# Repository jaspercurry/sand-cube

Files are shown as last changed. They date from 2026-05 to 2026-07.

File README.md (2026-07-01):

# Sand Cube

An AI-assisted, code-CAD speaker enclosure project for an 8 inch FDM-printed,
sand-filled cube using a Dayton Audio Epique E150HE-44 driver and a matching
Epique passive radiator.

This repo is intentionally starting with research and parameters before full
geometry. The goal is to keep every CAD dimension tied to a source, a fit test,
or a measured print.

## Current State

- Research validation notes live in `docs/RESEARCH_VALIDATION.md`.
- CAD import/debugging notes live in `docs/CAD_TROUBLESHOOTING.md`.
- Compact 6 in speaker notes live in `docs/COMPACT_6IN_SPEAKER.md`.
- Shared dimensions live in `params.py`.
- Build123d/Codex working rules live in `AGENTS.md`.
- Current 8.5 in enclosure API lives in `src/final_enclosure.py`.
- Current JMLC horn API lives in `src/final_horn.py`.
- Reusable horn and bracket geometry lives under `src/features/`.
- Archived 203 mm enclosure code lives in `archive/old_enclosure.py`.

## Build Current Enclosure

```bash
uv run python scripts/generate_final_enclosure.py
```

Outputs are written to `build/sand_cube_8_5_black_hole/contoured_inner/`:

- `sand_cube_8_5_black_hole_final_enclosure.step`
- `sand_cube_8_5_black_hole_final_enclosure_with_heat_set_inserts.step`
- `sand_cube_8_5_black_hole_final_enclosure_with_inserts_pr_gx16.step`
- `sand_cube_8_5_black_hole_final_complete_assembly.step`

## Build Full System

```bash
uv run python scripts/generate_final_system_assembly.py
```

Outputs are written to `build/final_system/`:

- `final_jmlc_horn_placed.step`
- `final_horn_bracket_4mm_folded.step`
- `final_binding_post_tpu_grommet.step`
- `final_horn_bracket_de250_stack.step`
- `final_sand_cube_horn_system.step`
- `final_system_notes.json`

## Build Compact 6 In Speaker

```bash
uv run python scripts/generate_compact_6in.py
```

Outputs are written to `build/compact_6in/`:

- `compact_6in_one_piece_enclosure.step`
- `compact_6in_f110m_jmlc_horn.step`
- `compact_6in_f110m_fit_envelope.step`
- `compact_6in_f110m_jmlc_horn_placed.step`
- `compact_6in_horn_f110m_fit_stack.step`
- `compact_6in_system_preview.step`
- `diagnostics.json`

## Build Archived 203 mm Enclosure

```bash
uv run python scripts/generate_archive_old_enclosure.py
```

Outputs are written to `build/archive/old_enclosure/`. This path is for
comparison and reproducibility; new assembly work should use the 8.5 in final
enclosure scripts above.

## View Locally

The repo has two local viewing workflows:

- **OCP CAD Viewer** for live build123d geometry and quick STEP inspection.
- **Open STEP Viewer** or another desktop STEP viewer for exact exported STEP
  review with measurements and section planes before uploading to Onshape.

### OCP CAD Viewer

Install the recommended VS Code extension:

```bash
code --install-extension bernhard-42.ocp-cad-viewer
```

Then start the OCP CAD Viewer from the VS Code/Cursor sidebar. With the viewer
running, show the current final enclosure:

```bash
bash scripts/view_model.sh
```

Useful targets:

```bash
# List available live-geometry and exported-STEP targets
bash scripts/view_model.sh --list

# Show all final enclosure export bodies in one viewer scene
bash scripts/view_model.sh --target final-enclosure-exports

# Show the standalone JMLC horn
bash scripts/view_model.sh --target final-horn

# Import and show the most recently generated STEP under build/
bash scripts/view_model.sh --latest-step --tab clip

# Import a specific STEP file back through OpenCASCADE
bash scripts/view_model.sh build/final_system/final_sand_cube_horn_system.step
```

Inside OCP CAD Viewer, use the **Measure** tools for distances/properties and
the **Clip** tab for section-plane inspection. The script starts in properties
mode by default; pass `--tool distance` to start in distance measurement mode.

### Exported STEP Review

For fast local review of the exact STEP files, install
[Open STEP Viewer](https://openstepviewer.com/) or another desktop STEP viewer
such as FreeCAD/CAD Assistant. The most useful project files to inspect are:

- `build/sand_cube_8_5_black_hole/contoured_inner/`
  `sand_cube_8_5_black_hole_final_complete_assembly.step`
- `build/final_system/final_sand_cube_horn_system.step`
- `build/final_system/final_horn_bracket_de250_stack.step`

Use the desktop viewer for measurements, section planes, and quick import sanity
checks; keep Onshape as the final check for risky horn/adapter topology.

## Render Local PNG Previews

For cleaner renders than the fallback Matplotlib preview, install `f3d` and run:

```bash
bash scripts/render_f3d_previews.sh
```

The PNG files are written to `previews/`.

## Planned Stack

- Python 3.12
- build123d
- bd_warehouse
- OCP CAD Viewer
- Codex as the implementation agent

## First Milestone

Continue consolidating the final geometry out of experiments:

1. Move the 8.5 in enclosure implementation behind smaller feature modules.
2. Keep `experiments/` for visual/profile studies only.
3. Keep current production exports in `scripts/generate_final_*.py`.
4. Add any future hardware placement helpers under `src/`.

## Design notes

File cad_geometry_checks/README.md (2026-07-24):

# CAD geometry checks

`cad_geometry_checks` contains model-independent measurement implementations
that produce immutable results and can feed the existing `cad_verification`
contract. It does not define contracts, policies, evidence packets, model
dimensions, or a second schema.

The package root is native-free. Import `cad_geometry_checks.native` explicitly
inside a `cad_runner` worker to measure Build123d/OCP objects. The native
boundary is duck-typed and delays all kernel ownership to its caller, so
lightweight semantic tests can use fake objects without initializing CAD
libraries.

Every result records:

- the `cad_verification.Unit` for each value;
- named, unit-bearing tolerances;
- an operational diagnostic status;
- a machine-readable failure reason when the result is unusable; and
- a detailed diagnostic suitable for a review packet measurement.

Intersection results additionally preserve the exact Boolean outcome:
bounding-box disjoint, no returned shape, explicit empty shape, zero-volume
contact, positive-volume intersection, or invalid/unexpected topology.
Callers must inspect that outcome before consuming the volume. A missing or
empty member of a multi-solid Boolean fails the whole measurement closed;
partial positive results are never reported as complete.

Collection volume, difference, intersection, and protected-material results use
the geometric material union, so duplicate or overlapping solids are not
double-counted. Topology edge adjacency is occurrence-aware for periodic seams.
Protected-surface comparison samples tessellated topological interiors and trim
boundaries rather than the untrimmed UV rectangle. Edge signatures have
separate millimeter and dimensionless tangent tolerances. Normal change is an
unoriented tangent-plane measurement: opposite normals intentionally compare as
zero degrees.

Frozen normalization results own an immutable tuple, but the native shapes
inside it are borrowed mutable kernel objects. Callers must not mutate those
objects during a measurement.

The coordinated synthetic suite is
`tests/fixtures/cad_geometry_checks_native_fixtures.py`. Its direct entry point
self-routes through `cad_runner` before importing Build123d. It writes only an
ignored diagnostic report under `build/cad-geometry-checks/`.

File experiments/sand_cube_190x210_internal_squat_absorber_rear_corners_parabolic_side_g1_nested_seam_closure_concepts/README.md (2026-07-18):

# Nested-seam closure concepts

This isolated experiment preserves the exact unsplit parabolic enclosure as
the authoritative assembled exterior.  The baffle plug steps inward behind
the original tangent seam, while the bucket retains a continuous outer lip
that conceals the mating taper.  A 0.28 mm hidden fit allowance separates the
socket surfaces, and the existing continuous 5 mm wide, 2 mm thick foam gasket
remains farther inside.

It compares four lower retention concepts while retaining the two hidden top
hooks:

- two concealed 4.8 mm zip-tie loops through sealed dry-side saddles, with the
  tie heads recessed flush into the underside;
- two sacrificial zip latches: each baffle captures an intact tie head, its
  tail runs through a roofed floor tunnel, and a replaceable second ratchet
  head sits in a flush underside clipping pocket;
- two open underside M4 bolt/nut channels, with hardware captured behind
  opposing bucket and baffle collars;
- two reinforced 45 degree dry-side pocket screws with a modeled sealant or
  O-ring annulus at each underside entry.

The loop, bolt, and pocket-screw passages remain ahead of the gasket plane.
The longer sacrificial-latch tail tunnel stays below the gasket loop and has a
modeled 2 mm sealed roof separating it from the enclosure air.  Neither path
crosses the compressed foam seal.

These are mechanism concepts, not final hardware contracts.  Purchased zip
ties, bolts, nuts, inserts, and tool-access dimensions still require fit
coupons before printing a complete enclosure.

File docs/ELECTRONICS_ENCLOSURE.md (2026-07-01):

# Electronics Enclosure

This documents the focused electronics enclosure layout for the hidden
Raspberry Pi 5, DAC HAT, four-channel amp, rear-mounted buck converter, and
rear service connectors.

The active CAD lives in `src/features/electronics.py` as the
`thin_plate_inline_separate_mic` variant. Earlier broad layout studies are
kept in the same file but are archived by `active_layout_variants()`.

## Active Layout

- Overall outside envelope: `166 x 124 x 60 mm`.
- Main box height: `57 mm`; screw-on lid thickness: `3 mm`.
- Orientation convention: the rear service face is `+Y`.
- When facing the rear:
  - Raspberry Pi rear USB/Ethernet ports are on the right.
  - Amplifier and GX outputs are on the left.
  - Buck converter mounts vertically on the outside rear face.
  - Microphone is intentionally external/separate for this iteration.

The active placement is a thin hidden plate intended to fit on a 256 mm square
printer bed while keeping the hardware accessible from the rear face.

## Component Fit

### Amplifier

- Active footprint: `94 x 108 mm`, rotated so the amp heat sink runs
  front-to-back, perpendicular to the rear service face.
- Clearance height: `36 mm`.
- Mounting rectangle:
  - Long axis center-to-center: `101.7 mm`.
  - Narrow axis center-to-center: `88.0 mm`.
  - Hole diameter assumption: `3.0 mm`.
- Printed stand-offs are `3 mm` tall for the current fit pass.

### Raspberry Pi 5 and HAT

- Pi service envelope in this enclosure: `56 x 90 x 42 mm`.
- Pi uses four front-to-back adjustment slots in the floor rather than fixed
  posts. This allows the real board/feet to slide until the USB/Ethernet faces
  land correctly in the rear openings.
- Rear I/O is split into three smaller bays instead of one large bridge:
  - left USB stack
  - middle USB stack
  - Ethernet
- A `10.83 mm` power input hole sits above the Pi rear I/O group, with slight
  vertical relief for FDM ovaling.

The Pi board dimensions and mounting pattern were based on Raspberry Pi 5 and
HAT mechanical drawings. The port windows remain fit-study geometry until the
real Pi/HAT stack and cable overmolds are validated.

### Buck Converter

- Rear-mounted vertical body envelope: `62 x 21 x 58 mm`.
- Rear locating pins:
  - Diameter: `5.8 mm`.
  - Projection depth: `4.0 mm`.
  - Center-to-center spacing: `53.67 mm`.
  - Pin center height: `29.0 mm` above the bottom of the buck body/enclosure.
- Bottom rear wire entry:
  - Width: `17.0 mm`.
  - Height: `3.0 mm`.
  - Through depth: wall thickness plus `5.0 mm`.
  - Internal chamfer: `6 x 6 mm` to reduce wire pinching.

### GX Outputs

- Two GX14-style four-pin output connectors provide four amp channels total.
- Through cutout size: `14.8 x 15.8 mm`.
- Recess size for the measured collar: `19.0 x 19.8 mm`.
- Measured collar OD: `18.06 mm`.
- Recess depth: `1.2 mm`.
- Centers are packed between the rear-mounted buck body and the rear-view left
  inner sidewall to reduce heat-sink interference risk.

## Lid and Printing Details

- Lid is a separate part with four recessed cheese-head screw holes.
- The base has four corner screw receivers:
  - Boss OD: `10.0 mm`.
  - Self-tap pilot diameter: `2.5 mm`.
  - Screw engagement: `2.0 mm`.
  - The receiver uses a short lofted, wall-grown ramp so it does not need full
    height pillars down to the floor.
- Top, side, front, and bottom vents use small print-friendly openings instead
  of long unsupported bridges.
- The fast-fit print variant thins walls/floor/lid to `1.6 mm` and uses a
  faster suggested PLA profile for layout validation.

## Generated Files

Generated CAD and 3MF files are written under `build/electronics_enclosure/`.
`build/` is ignored by git, so regenerate these files after cloning or after
geometry changes.

Main printable 3MF exports:

- `build/electronics_enclosure/thin_plate_inline_separate_mic_base_with_standoffs.3mf`
- `build/electronics_enclosure/thin_plate_inline_separate_mic_screw_on_lid.3mf`
- `build/electronics_enclosure/thin_plate_inline_separate_mic_fast_fit_base.3mf`
- `build/electronics_enclosure/thin_plate_inline_separate_mic_fast_fit_lid.3mf`

STEP exports for inspection:

- `build/electronics_enclosure/thin_plate_inline_separate_mic_printed_enclosure.step`
- `build/electronics_enclosure/thin_plate_inline_separate_mic_electronics_assembly.step`
- `build/electronics_enclosure/thin_plate_inline_separate_mic_base_with_standoffs.step`
- `build/electronics_enclosure/thin_plate_inline_separate_mic_screw_on_lid.step`

## Commands

Generate STEP/layout study files:

```bash
python scripts/generate_electronics_enclosure_layouts.py
```

Generate printable 3MF files:

```bash
python scripts/generate_electronics_3mf.py
```

Open the normal OCP CAD viewer target with the lid separated:

```bash
bash scripts/view_model.sh --target electronics-open-lid --tool distance --tab tree
```

## Open Fit Items

- Validate the Pi rear I/O vertical position with the real removable feet.
- Replace the Pi floor slots with fixed screw holes after the fit position is
  known.
- Re-check GX connector fit after printing because rear-wall circular holes can
  print slightly undersized or oval.
- Validate buck converter noise and wire routing near the amp before treating
  the rear-mounted buck position as final.
- If Bambu Studio reports floating regions, first check the short horizontal
  rear buck pins. They are connected to the rear wall but can look like tiny
  cantilevers to a slicer.

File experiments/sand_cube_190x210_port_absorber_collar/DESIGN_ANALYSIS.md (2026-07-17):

# Project-specific absorber-collar analysis

## Result in one sentence

Use a removable four-sector Helmholtz collar provisionally tuned to 345 Hz at
the lowest accessible part of the straight external tower, begin with all four
chambers identical and damped toward Q=0.75-1, and let the untreated-port
measurement set the final aperture diameters.

The 380 Hz value in the background documents is not used.

## 1. Current port and the unwanted modes

The current round-port experiment gives:

| Quantity | Value |
|---|---:|
| Main bore diameter | 39.2428 mm |
| Main bore area | 1,209.51 mm2 |
| Physical centerline length | 491.369 mm |
| Reported low-frequency effective length | 518.540 mm |
| Net enclosure volume | 4.57012 L |
| Bass-reflex tuning | 39.00 Hz |

The 39 Hz box/port resonance and the unwanted midrange pipe resonances are
different physical modes. The 39 Hz calculation reduces the port air to a
lumped inertance. A longitudinal mode requires distributed acoustic mass and
compliance along the duct.

The simplest open-open estimate is:

```text
f_n = n c / (2 L)
```

With c=343 m/s and the physical centerline, this gives 349.0, 698.0, 1047.1,
and 1396.1 Hz. Reusing the 518.540 mm low-frequency inertance length gives
330.7, 661.5, 992.2, and 1322.9 Hz. The latter is a useful lower bracket, not a
phase-accurate prediction.

The generator also cascades plane-wave transfer matrices for the physical
inlet flare, constant-area path, and outlet flare:

```text
             [ cos(kl)       j Zc sin(kl) ]
T_segment =  [                              ]
             [ j sin(kl)/Zc      cos(kl)   ]

Zc = rho c / S
```

It terminates the mouth with a low-ka unflanged radiation approximation. That
model predicts untreated peaks near 350.5, 700.0, 1048, and 1394 Hz. A variant
including a finite inlet spreading mass predicts about 344, 681, and 1019 Hz.
Both exclude driver electro-mechanics, detailed bend fields, thermoviscous
propagation, and flexible printed walls.

The defensible pre-measurement conclusion is therefore:

- search approximately 315-365 Hz for the first port mode;
- use 345 Hz as the mechanical prototype center;
- expect a second port feature around 0.66-0.70 kHz; and
- do not assume a 0.99-1.05 kHz feature is only the port.

The enclosure's first simple axial estimates are about 933 Hz in depth and
974 Hz in width/height, overlapping the third port band. Printed-wall radiation
can further confuse that region. The circular duct's first transverse cutoff
is around 5.1 kHz, so a 1D longitudinal model is appropriate for the bands of
interest even though the bends still perturb it.

## 2. Absorber equations

Each chamber is represented as a series acoustic RLC branch connected in shunt
to the main duct:

```text
Z_H = R_H + j (omega M_H - 1/(omega C_H))
Y_total = sum(1/Z_H,i)

M_H = rho Leff / A
C_H = V / (rho c^2)
f_H = c/(2 pi) sqrt(A/(V Leff))
```

The shunt transfer matrix is:

```text
      [ 1   0 ]
T_H = [       ]
      [ Y   1 ]
```

For a series resonator:

```text
Q = omega_H M_H / R_H = sqrt(M_H/C_H) / R_H
R_H = sqrt(M_H/C_H) / Q
```

The final relation is important: Q is in the denominator. The thesis prints
one equation with Q inverted, but its later numerical examples use the inverse
relationship above.

Four identical chambers have four admittances in parallel. If their volumes,
areas, and losses are equal, their center frequency remains unchanged while
their total shunt strength increases.

## 3. Neck length and end correction

The physical neck is 8.0 mm long and grows only outward from the unchanged
39.243 mm bore. For a small circular aperture in a locally planar wall, the
first estimate is:

```text
Leff = t + delta_duct + delta_cavity
delta_duct = 0.85 r
delta_cavity = 0.85 r
Leff = t + 0.85 d
```

The actual opening is flush in a curved finite duct and enters a sector-shaped
cavity rather than two infinite half-spaces. No transferable correction for
that exact geometry was found in the thesis. The generator therefore carries:

```text
Leff = t + beta d,  beta = 0.85 nominal, 0.70-1.00 sensitivity range
```

The neck radius is about 10% of the main-port radius, so local planarity is a
reasonable starting assumption, but measurement is still required.

## 4. Provisional dimensions

The generated default is:

| Feature | Nominal value |
|---|---:|
| Collar outside diameter | 100.0 mm |
| Axial length | 30.0 mm |
| Unchanged main bore | 39.2428 mm |
| Existing tower wall | 5.0 mm |
| Local physical neck/liner | 8.0 mm |
| Outer wall | 3.0 mm |
| Integral chamber floor | 3.0 mm |
| Bonded lid | 3.0 mm |
| Radial dividers | 2.4 mm |
| Chamber count | 4 |
| Gross volume per chamber | 26.141 cm3 |
| Damping displacement allowance | 0.250 cm3 |
| Net acoustic volume per chamber | 25.891 cm3 |
| Target per chamber | 345.0 Hz |
| Solved round neck diameter | 3.853 mm |
| Neck area per chamber | 11.659 mm2 |
| Effective neck length | 11.275 mm |
| Total neck area / main port area | 3.86% |

For each chamber at c=343 m/s and rho=1.204 kg/m3:

```text
M_H = 1164.3 Pa s2/m3
C_H = 1.8278e-10 m5/N
R_H(Q=1) = 2.524 MPa s/m3
R_H(Q=0.75) = 3.365 MPa s/m3
```

The numerical values in `diagnostics.json` come from the actual CAD cavity
volumes rather than an ideal annular-volume approximation.

## 5. Why four equal chambers first

| Architecture | Benefit | Drawback | Decision |
|---|---|---|---|
| One shared annular cavity | Maximum volume, few dividers | One leak or print defect compromises everything; no tuning experiments | Rejected for prototype |
| Four identical sectors | Maximum first-mode shunt strength; inspectable and fault-isolated | Requires a bonded divider seal | Selected |
| Four blindly staggered sectors | Broader nominal frequency coverage | Less admittance at the measured peak; may create shoulders | Defer until measurement |
| Two axial collars | Can address even and odd modes at their own antinodes | More volume, joints, flow openings, and mechanical complexity | Only if one location cannot solve measured modes |
| Membrane chambers | Potentially compact | Printed stiffness and boundary conditions make tuning unreliable | Rejected |

The thesis' coupled simulation favored absorber Q around 0.75-1. An isolated
resonator at Q=1 is already broad; the coupled notch width is not simply the
isolated resonator's -3 dB width. Staggering before measuring the untreated
port would trade away useful peak coupling based on an assumed problem.

The four sectors preserve the option to test a 2+2 split near 0.97f1 and
1.03f1. If the second mode remains objectionable, a separate smaller chamber
near f2 is preferable to giving a full 26 cm3 sector an unnecessarily large
opening.

## 6. Placement

The first-mode pressure maximum is near the acoustic midpoint, around 246 mm
from the inlet in the current TMM. That location lies in the curved upper
return with poor radial clearance.

The collar is instead centered 358.26 mm from the inlet, corresponding to
global z=110 mm and a z=95-125 mm span on the straight external tower. The
calculated pressure ratios relative to each mode's own maximum are:

| Mode | Bare modeled peak | Pressure at collar |
|---|---:|---:|
| First | 350.5 Hz | 0.752 (-2.47 dB) |
| Second | 700.0 Hz | 0.991 (-0.08 dB) |
| Third | 1048 Hz | 0.546 (-5.26 dB) |

This is a useful compromise: strong first-mode coupling, almost ideal
second-mode coupling, a straight printable host, access for testing, no
enclosure displacement, and clearance below the DE250 envelope.

## 7. Predicted effect and what not to overclaim

With four ideal Q=1 branches at 345 Hz, the lossless TMM predicts about 32 dB
reduction at its untreated first peak and about 19 dB at its untreated second
peak. It also shifts the residual response maxima because a resonant shunt
splits and reshapes the duct response.

Those are design-model numbers, not promised measurements. The model does not
include real duct loss, neck nonlinearity, mesh repeatability, bend scattering,
driver coupling, wall vibration, or cabinet radiation. Hildebrandt measured
about 19 dB attributable suppression in the cleaner configuration, which is a
better reality check than the ideal 32 dB result.

The same model moves the low-frequency coupled peak from about 39.28 to
39.25 Hz, a -0.03 Hz relative shift. The exact driver/port system still needs
an impedance and nearfield check, and 39 Hz output must be compared as well as
the frequency.

External placement displaces no box air. If this 100x30 mm envelope were put
inside around the existing 49.243 mm tower, its added gross envelope would
remove about 178.5 cm3 from the 4.570 L enclosure. Ignoring side-branch
compliance, that alone would move 39.00 Hz to roughly 39.78 Hz. An internal
version therefore requires complete volume and tuning recalculation.

## 8. Tolerances

For small changes:

```text
df/f ~= dc/c + dd/d - 0.5 dV/V - 0.5 dLeff/Leff
```

Because Leff also contains diameter-dependent end correction, the generator
recalculates rather than using only this differential approximation.

| Change from nominal | Predicted fH |
|---|---:|
| Neck diameter -0.15 mm | 333.46 Hz |
| Neck diameter +0.15 mm | 356.42 Hz |
| Physical neck -0.20 mm | 348.10 Hz |
| Physical neck +0.20 mm | 341.98 Hz |
| Cavity volume -5% | 353.96 Hz |
| Cavity volume +5% | 336.69 Hz |
| Speed of sound 340.3 m/s | 342.28 Hz |
| Speed of sound 349.0 m/s | 351.03 Hz |
| End beta=0.70 | 354.20 Hz |
| End beta=1.00 | 336.48 Hz |

Diameter and end correction dominate. Print the opening slightly undersize and
finish it with a measured drill or reamer. A controlled +/-0.05 mm aperture is
more useful than false precision in the CAD nominal.

## 9. Leakage and damping

Treat a cavity leak resistance as parallel with cavity compliance. Keeping the
compliance error near resonance below roughly 5% requires:

```text
omega R_leak C_H > 20
```

For one generated chamber this gives R_leak greater than about 50.5 MPa s/m3,
or a plugged-neck pressure-decay time:

```text
tau = R_leak C_H > 9.23 ms
```

The practical target is at least 50 ms for margin. Test each chamber before
installing it. A leak with its own inertance can also create an unintended
second resonance, so a visibly closed seam is not enough evidence.

Use a captured woven polyester acoustic mesh or another repeatable resistive
fabric on the cavity side of each neck. Bond its perimeter so no fiber can
reach the main airway. Do not loosely stuff the whole chamber: bulk fill alters
effective volume/compliance as well as resistance. The acoustic resistance
must be inferred from the measured collar Q; cloth type and layer count are
calibration variables.

## 10. Measurement-driven finalization

1. Measure the untreated mouth 5-10 mm away with a low-level 20-2000 Hz sweep.
2. Add a temporary 20 mm outlet extension. A 345 Hz pipe mode should fall by
   approximately 3-4%, while a cabinet or panel mode should not track length.
3. Measure electrical impedance and port nearfield together to confirm 39 Hz.
4. Fit the distributed model to measured f1, f2, and their widths.
5. Test four undamped equal chambers first to establish the real collar center.
6. Correct frequency by measured aperture diameter or cavity-volume plugs.
7. Add captured mesh incrementally and fit R_H/Q from the response and decay.
8. Test 2+2 staggering only if the untreated or residual band is broad.
9. Recheck box tuning, 39 Hz level, resonance decay, and electrical impedance.
10. Increase level in steps to expose neck turbulence, nonlinear resistance,
    distortion, compression, or resonance shift.

## References

- [Malte Hildebrandt, *Dämpfung stehender Wellen in Bassreflexrohren* (2024)](https://reposit.haw-hamburg.de/bitstream/20.500.12738/16061/1/BA_D%C3%A4mpfung_stehender_Wellen.pdf)
- [U. Ingard, *On the Theory and Design of Acoustic Resonators*](https://doi.org/10.1121/1.1907235)
- [H. Levine and J. Schwinger, *On the Radiation of Sound from an Unflanged Circular Pipe*](https://doi.org/10.1103/PhysRev.73.383)
- [M. R. Stinson, *The Propagation of Plane Sound Waves in Narrow and Wide Circular Tubes*](https://doi.org/10.1121/1.400379)

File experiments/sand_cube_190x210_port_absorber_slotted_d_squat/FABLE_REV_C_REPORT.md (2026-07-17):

# Fable independent analysis — Rev. C (preserved source report)

> **Provenance and status:** This report was generated independently with
> Fable and supplied by Jasper Curry. It is preserved substantially verbatim as
> an external analysis. It is an important input to the project, not the
> canonical design authority. Numerical claims become canonical only after they
> are reproduced by the repository models and reconciled with measurement.
>
> The four scripts named near the end of the supplied report were not included
> with the source text. This repository is independently implementing auditable
> versions of those models and will not assume their unpublished results.

# Port-Mode Slit Absorber — Independent Analysis & Design Rules (Rev. C)

Independent third opinion, with my own numerical models (full thermoviscous slit impedance validated against the Poiseuille and 6/5-mass-factor limits, plus a 1D transmission-line model of the actual 513.6 mm port with the branch inserted) and two verification research passes (end-correction literature incl. the open-access Aulitto TU/e thesis and the Hildebrandt PDF read directly; micro-tooling market survey).

---

## 1. The verdict, and the one thing both previous documents missed

**Build it as drawn. But the reason it will work is not the reason either document gave.**

Both Rev. A and Rev. B modeled the slit as a nearly-lossless mass (the "Q = 3.62 boundary-layer trend") and then argued about how precisely you must tune it. When you solve the **full thermoviscous channel impedance** for a 0.40 mm × 5 mm-deep passage at w/δᵥ = 3.35, two things change:

1. **The oscillating air in the channel is ~19% heavier than bulk air** (Re(ρ_eff)/ρ = 1.193 at 335 Hz — a standard result of the parallel-plate Crandall/Maa solution, which neither document applied to the mass term). The as-drawn part therefore tunes near **292–309 Hz**, not 334.7 Hz, before any end-correction argument even starts.
2. **The channel resistance is roughly twice the duct's characteristic impedance** (R_branch ≈ 6.7×10⁵ Pa·s/m³ vs Z₀ = ρc/S_duct = 3.3×10⁵). Intrinsic branch Q ≈ **2.0–2.2**, not 3.6.

That second point flips the whole engineering posture. At R/Z₀ ≈ 2 the absorber is a **heavily damped side-branch damper**, not a sharp notch filter. Its own bandwidth is ~165 Hz. My duct simulation (branch at the antinode, mode at ~331 Hz) shows:

| Branch condition | Worst residual peak vs bare mode |
|---|---|
| Perfectly tuned, as-drawn R | −25.6 dB |
| Detuned **−10%** | −25.8 dB |
| Detuned +10% | −22.3 dB |
| **Built exactly as drawn, zero tuning** (f₀ lands 292–309 Hz vs mode 331) | **−25 to −27 dB** |
| Slit width anywhere 0.35–0.50 mm (V untouched) | −23.4 to −25.9 dB |
| Edges fully rounded vs ideally sharp | −25.8 vs −25.9 dB (no difference) |
| Placed at the tower (x = 400 mm) instead of the antinode | −23.1 dB |

Re-run with 4× wall losses (bare mode Q ≈ 27, more like a real bent port): everything compresses to −14…−17 dB but the *flatness* is identical — as-built no-tuning is still within ~1 dB of perfectly tuned, and width 0.35–0.50 mm still all works. (Absolute dB values are comparative — my 1D model straightens the bends and ignores 3D effects — but the flatness conclusions depend only on R/Z₀ and the branch bandwidth, which are robust.)

**Consequences, stated bluntly:**

- The **irreversible-tuning anxiety is over-engineered**. Rev. B's displacement-plug system, Rev. A's "measure-then-lengthen" ritual, the ±0.03 mm feeler-gauge metrology, the sharp-edge "build requirement" — all of these solve a precision problem this design does not have. Deep channel (t/w = 12.5) + low porosity put you on a **flat plateau** roughly ±12% wide in frequency and ±0.07 mm wide in slit width.
- Rev. B's "print the bucket at 62 cm³ and plug down" points the **wrong direction anyway**: viscous mass loading plus the larger slit end correction mean the as-drawn part lands *low*. If you tune at all, you'll be *removing* volume (raising f₀), so the drawn 53.3 cm³ is already the "oversized" end of the range. My solve for exact tuning to 335 Hz gives V ≈ **40–46 cm³** depending on the end-correction scenario.
- Rev. B's sharp-edge obsession is misplaced *for this geometry*: the resistive end correction (Aulitto fit: 0.425·w ≈ 0.17 mm per side) is ~7% of the 5 mm channel's distributed resistance. Edge condition matters enormously for thin plates (t ≈ w); it is nearly irrelevant at t = 12.5w. Don't butcher the edges, but don't build a religion around them.
- Rev. B's Q-correction ("higher Q = deeper notch, so Q 3.6 is fine") is right about notch depth and wrong about what you should optimize. The correct objective is **worst residual peak**, and it's maximized at R/Z₀ ≈ 1.5–3 (my sweep: −25.6 dB at R/Z₀ = 2–3, degrading to −13.8 dB at R/Z₀ = 0.3 because the mode splits into two lightly-damped shoulders, and to −20 dB at R/Z₀ = 6 because the branch stops accepting flow). **The drawn design happens to sit at the optimum.** That is the single luckiest — or best — feature of this design.

---

## 2. The design rules you asked for

These are the formulas to size any future variant, with validity limits.

**Rule 1 — Resistance target (the master rule).**
Size the slits so that at resonance

> **R_branch / Z₀ ≈ 1.5–3**, where Z₀ = ρc/S_duct (= 3.29×10⁵ Pa·s/m³ for your 40 mm bore)

R_branch = Re[jωρ_eff·t/S_total]·(1 + 2δ_res/t), with the full parallel-plate solution
ρ_eff(ω) = ρ / [1 − tanh(β)/β], β = (w/2)√(jω/ν), ν = μ/ρ ≈ 1.50×10⁻⁵ m²/s.
Validity: slit aspect ≥ ~6:1 (yours is 18:1), kw ≪ 1.
Practical corollary: for a channel ~10 slit-widths deep, R/Z₀ lands in this window when **w/δᵥ ≈ 2.5–4** and total open area is ~0.5–1.5% of the bore. δᵥ = √(2ν/ω) = 0.120 mm at 335 Hz. Your 0.40 mm at w/δᵥ = 3.35 is centered in the window.

**Rule 2 — Tuning.**
f₀ = (c/2π)·√(S_total / (V·L_eff)), with
> **L_eff = t·Re(ρ_eff)/ρ + 2δ_in**

The viscous mass factor Re(ρ_eff)/ρ: 1.20 (w/δᵥ→0), **1.19 at w/δᵥ=3.3**, 1.09 at w/δᵥ=6, →1 for w/δᵥ→∞. Do not omit it — it alone is a −5% frequency shift here.
δ_in per side for an isolated low-porosity slit (Aulitto thesis, TU/e 2023, p.19, low-Sh forms): δ_in/w ≈ (1 − ln 4Φ)/π to −2.17 + 2.18·Φ^−0.13, giving **δ_in ≈ 0.55–0.74 mm per side** at your effective porosity — i.e. total ≈ 1.1–1.5 mm, roughly double the provisional 0.651 mm. (The classical periodic-array log formula explodes at Φ = 0.9% and is inapplicable — the divergence is an artifact of infinite tiling.) Note Aulitto's fits are technically below your shear number, so treat δ_in as a **0.33–0.75 mm/side bracket** to be closed by measurement.
Corollary: as-drawn f₀ ≈ 292–309 Hz. To sit at 335 Hz exactly: **V ≈ 40–46 cm³**. But per Rule 4 you likely won't need to move it.

**Rule 3 — Depth.**
Keep **t/w ≥ 10**. Deep channels put the loss in the distributed viscous term, which (a) achieves Rule 1 without meshes or wool, (b) makes edge radius, taper, and roughness second-order, (c) makes nonlinear detuning small (only the end correction, ~11% of L_eff, is amplitude-sensitive → ~+3% max shift — Rev. B got this right). Your 5.0 mm on 0.4 mm is t/w = 12.5. Good. Don't thin it.

**Rule 4 — Tolerance budget (what actually matters, in order).**
1. **Nothing at first order.** Within w = 0.35–0.50 mm, f₀-error ±12%, V ±20%, placement 0.25L–0.75L, edge condition anything reasonable → all within ~3 dB of optimum. Aim for w = 0.40 ± 0.05 mm and move on.
2. What *can* hurt: w < 0.30 mm across a whole slit (R/Z₀ > 4.5, −20 dB → costs 6 dB) — fused pilots are the main risk, so the post-finishing pass is about **opening fused slots to ≥0.35 mm**, not about hitting 0.400 sharp.
3. **Chamber leaks** — the one un-modeled failure mode with real teeth. A leak is a parallel low-resistance branch that both detunes and shorts the cavity. Gasket integrity beats slit metrology. Leak-test the sealed bucket (block slits with tape, apply gentle pressure, listen/soap-film) before any acoustic test.
4. Temperature: −0.6 Hz/°C, tracks the duct mode. Ignore.

**Rule 5 — Placement.**
Coupling ∝ sin²(πx/L), but with R/Z₀ ≈ 2 the penalty is compressed: tower (0.41 coupling) costs only 2.5 dB in the smooth model, ~4 dB in the lossy model. **Put it wherever it's easiest to build and seal — the tower is fine.** Fighting the 67° bend for the last 2–4 dB is bad ROI on a first article. (Rev. B's two-half-units idea: real but small — skip for v1.)

**Rule 6 — Volume as the trim knob (kept from Rev. B, direction corrected).**
f ∝ 1/√V. Print the bucket at the drawn 53.3 cm³ and design the lid for **adding** displacement plugs (up to ~15 cm³ → +15% f₀). This is the reversible trim if measurement ever shows you need it; expect not to use it.

---

## 3. Nonlinearity — the finding nobody had

Both documents argued about nonlinear behavior *at 335 Hz*. The louder mechanism is **at 39 Hz**: at reflex tuning the port carries large volume velocity, and the pressure standing across the branch at mid-port is ~ωρ·u_port·x. My estimate:

| Port velocity (39 Hz) | Pressure at slits | Slit velocity | Strouhal ωw/u |
|---|---|---|---|
| 5 m/s (loud) | ~380 Pa (143 dB) | 3.2 m/s | 0.031 |
| 10 m/s (very loud) | ~760 Pa (149 dB) | 6.3 m/s | 0.016 |
| 20 m/s (limit) | ~1520 Pa (155 dB) | 12.6 m/s | 0.008 |

St ≪ 1 → the slits are **fully jetting on loud bass**, even though the absorber is far below its resonance. Consequences: the branch flow is <1% of port flow, so the **39.12 Hz alignment is untouched**; the jets dissipate a little energy (harmless); but four 0.4 mm slits pulsing at 3–13 m/s may generate **audible broadband hiss/buzz on bass transients** (Re ≈ 90–350, so likely faint, but unverified). Add to the test plan: loud 35–45 Hz sine, ear/mic at the module. If it hisses, the fix is more slit perimeter at lower velocity (e.g. 6 slits) or slightly wider slits — both stay inside the Rule-1 window.

At 335 Hz the branch self-limits: velocity rises → resistance rises (Aulitto 2022, Eq. 6, ΔR ≈ (4/3π)ρu/C_v², C_v = 0.82) → moves from R/Z₀ = 2 toward 4 → costs ~2 dB. Detuning ~+3% max. Non-issue.

---

## 4. Literature cross-check (what the subagents verified)

- **Hildebrandt thesis read directly** (HAW PDF): 123 cm³ common chamber (p. 29), four 50×0.2 mm slits = 40 mm² (p. 30), simulated 653 Hz / measured 675 Hz (Fig. 3.14, 5.3), target Q = 1, as-built Q = 3.25 (p. 29), ≈19 dB reduction bare / +7 dB with foam (Figs. 5.3–5.4). No wool in the built chambers — geometric resistance only, common cavity. His numbers check out and his w/δᵥ = 2.4, t/w = 10 puts him in the **same damping-dominated regime** — independent confirmation that this class of device delivers ~19 dB in real hardware despite a 3.4% tuning miss. That miss costing him nothing is exactly the flat-plateau behavior my sims predict.
- **Aulitto TU/e thesis (open access)**: end-correction forms quoted in Rule 2; resistive correction δ_res/w = 0.425, porosity-independent, edge-dominated; inertial correction porosity-dependent, log-divergent for isolated slits. Her high-shear-number corrections (Eqs. 2.27–2.29, the regime you're actually in) were not extracted — read pp. 27–29 if you ever need the last few percent; you don't for v1.
- **Ingard 1953** (via Selamet & Radavich): cavity-side correction δ ≈ 0.85(d_c/2)(1 + 1.25 d_c/d_v) — circular geometry, direction only.
- Caveats: Aulitto JASA 2021 itself is paywalled (thesis used instead); Maa 2000 primary not directly read; Ingard & Ising 1967 not retrievable. Nothing critical rests on these.

---

## 5. Manufacturing: the tooling answer

**Do not buy 0.4 mm end mills.** The subagent's market survey: no commercial 0.4 mm carbide end mill has anywhere near 5 mm of flute (typical usable flute at that diameter is 0.5–1.5×D; 5 mm depth is a 12.5:1 ratio that doesn't exist as a catalog item). Cheap "0.4 mm" AliExpress/uxcell PCB bits (~$10/10 pc) are taper-ground isolation-routing tips with <0.5 mm of cut. And without a rigid CNC, drill-press/Dremel runout (0.05–0.15 mm) is 12–40% of the tool diameter — guaranteed breakage. This option is closed; stop considering it.

**What to use instead, ranked:**
1. **Jeweler's/piercing saw, #5 blade — kerf ≈ 0.40 mm** (blade size charts: #0 = 0.28, #5 = 0.40, #9 = 0.55 mm). Saws a straight, sharp-edged 0.4 mm kerf through 5 mm of plastic; reaches through a printed pilot slot; a saw frame + blade assortment is ~$20–40. This is your primary sizing tool and it is almost comically well-matched to the job.
2. **Diamond lapping film (~$15–40 assortment) glued to a 0.30–0.35 mm feeler blade** — final calibration/cleanup after sawing, sneaking up by film-thickness increments.
3. Cutting broaches (0.4→0.7 mm taper, ~$80 set) — touch-up only; the taper widens the entrance if pushed deep. Needle files are too wide (≥0.5 mm) to fit the slot.

**Feeler gauges (yours, incoming):** blades are ~12.7 mm wide vs your 7.2 mm slot — they **cannot pass through**; you'll gauge with a tip corner, which checks entrance width only and will miss an hourglass profile deeper in. Two fixes: grind one 0.40 blade to ~5 mm width as a through-going GO gauge, and keep an unmodified 0.45 as NO-GO at the entrance. Check a cheap set's 0.40 blade against a micrometer first (quality blades hold ±0.01–0.02 mm; unbranded can be several× worse). Given Rule 4, ±0.05 mm acceptance is fine — the gauges are go/no-go references, not the precision bottleneck the previous documents made them.

**Printing:** 0.30 mm pilots below the 0.4 mm line width will partly fuse — expected; they're saw guides, not slots. The curved 4-orientation coupon is still worth one print: what you're learning is *which orientations fuse worst*, not chasing ±0.03 mm. FDM negative features print 0.1–0.3 mm undersize (community consensus; maker projects like `juliendorra/3D-printable-sound-absorbers` default to 0.8 mm perforations precisely because sub-0.5 mm FDM slots are unreliable) — the pilot-then-finish plan is right. A 0.2 mm nozzle (~$21, exists for X2D) would shrink finishing stock but not eliminate finishing; optional.

---

## 6. First-article spec and test plan

**Build (one part, this week):**
- Slits: 4 × nominal 0.40 mm × 7.17 mm × 5.0 mm deep — **as drawn**. Acceptance: every slit passes 0.35 GO through full depth, refuses 0.45 at entrance. Edges: neat, not fetishized.
- Cavity: 53.3 cm³ **as drawn**; lid designed to accept stick-on displacement plugs (provision for ~15 cm³ total).
- Location: **tower** (or as close to the bend as prints cleanly — either is fine per Rule 5).
- Gasket sealed; **leak-test before acoustic test** (tape over slits, pressurize gently, soap film).

**Measure (in order, same mic position, fixed drive):**
1. Bare port (no module): find the real mode — expect ~325–340 Hz. This calibrates everything; it does *not* gate the build.
2. Port + module with slits taped over: isolates the module body's effect on the pipe (geometry control).
3. Port + module active: expect the ~330 Hz peak to drop 10–25 dB depending on the port's real bare Q. Sweep + decay spectrogram.
4. If (and only if) the residual peak sits >5 dB above the plateau my sims predict, check for leaks first, then trim: measured f₀ too low → add plugs (each cm³ ≈ +1%·f₀/2 ≈ +3 Hz); too high (unlikely) → you have 53.3−40 ≈ 13 cm³ of headroom already built in… meaning you'd remove plugs you didn't install — in that corner case, extend one pair of slits with the saw (+length raises f₀, √-slowly, ~+10 Hz per +1 mm across all four).
5. Level series: 80/90/100 dB sweeps (linearity at 335 Hz) + loud 39 Hz sine (listen for slit hiss; verify reflex alignment unchanged via impedance or near-field port output at 20–60 Hz).

**What would change my verdict:** measured bare mode outside 290–380 Hz (re-derive); residual peak stuck >8 dB above prediction after leak-check (then the 3D bend/branch interaction is doing something my 1D model can't see — that's when a second unit at the other sin²-favorable location earns its keep); audible slit noise at bass levels (widen/add slits per §3).

---

## 7. Scorecard vs the two prior documents

| Question | Rev. A | Rev. B | This analysis |
|---|---|---|---|
| As-drawn tuning | 334.7 Hz nominal, worry ±7% | same, tune-by-volume upward | **292–309 Hz** (viscous mass + slit end correction, both omitted before) — and it doesn't matter |
| Intrinsic Q | 3.62 as bound | 3.62 as trend | **≈ 2.0–2.2** from full solution |
| R vs Z₀ | not computed | not computed | **≈ 2× — accidentally optimal** |
| Tuning precision needed | high (irreversible dread) | medium (plug system) | **low: ±10% ≈ 2 dB** |
| Sharp edges | caution | build requirement | **second-order at t/w = 12.5** |
| Placement | antinode critical | antinode vs 2 halves | **tower fine (−2…−4 dB)** |
| Cavity 53 cm³ | "too small" | "matched, keep" | keep; exact-tune value is 40–46 cm³, plateau makes it moot |
| Nonlinearity | √2 walk-off (wrong) | +3% at 335 Hz (right) | +3% at 335 Hz **plus the real one: 39 Hz slit jetting / possible hiss** |
| 0.4 mm end mills | — | — | **don't exist at 5 mm flute; jeweler's saw #5 = 0.40 mm kerf is the tool** |

*Models and scripts: `model.py`, `duct.py`, `verify.py`, `robust.py` (validated against Poiseuille and low-frequency mass limits; duct model is 1D lossy TMM with box compliance and unflanged radiation; absolute dB comparative, sensitivity conclusions robust).*

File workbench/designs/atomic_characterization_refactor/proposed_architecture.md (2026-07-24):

# Implemented module tree and ownership

Status: implementation, final strict acceptance, exact visual evidence and
independent adversarial re-review complete. A separately authorized post-
refactor Variant R correction now owns the accepted no-splice flat bottom;
Variant I still has no geometry.

```text
src/enclosure_family/
├── datums.py                  # family coordinate contract
├── legacy_runtime.py          # serialized, exactly restored legacy binding
├── print_contracts.py         # shared print-contract schema only
├── variant_r/
│   ├── parameters.py          # Variant R dimensions/tolerances
│   ├── print_contracts.py     # bucket and baffle print metadata
│   ├── seam.py                # sculpted L/R/T plus flat-bottom perimeter
│   ├── bottom_ownership.py    # baffle-only planar sole trim; historical helpers inactive
│   ├── foundation.py          # explicit legacy foundation dependency bundle
│   ├── assembly.py            # independent Variant R composition owner
│   ├── inputs.py              # authoritative generated-input contract
│   ├── historical_capture.py  # immutable accepted-base capture recipe
│   ├── provenance.py          # producer/source/tool attestation
│   ├── release_provenance.py  # post-geometry release attestation writer
│   ├── measurements.py        # deterministic native geometry facts
│   ├── equivalence.py         # native-free numerical acceptance predicates
│   ├── export.py              # STEP publication and round-trip adapter
│   ├── artifacts.py           # required output identities
│   ├── verification.py        # evidence dimensions and tolerances
│   └── model.py               # one explicit owner per Variant R boundary
└── variant_i/
    └── interface.py           # independent future-only boundary; no geometry

scripts/
├── generate_variant_r.py      # thin coordinated immutable-base producer
└── run_historical_variant_r_base_capture.py

workbench/designs/atomic_characterization_refactor/
├── attest_variant_r_release.py       # observational release-source probe
├── package_variant_r_review.py       # attested visual assembly adapter
└── project_variant_r_attestations.py # native-free committed audit projection
```

The active geometry leaf is retained as a compatibility adapter while the
accepted construction foundation is reproduced from exact commit `789cf7f`.
It no longer owns parameters, seam policy, lower material composition,
retention alternatives, evidence policy or artifact publication. Its remaining
deep ancestry and visible serialized temporary bindings are contained behind
the explicit immutable foundation producer and `VariantRFoundation`; new owners
import no experiment module. Removing that inherited binding mechanism requires
a separate cascade rewrite and is not represented as complete in this landing.
For the landed compatibility path, one in-process `RLock` surrounds
apply/use/restore, restoration is identity-checked and unit-tested, the release
diagnostics prove two identical build fingerprints with two successful
restorations, and coordinated production is limited to one CAD worker.

## Family and variant boundaries

The family layer owns only the proven 190x210 coordinate semantics and neutral
print-contract schema. It does not merge this design's 2/3/2 wall stack with
the repository's unrelated 203 mm 3/12/3 legacy contract.

Variant R independently owns the accepted removable-baffle composition. The
continuous exact-edge donor owns bucket, gasket and visible baffle apron; only
the baffle sub-sole is trimmed. The exact twelve internal bucket-only
micro-omissions are a fail-closed authorized geometry delta, not equivalence or
tolerance widening. Retention geometry is explicitly absent. No flag-driven
alternate Variant R/I generator remains.

Variant I owns only a future interface contract for a monolithic front,
open-bottom body and future hatch owner. Calling its geometry owner raises
`NotImplementedError`; it imports no Variant R module and cannot route future
geometry through the removable-baffle implementation.

## Verification and publication boundaries

Builders return shapes and deterministic build metadata. Measurement consumes
shapes without publication. Native-free equivalence policy consumes measurement
records. The workbench comparison scripts are evidence adapters only. STEP
publication and reimport live in `variant_r/export.py`; model entrypoints remain
thin and resource-coordinated. `.cad-project/models.toml` remains the sole model
catalog.

The authoritative foundation producer publishes only the base STEP and its
attestation. A clean checkout obtains the exact accepted input by archiving the
immutable geometry commit, applying the committed capture-only overlay at the
accepted build boundary, verifying the complete STEP DATA payload, and
canonicalizing only the accepted `FILE_NAME` timestamp. The real job time stays
in the attestation. Release evidence runs after geometry in a separate
coordinated process so evidence allocation cannot perturb the serialized legacy
build. Separate committed producer and release closure projections record every
loaded dependency, the exact release commit and job JSON, and all nine model
artifact hashes rather than relying on ignored `build/` artifacts. The release
job predates whole-tree-state recording, so the projection truthfully verifies
every dependency byte at the commit without claiming an unrecorded clean tree.

## Post-refactor geometry status

The narrowly scoped flat-bottom correction is complete in
`workbench/designs/variant_r_no_splice_production/`. Historical no-geometry-
change refactor evidence remains intact and is superseded only for the current
Variant R bottom-ownership boundary. Horn, tube, resonator, bracket,
electronics, supports, hatch, hinge and fastener work remain separate.

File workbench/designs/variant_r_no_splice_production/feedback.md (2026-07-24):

# Variant R production no-splice correction feedback

## 2026-07-24 — preflight and accepted specification

- Verified the fresh worktree started clean at
  `5ec998069b790d648a011d04a2dadb6dc1d8b9e3`, exactly matching
  `origin/main`; created branch `codex/variant-r-no-splice`.
- Read the repository CAD skill and all required iteration, visual, toolchain,
  model-catalog and geometry references, plus the applicable repository and
  workbench `AGENTS.md` files.
- Pinned Build123d `0.11.1`, `cadquery-ocp-novtk` `7.9.3.1`, Build123d-MCP
  `0.3.79` and the model catalog pass. Doctor is blocked only by the missing
  ignored Text-to-CAD checkout in this fresh worktree; it will be restored at
  pinned commit `fdbb4b4fb62d95ae298cfe9a46fdc7092bdaf423` before artifact work.
- Read commit `5f5bbf3c2aca0f55f35ae734c8dc0c6004897f75` and every file under its
  `workbench/designs/variant_r_underside_seam_refinement/` tree through Git.
- Accepted construction evidence: use the exact-edge donor already returned by
  the production foundation, leave bucket and gasket untouched, trim only the
  baffle to the parameter-owned `Z=-91.495 mm` sole, and discard the
  approximately `0.355323 mm` sub-sole band. The candidate expectation is 91
  baffle faces, 257 baffle edges, zero old-splice and unrelated lower-apron
  edges, not a topology-identity claim.
- No source or catalog geometry owner has changed yet.

## 2026-07-24 — localized owner implementation and native-free gate

- `assembly.py` now uses the foundation's continuous exact-edge donor directly,
  leaves donor bucket and gasket untouched, and invokes one baffle-only sole
  trim. The active composer no longer calls either historical whole-part splice
  or lower material-transfer helper.
- `bottom_ownership.py` owns one exact half-space intersection with no explicit
  clean/fix, same-domain unification, splitter removal, healing or tolerance
  widening. Its audit records the removed band and those disabled operations.
- `parameters.py` now owns the single production sole datum
  `baffle_planar_sole_z_mm = -91.495`; the former print-bed property is a
  compatibility alias to that datum. The print contract and current model
  boundary use the same source.
- The historical splice/transfer helpers remain available only for old
  workbench provenance; they are not imported or called by the active composer.
- Focused native-free tests passed `39/39`. The authoritative lightweight gate
  passed 213 tests plus 19 subtests, catalog `12/38`, all 94 CAD entrypoints and
  lint in 5.06 seconds. No native CAD library was imported by this gate.

## 2026-07-24 — first coordinated candidate publication diagnosis

- The exact base producer completed as job
  `20260724T155031-variant-r-no-splice-base-ef5d5a00d6` in `90.434 s` at
  `1,287,225,344` bytes peak RSS. It reproduced accepted base SHA-256
  `441cc122c0383da257b16e80c4b424096f33b267cc95cab9d1278fb05a43a784`
  and published producer attestation
  `03776b41eb9cdd890439a52e89c0419ccda1d4190a9a6989e9581f5a3b8344a6`.
- Candidate job
  `20260724T155206-variant-r-no-splice-candidate-c9b3f4d573` reached completed
  geometry but failed its first STEP write after `222.201 s` at
  `1,254,932,480` bytes peak RSS. It published zero outputs; the coordinator
  removed its workspace and reaped all owned processes.
- Root cause is isolated: `variant_r/export.py` called Build123d's direct
  path-based XDE writer, which is already documented as unsafe on this macOS
  path/toolchain and for algebra-tree shapes. The repository-safe `src.cad_io`
  writer rebuilds a shallow object from actual solids and serializes through a
  binary stream. Variant R's export owner now uses that existing pinned wrapper;
  geometry and tolerances are unchanged.

## 2026-07-24 — production candidate topology and visual smoke

- Corrected candidate job
  `20260724T155703-variant-r-no-splice-candidate-safe-export-0dddb0df9c`
  completed in `243.211 s` at `1,263,681,536` bytes peak RSS, atomically
  publishing the production bucket, baffle, gasket, three-solid assembly and
  captured continuous donor parts. Cleanup reaped every owned process.
- The production baffle is exactly `91 faces / 257 edges`, matching the
  validated candidate rather than normalizing a mismatch. The bucket is
  `244 faces / 706 edges`. Both parts have zero old-splice-height edges and zero
  unrelated full-width lower-apron edges.
- Bucket, baffle and gasket are one valid solid each; every individual STEP
  round-trips `1 -> 1`, and the assembly round-trips `3 -> 3`.
- The sole is one planar face at `Z=-91.49500000000002 mm`, width
  `187.0264802158104 mm`, depth `17.556411375566057 mm`, and area
  `2280.0060332270587 mm²`, exceeding both prior minima.
- The refactored foundation donor reports a global minimum
  `Z=-95.00105070833588 mm`, so the current global-min audit reports
  `3.506050708335877 mm` below the sole instead of the earlier workbench
  record's `0.355323 mm`. Because accepted output topology/contact match
  exactly, this is retained as a provenance/metric discrepancy for the fit
  audit rather than hidden or relabeled.
- Doctor passes with the existing pinned read-only Viewer runtime at exact
  commit `fdbb4b4fb62d95ae298cfe9a46fdc7092bdaf423`. The first sandboxed
  Snapshot launch failed only on the documented macOS Chromium Mach-port
  restriction and published nothing.
- Snapshot job
  `20260724T160221-text-to-cad-artifacts-7853c78e3c` completed with local
  renderer permission in `5.175 s` at `2,093,301,760` bytes peak RSS. Direct
  inspection of image SHA-256
  `7d7554c776d2954e0acf46669e16672de7b4379a713997b358cbc69100ca0b38`
  shows an uninterrupted lower-front apron and no old horizontal continuation
  on the right bucket side. Intended driver/recess and sculpted seam edges
  remain visible; no detached body is present.

## 2026-07-24 — fit acceptance and donor-band diagnosis

- Coordinated fit job
  `20260724T160314-variant-r-no-splice-fit-audit-0b3301c33a` completed in
  `484.765 s` at `797,343,744` bytes peak RSS; output SHA-256 is
  `f4e90a9c7f9a004f54ff948a5d623ee68e09225f1bfb02f4ebaa07bc8da19fa2`.
- Imported bucket, baffle and gasket are one valid solid each; the assembly is
  three valid solids. Bucket/baffle, gasket/bucket and gasket/baffle overlap
  are each exactly `0.0 mm³`.
- Both lower mating lands are `438.0 mm²`, each with `1.0` support over `5772`
  samples. The bottom seal has one connected component. Gasket support is
  `1.0 / 1.0`.
- Imported baffle contact is one planar face at `Z=-91.495 mm`, width
  `187.02645777936598 mm` and area `2280.003992178324 mm²`.
- Bidirectional protected baffle/donor comparison sampled 743 exterior points
  and 574 unambiguous interior normals. Maximum deviation is
  `1.484022251031871e-8 mm`; maximum normal change is
  `0.0000012074182697257333°`. Bidirectional bucket deviation is
  `1.4210854715202004e-14 mm` with `0°` normal change.
- Named baffle structure, sand-cap and bucket-shoulder thicknesses remain
  `3.0 mm`.
- Read-only donor diagnostic job
  `20260724T161206-variant-r-donor-subsole-diagnostic-5db64d07e5` completed in
  `13.107 s` at `483,098,624` bytes peak RSS. It proves the earlier
  `3.506051 mm` value came from conservative B-spline face bounding boxes:
  actual donor topology vertices bottom at `Z=-91.85032330335 mm`. The real
  sub-sole band is `0.35532330335 mm`, matching the validated specification.
  Production audit metadata now uses vertex topology for this measurement;
  trim geometry is unchanged.

## 2026-07-24 — strict release failure and preserved validator

- The first coordinated full release job
  `20260724T161354-variant-r-no-splice-production-release-b894fffaa7`
  failed closed after `426.223 s` at `1,067,827,200` bytes peak RSS and
  published no outputs. The unchanged strict seam-material validator found two
  reference-only bucket samples in `top_x_-45`; the first is
  `0.03512473055594756 mm³` at `[-45, -71.75, 86.25]`.
- Focused job
  `20260724T162256-variant-r-continuous-donor-seam-diagnostic-022a92b52f`
  completed in `1159.784 s` at `932,544,512` bytes peak RSS. It found zero
  baffle material mismatches and exactly twelve mirrored, reference-only bucket
  samples across the top and side sections. The candidate adds no material at
  those samples. Diagnostic SHA-256 is
  `7de8614b4861ef2109f00409d4d65ac863a59ec8d5c25322f8dc54c1842c3fc8`.
- The retained L/R/T perimeter curves themselves are unchanged: job
  `20260724T164344-variant-r-perimeter-edge-equivalence-742fbc43b7`
  matched all ten retained edges at each of three offsets with maximum
  bidirectional sampled deviation `1.4254156828833717e-14 mm` and zero length
  difference. That evidence does not authorize normalizing the unrelated
  bucket material loss, so the production validator remains unchanged.

## 2026-07-24 — exact bucket-material restoration feasibility block

- The exact reference-only difference has four natural components. Only two,
  totaling `42.313110088405736 mm³`, lie wholly above the existing bottom
  tangency. Fusing those natural components into the donor produced zero valid
  solids; no cleaning, healing, splitter removal or tolerance widening was
  attempted.
- A second focused experiment used three localized reference ownership regions
  with only already-shared material as overlap bridges. One run restored all
  strict L/R/T material samples, stayed one valid solid, retained zero old
  splice/lower-apron edges, preserved zero overlap, removed no candidate
  material and changed protected surfaces by at most
  `1.4210854715202004e-14 mm`.
- That result was not topology-safe: bucket topology changed from
  `244/706/465` faces/edges/vertices to `257/738/484`. A fresh-process boundary
  localization rebuild then failed to produce one valid solid at all. The
  construction is therefore both boundary-creating and non-reproducible; it is
  not suitable for production ownership.
- Evidence jobs:
  `20260724T165249-variant-r-bucket-material-restoration-feasibilit-043d6d71ec`
  (`244.548 s`, `1,354,760,192` bytes peak),
  `20260724T165914-variant-r-overlap-bridged-bucket-restoration-1fc56104f5`
  (`1250.31 s`, `1,302,429,696` bytes peak), and
  `20260724T172200-variant-r-bucket-restoration-boundary-location-e8249cebf3`
  (`243.959 s`, `1,280,049,152` bytes peak).
- Disposition: stop before another full release or Viewer publication. The
  candidate is not production-accepted, the strict validator is preserved,
  and user authority is required either to alter the material-preservation
  contract or to authorize a broader geometry redesign.

## 2026-07-24 — exact internal bucket delta authorized

- User authority accepts exactly the twelve already measured mirrored,
  reference-only internal bucket micro-omissions as an intentional and
  immaterial consequence of removing the whole-part splice.
- This is a named geometry delta, not tolerance widening or an equivalence
  claim. Candidate-added material, every baffle mismatch, all centre-section
  material mismatches and any additional bucket mismatch remain forbidden.
- The release validator now requires the exact twelve coordinates and measured
  reference-only volumes within a `1e-6 mm³` numerical attestation bound,
  exactly zero candidate-added material, and all ten retained L/R/T perimeter
  edges at three offsets within `1e-9 mm` with zero length difference.
- Production remains the simple deterministic continuous donor plus the
  validated baffle sole trim. Restoration experiments stay workbench-only and
  no restoration or bucket redesign is promoted.
- `origin/main` remains exactly
  `5ec998069b790d648a011d04a2dadb6dc1d8b9e3`; no integration rebase or merge is
  required before the authorized release run.

## 2026-07-24 — accepted production release and publication

- The single authorized full release job
  `20260724T174726-variant-r-no-splice-authorized-production-releas-9f64591b8e`
  passed in one attempt after `1594.716 s` at `1,202,077,696` bytes peak RSS,
  published twelve outputs atomically and completed clean teardown.
- The exact bucket-only signature is `12/12` reference-only records totaling
  `0.3032817572227236 mm³` over their 1 mm sample cubes, with exactly
  `0.0 mm³` candidate-added material. Baffle and centre-section material
  mismatch counts are zero.
- All ten retained L/R/T edges at offsets `0`, `-2.5` and `+2.5 mm` match with
  maximum bidirectional sampled deviation
  `1.4254156828833717e-14 mm` and zero length difference.
- Source and STEP-round-trip topology is bucket `244/706/465` and baffle
  `91/257/169`; both have zero old-splice and unrelated lower-apron edges.
  Every part is one valid solid, the assembly is three valid solids, all
  pairwise overlap is zero, gasket/bottom support is `1.0`, the bottom seal is
  one component, and the sole remains one planar face at `Z=-91.495 mm`.
- Final assembly STEP SHA-256 is
  `0f04b4abf96d67ecd66a196f325c1cd1c6a1e5d2a9114adc73812961ec347185`;
  current sidecar SHA-256 is
  `e28ea39b695652ffe98a29cfb0941e595213e569123500d50595e3bc18974cad`.
- The corrected final Snapshot pair was inspected. Smooth SHA-256 is
  `31ed20b5712358cf1e0c992c26d6cfdffbf9e4f0c30e13e0bd6113c5023819f6`;
  edge-overlay SHA-256 is
  `7d7554c776d2954e0acf46669e16672de7b4379a713997b358cbc69100ca0b38`.
  The former line is absent on the lower baffle and bucket side; intended
  recess and sculpted seam geometry remain.
- The exact final artifact is published through the pinned read-only Viewer;
  the server reports dynamic local root, generation disabled and Viewer
  version `0.3.9`.

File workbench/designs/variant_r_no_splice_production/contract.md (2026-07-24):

# Variant R production no-splice correction contract

Status: implementation and the exact internal bucket delta are authorized;
production release and review evidence remain pending until every gate below
passes.

## Baseline and authority

- Start commit and `origin/main`: merge commit
  `5ec998069b790d648a011d04a2dadb6dc1d8b9e3`.
- Catalog model: `development-190x210-tongue-groove`.
- Production composition owner: `src/enclosure_family/variant_r/assembly.py`.
- Lower ownership/sole owner:
  `src/enclosure_family/variant_r/bottom_ownership.py`.
- Sole parameter owner: `src/enclosure_family/variant_r/parameters.py`.
- Validated design evidence: commit
  `5f5bbf3c2aca0f55f35ae734c8dc0c6004897f75`; its workbench files are evidence,
  not production source.
- Units and axes: millimetres; X left/right, Y front/rear with front at
  negative Y, Z bottom/top.

## Authorized topology-changing construction

Use the continuous exact-edge flat-bottom donor returned by the existing
`VariantRFoundation` path as the active bucket/baffle/gasket joint. Do not call
the whole-part `Z=-80 mm` band splice or lower baffle-to-bucket material
transfer. Intersect only the donor baffle with the half-space at or above the
single parameter-owned planar sole `Z=-91.495 mm`; discard the approximately
`0.355323 mm` underside-only band. Do not heal, unify same-domain faces, remove
splitters, widen tolerances, or modify the legacy cascade.

This deliberately changes B-rep topology. Preservation claims apply to form,
protected surfaces and interfaces, not literal face/edge identity.

The continuous donor also omits exactly twelve mirrored, reference-only
internal bucket material samples recorded by the production validator: two
each in the non-centre top-left, top-right, lower-left-side, upper-left-side,
lower-right-side and upper-right-side sections. This is an explicitly
authorized, immaterial geometry delta required by retiring the whole-part
splice. It is not tolerance widening, equivalence, healing or permission for
any additional material change. Candidate-added material remains forbidden,
all baffle and centre-section material mismatches remain forbidden, and no
restoration Boolean or bucket redesign is authorized.

## Preserved product geometry

- Overall enclosure form, bounds and protected visible surfaces above the sole.
- Driver opening/recess and all unrelated mounting/acoustic geometry.
- Exact sculpted left/right/top seam edge geometry and intended bottom-corner
  transition; the twelve internal bucket-only omissions above are the sole
  material-preservation exception.
- Bucket/baffle/gasket separation, gasket path, support and continuous lower
  seal.
- Fill passages/blisters, sand containment, wall structure and corner closure.
- Bucket and baffle print orientation; baffle remains a full-width planar
  contact with brim assumed.
- Retention remains absent; Variant I, horn, electronics and fasteners remain
  untouched.

## Measurable acceptance

- Bucket, baffle and gasket: one valid solid each; assembly: three valid solids.
- STEP round-trip preserves those solid counts and validity.
- Pairwise unintended overlap is at most `0.001 mm³`.
- Baffle topology matches the validated production expectation of 91 faces and
  257 edges, or any mismatch is rejected and diagnosed.
- Bucket and baffle each have zero B-rep edges at the old splice height and zero
  unrelated full-width lower-apron edges.
- The strict seam grid has exactly the twelve authorized reference-only bucket
  records at their measured coordinates and volumes, with no candidate-added
  material. Baffle records and all centre-section material mismatch counts are
  zero. All ten retained L/R/T perimeter edges at offsets `0`, `-2.5` and
  `+2.5 mm` match the authoritative edge geometry within `1e-9 mm`, with zero
  length difference.
- Sole is planar at exactly `Z=-91.495 mm`, with contact width at least
  `187.020979 mm` and area at least `2277.950023 mm²`; no baffle topology lies
  below it.
- Gasket support ratios are `1.0 / 1.0`; the lower gasket run and bottom seal
  remain one connected component; bottom corner sealing remains complete.
- Protected visible baffle deviation from the continuous donor is at most
  `0.01 mm`; bucket deviation is at most `0.01 mm`; sampled protected normal
  change is reported and any visible new boundary is rejected.
- Existing driver, fill, closure, wall-thickness, seam-section and full-body
  checks remain green.

## Visual and publication question

Matched smooth and edge-overlay lower-front views must show the old line on the
accepted pre-correction artifact and its absence on the exact final production
artifact, including the side continuation. Inspect one exact production
assembly overview or low view only if needed to confirm intended seams and
part separation. Publish the final three-part STEP and its current sidecar
through the read-only Viewer.

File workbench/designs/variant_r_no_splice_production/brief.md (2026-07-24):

Implement and verify the production Variant R no-splice correction, then prepare an exact read-only CAD Viewer artifact for user review. Work autonomously in this fresh worktree and commit the focused result; do not merge or push main.

Start/safety:
- Read all applicable AGENTS.md and use the repository-local `speaker-enclosure-cad` skill throughout.
- Verify the starting ref is current `origin/main`, expected merge commit `5ec9980` containing the reviewed enclosure atomic refactor. Stop and report if it differs materially.
- Reuse `/Users/jaspercurry/Code/CAD - Enclosure/.venv` and pinned project tools. All native CAD, STEP, sidecar, Snapshot and substantial geometry diagnostics must run through `cad_runner`; no upgrades.
- Preserve unrelated work and use a new `codex/` branch in the worktree.

Exact product goal:
- Remove the unwanted full-width horizontal B-rep splice line around Z=-80.1 mm from both the visible Variant R baffle apron and the corresponding enclosure/bucket exterior.
- Preserve overall enclosure form, dimensions, driver opening/recess, sculpted L/R/T seam, gasket path/support, bucket/baffle separation, print orientation/contact, and every unrelated feature. Do not redesign geometry or touch Variant I, horn, electronics, fasteners, retention, or acoustics.
- A topology change is expected and required to remove the real edge; do not claim literal topology identity. Avoid same-domain healing, splitter removal, cosmetic mesh suppression, or tolerance widening.

Validated specification/evidence:
- Read commit `5f5bbf3c2aca0f55f35ae734c8dc0c6004897f75` and the full `workbench/designs/variant_r_underside_seam_refinement/` records via git. It is a validated workbench candidate, not a production implementation; do not simply describe or cherry-pick it as the fix.
- Promote its construction cleanly through the refactored Variant R owners: use the continuous exact-edge flat-bottom donor already exposed by the foundation/composer, bypass the whole-part Z=-80 splice and lower material-transfer operations in the active path, and trim only the baffle’s sub-sole excess to the validated planar sole at Z=-91.495 mm. Discard the ~0.355323 mm underside-only band as specified. Implement one explicit source of truth for this sole plane and honest audit metadata.
- Keep the correction localized to the refactored Variant R assembly/bottom ownership/parameters/print-contract boundary. Do not rewrite the legacy cascade or broaden architecture.

Acceptance:
- Create a concise new iteration brief/contract/feedback record preserving this user direction and clearly separating preserved form from necessary B-rep topology change.
- Run native-free checks first, then the smallest proportional CAD build/fit/topology comparison, then release/round-trip and visual evidence.
- Require zero old-splice-height edges and zero unrelated full-width lower-apron edges on both baffle and bucket. Compare against the validated candidate expectations (candidate baffle 91 faces/257 edges) and diagnose any mismatch rather than normalizing it.
- Prove one valid solid per part, assembly three solids, zero unintended overlap, continuous bottom seal, full gasket support, planar baffle sole/contact at Z=-91.495 mm meeting the prior width/area minima, protected visible-surface continuity/deviation, unchanged intended seams/features, and STEP round-trip.
- Generate the smallest matched edge-overlay/smooth visual evidence, inspect it, and publish the exact final review STEP plus current sidecar with a read-only Viewer link. The former line must be visibly absent from the baffle and side.
- Update current model/atomic ownership/known-boundary records only where authoritative facts change; preserve the prior refactor history rather than rewriting it. Catalog ownership should remain unchanged unless genuinely required. Run catalog/entrypoint/lint/fast checks.
- Commit the complete focused correction with a clean worktree. Final response must report branch and commit, changed ownership path, exact geometry checks, timings/peak memory, artifact/sidecar/Snapshot hashes, and the exact Viewer URL/path. Do not merge or push.

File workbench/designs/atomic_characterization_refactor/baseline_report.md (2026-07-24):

<!-- Generated by render_phase_a_reports.py from atomic_manifest.json. Do not edit by hand. -->

# Reproducible baseline report

Current checkpoint status: **FINAL FORCED RELEASE EQUIVALENT; VISUAL EVIDENCE INSPECTED; INDEPENDENT REVIEW PENDING**.

## Current combined-base reproduction

- Exact base: `c25cddb3eeafe6f6dff3b551be4ceb53d5aee9ce`
- Current source: `experiments/sand_cube_190x210_internal_squat_absorber_rear_corners_parabolic_side_g1_simple_tongue_groove_baffle/generate_sand_cube_190x210_internal_squat_absorber_rear_corners_parabolic_side_g1_simple_tongue_groove_baffle.py`
- Source SHA-256: `d67d011f3a1be1bf563786befb1af09fe74e4438e061abf670f0f3aef7cc0e62`
- Generation job: `20260724T102722-atomic-refactor-landing-restored-release-52bd80460c`; 1493.266 s; 1403142144 bytes peak RSS
- Equivalence job: `20260724T105504-atomic-refactor-landing-strict-a9945e2f37`; 2113.045 s; 2430173184 bytes peak RSS
- Full parts/protected sections: 8; all equivalent: yes
- Maximum removed/added material: 0.0 / 0.0 mm³
- Bucket/baffle overlap: 0.0 mm³
- STEP round-trip: pass

The accepted current flat-bottom missing-material relationship is baseline behavior. Do not repair or reconcile it in this refactor.

## Historical Phase A / early Phase B baseline record

Historical checkpoint status: **HISTORICAL BLOCKED: owning Python source did not reproduce an accepted baseline at that checkpoint**.

## Native source reproduction

- Owning source: `experiments/sand_cube_190x210_internal_squat_absorber_rear_corners_parabolic_side_g1_lightweight_coherent_closure/generate_sand_cube_190x210_internal_squat_absorber_rear_corners_parabolic_side_g1_lightweight_coherent_closure.py`
- Source SHA-256: `0f318a52cf4148d2f2367a18176867acfad76e5a6827d77ca42e5395ce43ba2a`
- CAD job: `20260723T040911-generate-sand-cube-190x210-internal-squat-absorb-603368ef69`
- Outcome: failed once in current source; no geometry retry
- Exact failure: `ValueError: rear-ramped longitudinal top rail did not produce one valid solid: 2`
- Elapsed / peak RSS: 83.797 s / 1290780672 bytes
- Published outputs: —
- Validator: not run; authoritative lightweight base STEP was not published

This is a source-boundary failure. The immutable STEP references remain evidence; none is promoted to Python authority.

## Immutable reference measurements

| Input ID | Solids | Valid | Volume (mm³) | Bounds size X×Y×Z (mm) | Center of mass X,Y,Z (mm) | Faces / edges / vertices | Interpretation |
|---|---:|---|---:|---|---|---|---|
| R.clean_bucket | 1 | yes | 1091181.8588 | 190.0021<br>202.0<br>190.0021 | -15.8058<br>37.8545<br>-8.2366 | 257 / 739 / 486 | clean sculpted-seam evidence; wrong bottom ownership |
| R.bottom_ownership_assembly | 2 | yes | 1344573.3691 | 190.0021<br>210.0<br>190.0021 | -14.9492<br>14.4607<br>-5.6635 | 453 / 1306 / 858 | bucket 1111212.8535 mm3 plus baffle 233360.5156 mm3; bottom-ownership evidence only |
| R.flat_bottom_baffle | 1 | yes | 231910.4722 | 190.0021<br>19.1833<br>190.0021 | -6.6705<br>-85.6869<br>1.135 | 94 / 265 / 173 | flat full-width edge contribution; exact stable bed footprint remains unproved |
| I.full_perimeter_bucket | 1 | yes | 1099176.7709 | 190.0021<br>202.0<br>190.0021 | -15.7811<br>37.1339<br>-7.8188 | 376 / 1085 / 713 | historic full-perimeter removable bucket, not Variant I geometry |
| I.full_perimeter_baffle | 1 | yes | 232624.6919 | 190.0021<br>19.1833<br>190.0021 | -5.6655<br>-85.6977<br>0.577 | 166 / 484 / 319 | historic removable baffle, not an integral front |
| I.full_perimeter_assembly | 9 | yes | 1336604.2793 | 190.0021<br>210.0<br>196.3537 | -14.1317<br>14.9331<br>-5.2553 | 600 / 1701 / 1120 | historic removable assembly with gasket/hardware; no open bottom or hatch |
| tube.reference | 6 | yes | 195017.5093 | 173.7374<br>136.25<br>174.6 | 10.3527<br>66.4509<br>-11.3566 | 274 / 742 / 488 | historic continuous-bore/serviceable routing reference |
| resonator.rev_c_placement | 4 | yes | 64314.7917 | 76.6537<br>74.9672<br>76.6469 | 31.3131<br>73.826<br>35.0679 | 242 / 681 / 454 | Rev C mechanical-placement reference |
| resonator.rev_d_assembly | 2 | yes | 47217.1819 | 74.9672<br>76.9344<br>30.0 | 7.7286<br>0.0<br>14.9473 | 226 / 657 / 438 | Rev D acoustic/calibration study |
| resonator.rev_d_print_layout | 5 | yes | 84471.2588 | 312.5<br>133.0<br>32.0 | 25.2466<br>0.0004<br>9.454 | 224 / 546 / 364 | Rev D print-layout study |

## Evidence binding

- Review copy STEP: `build/workbench/atomic_characterization_refactor/near_perfect_bucket/near_perfect_bucket.step`
- STEP SHA-256: `eaeed68103e3110ca3e888ece90002a7f2f98a8b174fab5906e7fb0bd9350b97`
- Sidecar SHA-256: `609bb53774ab6301a4ad724aeb62d0a0ed7b3600c93528d9502d73d8e5dc5d4b`
- Snapshot job specification: `workbench/designs/atomic_characterization_refactor/snapshot-job.json`
- Snapshot outputs: path: build/workbench/atomic_characterization_refactor/near_perfect_bucket/snapshot-isometric_20260723T042632Z.png<br>sha256: 314fcc48133ab2db2eb16a3a62d1a3570433e938f7cefc31f757d4082ab8e139<br>path: build/workbench/atomic_characterization_refactor/near_perfect_bucket/snapshot-center-section_20260723T042632Z.png<br>sha256: 5fed09fe71a51b34eb4776b87a86819736c70a57791d2f4703d6ba47bc232eb1
- Viewer record: `build/workbench/atomic_characterization_refactor/near_perfect_bucket/viewer-record.json`

A matching bounding box is not treated as equivalence. The sentence above is the preserved historical record; the current combined-base overlay at the top supplies the accepted semantic and STEP round-trip proof.

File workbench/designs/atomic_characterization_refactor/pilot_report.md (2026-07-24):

<!-- Generated by render_phase_a_reports.py from atomic_manifest.json. Do not edit by hand. -->

# Phase B first-atom checkpoint

Status: **complete**

Atom: `family.coordinate_contract`

## Source change and module boundary

- Exact owner: `src/enclosure_family/datums.py`
- Boundary: native-CAD-free immutable metadata only: units, 190x210x190 envelope, axis polarity, center datum, and derived named planes
- Added CoordinateContract and ENCLOSURE_190X210_COORDINATES.
- Made the single-oval Design consume width, depth, height, and center_y from that owner.
- Replaced duplicated +10 mm Y-center expressions in existing 190x210 family consumers with Design.center_y.
- Added AST/native-free regression tests and included them in the lightweight lint plan.
- Did not change a Boolean, STEP, model identity, catalog entry, wall stack, seam, brace, fill path, assembly transform, or print contract.

## Exact preserved contract

- Units: `mm`
- Envelope: `[190.0, 210.0, 190.0]` mm
- Center: `[0.0, 10.0, 0.0]` mm
- Named planes: `{'left_x': -95.0, 'right_x': 95.0, 'front_y': -95.0, 'rear_y': 115.0, 'bottom_z': -95.0, 'top_z': 95.0}`
- Axis directions: `{'left': [-1, 0, 0], 'right': [1, 0, 0], 'front': [0, -1, 0], 'rear': [0, 1, 0], 'bottom': [0, 0, -1], 'top': [0, 0, 1]}`
- Tolerance: `0.0` mm

## Native-free evidence

- Fast contract: `valid`; 8 selected requirements; 0.079 s; 30720000 bytes peak RSS.
- Lightweight suite: `pass`; 86 tests and 19 subtests; 5.086 s; 59359232 bytes peak RSS.

## Native boundary comparison

| State | Job | Elapsed (s) | Peak RSS (bytes) | Outputs | Result |
|---|---|---:|---:|---:|---|
| Before | `20260723T040911-generate-sand-cube-190x210-internal-squat-absorb-603368ef69` | 83.797 | 1290780672 | 0 | `ValueError: rear-ramped longitudinal top rail did not produce one valid solid: 2` |
| After | `20260723T100534-generate-sand-cube-190x210-internal-squat-absorb-c4d37f5ec2` | 95.849 | 1288798208 | 0 | `ValueError: rear-ramped longitudinal top rail did not produce one valid solid: 2` |

The metadata extraction introduced no earlier native failure and reached the exact frozen one-solid rail invariant. This is boundary-equivalence evidence, not geometry equivalence; no new STEP exists.

## Artifact and visual comparison

- Before STEP SHA-256: `eaeed68103e3110ca3e888ece90002a7f2f98a8b174fab5906e7fb0bd9350b97`
- After STEP SHA-256: `None`
- After-artifact boundary: The known owning-source rail failure still prevents export.
- Before visual: User accepted the hash-bound near_perfect_bucket STEP in the read-only Viewer; Snapshot hashes remain recorded under baseline.review_evidence.
- After visual: No visual delta was generated because this atom is metadata-only and the owning geometry baseline still fails before STEP export.
- Claim boundary: The frozen reference is continuity evidence only. No old/new visual or geometric equivalence is claimed.

## Architectural lessons

- A pure datum owner can be extracted and tested without loading the CAD kernel.
- The +10 mm Y center was a hidden family parameter, not a harmless placement literal.
- Source-chain boundary comparison is useful for metadata atoms but cannot substitute for geometry equivalence.
- The next geometry atom remains gated by repair of the deterministic top-rail failure.

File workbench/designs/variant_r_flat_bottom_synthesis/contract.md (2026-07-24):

# Variant R flat-bottom synthesis contract

Status: complete — Stage 1 geometry and release evidence validated

## Authorization and boundary

The verbatim user instruction is preserved in `brief.md`. It follows the
explicit request for authorization to enter later Variant R geometry-synthesis
scope and reconcile the sculpted seam with the flat-bottom references.

This iteration may:

- repair the pre-existing rear-ramp rail placement blocker as a separately
  measured prerequisite;
- preserve the accepted sculpted left, right, and top seating seam;
- replace only the lower center perimeter detour with the accepted flat,
  full-width baffle printing edge and complementary bucket ownership;
- restore a continuous, supported lower gasket run and sealed bottom-corner
  transitions; and
- produce a reproducible parameterized bucket/baffle pair with current
  programmatic and visual evidence.

This iteration may not add the deferred hinge, lower fasteners, integral-front
variant, bottom hatch, horn, tube, resonator, bracket, electronics, or final
support-aware bracing. `BUILD_TOP_HINGE` and `BUILD_BOTTOM_SCREWS` remain
disabled.

## Catalog baseline

- Model: `development-190x210-tongue-groove`
- Lifecycle: `development`
- Owner and entrypoint:
  `experiments/sand_cube_190x210_internal_squat_absorber_rear_corners_parabolic_side_g1_simple_tongue_groove_baffle/generate_sand_cube_190x210_internal_squat_absorber_rear_corners_parabolic_side_g1_simple_tongue_groove_baffle.py`
- Validator:
  `experiments/sand_cube_190x210_internal_squat_absorber_rear_corners_parabolic_side_g1_simple_tongue_groove_baffle/validate_simple_tongue_groove_baffle.py`
- Output:
  `build/sand_cube_190x210_internal_squat_absorber_rear_corners_parabolic_side_g1_simple_tongue_groove_baffle`
- Units: millimeters
- Family envelope: 190 mm X, 210 mm Y, 190 mm Z, centered at Y = +10 mm

## Hash-bound reference contributions

- Clean sculpted bucket:
  `workbench/designs/canonical_working_set/enclosures/removable_front_baffle/links/near_perfect_bucket.step`
  (`eaeed68103e3110ca3e888ece90002a7f2f98a8b174fab5906e7fb0bd9350b97`)
- Bottom-ownership assembly:
  `workbench/designs/canonical_working_set/enclosures/removable_front_baffle/links/bottom_ownership_assembly.step`
  (`90558975e0e8fb735534b53a73eb7970d3bdddd6aeda34fb821380915877bab0`)
- Flat-edge baffle:
  `workbench/designs/canonical_working_set/enclosures/removable_front_baffle/links/flat_bottom_baffle.step`
  (`23c4d67927bbec6702c300c9912a7542383de093940378184b3d932fee3971c2`)

The STEP files are evidence only. Parameterized Python remains authoritative.

## Required invariants

1. Bucket and baffle are each one valid solid before export and after STEP
   round-trip.
2. Left/right/top bucket and baffle seam material matches the authoritative
   sculpted joint at every protected 0.5 mm sample. A point-classifier
   disagreement exactly on a reconstructed boundary is acceptable only when a
   1 mm local cube has at most `0.001 mm³` symmetric material difference.
3. The known top-seam mismatch cube near
   `[-45.0, -71.75, 86.25]` contains no unexplained reference-only or
   candidate-only material above `0.01 mm³`.
4. The only perimeter-wire policy change is the bottom-center detour. Exact
   authoritative edge geometry is reused for the protected perimeter.
5. The lower gasket run has one connected component.
6. Bucket and baffle lower lands are supported at or above the existing
   minimum gasket-support ratio.
7. The baffle has a genuinely planar full-width lower bed-contact edge and a
   reported seating span and planar area. The accepted reference was found to
   contain two trimmed-topology transition nubs extending `0.350323 mm` below
   its nominal `Z = -91.5 mm` plane; the synthesized baffle must contain no
   topology below that plane. The final contact must be one planar face at
   `Z = -91.5 mm`, at least `187.0 mm` wide and `2200 mm²` in area.
8. The lower bucket and baffle ownership is complementary: overlap remains at
   or below the existing tolerance, while sealing and corner closures remain
   present.
9. Exterior bounds and the protected visible skin remain unchanged outside
   the explicitly permitted lower band.
10. Fill paths and sand-cap closure checks remain green.
11. All monkeypatched ancestor state is restored after generation.

## Print contracts

- Bucket: rear face on the bed; design-coordinate build direction `-Y`.
- Baffle: narrow lower edge on the bed; design-coordinate build direction
  `+Z`; brim assumed.

The acceptance evidence must report bed-contact span/area and must not infer
support-free printability from appearance alone.

## Verification

- `fast`: native-free contract validity, catalog, entrypoint safety, tests,
  and lint.
- `fit`: rail topology, authoritative/candidate seam occupancy, local mismatch
  volume, bottom support/continuity, corner closure, overlap, fill clearance,
  and print-contact measurements.
- `release`: successful coordinated generation, STEP round-trip, current
  diagnostics and topology sidecars, exact Viewer link, one inspected
  isometric overview, and at most one focused seam/bottom render.

## Visual questions

1. Does the assembled pair retain the accepted sculpted left/right/top seam
   without the unwanted corner hunks?
2. Does a focused bottom-corner/edge view show a continuous transition into a
   genuinely flat baffle printing edge?

## Promotion check

The production entrypoint output must reproduce the accepted candidate's
semantic measurements within the tolerances above. Scratch or failed-job
artifacts cannot be described as complete.

## Validated result

- Coordinated full-fit job:
  `20260723T151259-validate-simple-tongue-groove-baffle-74db9f9037`;
  `1543.325 s`, `1,380,220,928` bytes peak RSS, successful cleanup, and no
  owned orphan process.
- Bucket STEP:
  `836c2132b09eb950d46f52c26396bc499c71109dcc25a46b4ade77cc7522cd6b`.
- Baffle STEP:
  `4036538dfccd55541ada5b92be1cee68498127093f55aa6d0f03af263dda6006`.
- Both parts are one valid solid before export and after STEP round-trip, with
  zero positive-volume overlap.
- Protected left/right/top material mismatches are zero; the known top
  comparison cube is also exact.
- Bucket and baffle gasket support ratios are both `1.0`. The lower land
  support ratios are both `1.0` across `5772` samples, and the lower seal is
  one connected component.
- The final baffle terminates at `Z = -91.5 mm` on one planar
  `187.020979 × 17.552651 mm` face of `2277.950023 mm²`. No trimmed topology
  extends below that face.
- Fill blockage and unclosed non-fill sand-cap volume are zero, and all
  bottom-corner closure checks pass.
- `BUILD_TOP_HINGE` and `BUILD_BOTTOM_SCREWS` remain intentionally disabled.
  Their geometry and assembly path are deferred to later stages.
- A brim remains assumed. CAD establishes the contact geometry but does not
  validate first-layer adhesion, print stability, or the completed physical
  assembly.

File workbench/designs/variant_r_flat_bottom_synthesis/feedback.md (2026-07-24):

# Variant R flat-bottom synthesis feedback

## 2026-07-23 — authorization and preflight

- The user explicitly authorized entry into the later Variant R synthesis
  scope after the atomic refactor stopped at the material seam discrepancy.
- The complete original atomic-characterization brief was re-read. Its
  SHA-256 remained
  `7cb5fad7514df1670ba9fd017cce0d44369564018515e3b4ec5be2c55d4bb96e`;
  it was not modified.
- Work continued only in the clean dedicated worktree on
  `codex/atomic-characterization-refactor` at
  `3ff46c29138e8b4cbdcfe542b1dc075591701eb8`.
- Local `main` remained
  `ea5539f3372e1bad5ad05eba85f4bd9a53e8c868`, satisfying the saved brief's
  required ancestry check.
- The repository-local `speaker-enclosure-cad` skill and all five applicable
  references were re-read and applied.
- Pinned versions passed `cad_review.py doctor`: build123d 0.11.1, OCP
  7.9.3.1, Build123d-MCP 0.3.79, Text-to-CAD 0.3.9.
- Catalog validation passed: 10 primary models and 38 experiment families.
- The complete native-free suite passed 86 tests and 19 subtests, 76 CAD
  entrypoint checks, catalog consistency, and lint.
- The canonical checksum verification found one stale source checksum: the
  bass-reflex route source had consumed the already-approved coordinate datum
  in commit `fe33191`. The source change was exactly the geometry-preserving
  substitutions `10.0` to `d.center_y` and `base.D.center_y`; the checksum map
  was refreshed from
  `1b2fcd344726f192b37e9081b6e41588b797a1a35e3301600ba2dbe77455307d`
  to
  `8464d717b16157d3aadc7881c537c687484c08ece51aed093ccc2da52f60f872`.
- The three removable-front reference hashes still matched their canonical
  records.

## 2026-07-23 — synthesis hypothesis

- The existing hybrid perimeter reconstructs the complete wire even though
  only the bottom-center path is intended to change.
- Prior protected-section evidence found reference-only material near the top
  seam and no hybrid-only material, so reconstructing protected edges is not a
  safe implementation of the “bottom only” policy.
- The first candidate will reuse exact edge geometry from the authoritative
  perimeter for the left, right, and top, remove only the four bottom-center
  detour edges, and insert one flat lower edge between the unchanged bottom
  corner tangency points.

## 2026-07-23 — rear-ramp rail prerequisite

- A Build123d Workbench scratch reproduction confirmed that `Plane.YZ`
  preserved the ramp polygon's global Y/Z coordinates. The unplaced ramp
  occupied X `[-5, 5]`, Y `[98, 108]`, Z `[78, 89]` mm and intersected the
  main rail over the intended 1 mm Y overlap.
- Applying the source's second placement moved that same ramp to Y
  `[201, 211]`, Z `[161.5, 172.5]` mm and produced a two-solid compound.
- Removing only the redundant placement produced one valid rail solid at
  `18,459.833333 mm³`, with bounds X `[-5, 5]`, Y
  `[-64.3166667, 108]`, Z `[78, 89]` mm.
- Focused coordinated job
  `20260723T125800-validate-rail-50fbe655ec` completed in 27.341 seconds at
  552,828,928 bytes peak RSS. It validated all three rotated rails as valid
  equal-volume solids and retained three valid solids after STEP round-trip.
- The runner published the rail STEP with SHA-256
  `c0fb5fff731a3ee0603dd85309f7283964f3a1e51fd58a5522ac1d72beeda1f5`
  and diagnostics with SHA-256
  `19e56b5260941821ccab66a0013d13761ab5a8981bcd12311b3d7880dfdb4dc6`.
  The job workspace was removed and no owned process remained.
- After the change, the native-free suite again passed 86 tests and 19
  subtests, 77 CAD entrypoint checks, catalog consistency, and lint.

## 2026-07-23 — exact perimeter and lower-band synthesis

- Focused job
  `20260723T130214-validate-perimeter-c591164fdd` completed in `24.848 s`
  at `532,414,464` bytes peak RSS. It proved that each hybrid perimeter
  retains the ten exact authoritative left/right/top and corner edges,
  removes only the four lower-center detour edges, inserts one flat lower
  edge at the unchanged corner tangencies, and closes as one wire.
- Its diagnostics SHA-256 is
  `8e44f62cb1a87afe91bee13ab4a116cc51cad5df13f4802b84c1c26618e9837a`.
- Rebuilding an entire seam from sampled points was rejected because it had
  already produced protected top material drift despite similar dimensions.
  The accepted implementation instead uses the authoritative B-rep edges
  themselves.
- Focused job `20260723T131729-validate-splice-8db0a3f7de` completed in
  `29.276 s` at `565,575,680` bytes peak RSS. It proved the baffle land,
  gasket, and bucket land each form one valid solid while retaining the
  authoritative material above `Z = -80 mm` and the flat donor below it,
  joined across a `0.20 mm` overlap.
- Its diagnostics SHA-256 is
  `090844cbb11d192f30849f5ea89041c2a4e9fb5e707f062519e4b7bf13de5a08`.

## 2026-07-23 — first full fit pass and visual review

- Coordinated full job
  `20260723T133625-validate-simple-tongue-groove-baffle-7dcf39478d`
  completed successfully in `1880.163 s` at `1,348,157,440` bytes peak RSS.
  It established the exact protected seam, complementary lower ownership,
  gasket support, closure, fill, state-restoration, repeatability, and STEP
  round-trip checks.
- The first review assembly and sidecar were produced by
  `20260723T144335-package-review-5d3941813a` and
  `20260723T144429-text-to-cad-artifacts-c415ac9e32`; their assembly and
  sidecar hashes were respectively
  `f0c0c4bb5c4b25927a3f37040f11199668e3449e6358793787ad2021cbdd7b3c`
  and
  `498b178ba438578400ba4a0de3786575761b239ab5acd352eedd96dd5092e2bd`.
- Snapshot inspection exposed a remaining print-contract problem that the
  first validator did not encode: apparent straightness did not prove that
  the baffle's lowest trimmed topology lay on a planar bed face. Those
  artifacts are superseded and are not final evidence.

## 2026-07-23 — print-contact diagnosis and failed correction attempts

- Jobs `20260723T140849-validate-print-contact-042818854f`,
  `20260723T141011-validate-print-contact-11c9b4acb2`,
  `20260723T144802-validate-print-contact-90288bf53b`, and
  `20260723T144914-validate-print-contact-7397ac73d4` failed while the audit
  used conservative B-spline surface bounding boxes and minimum-bound edge
  selection. Both the candidate and reference were incorrectly reported as
  lacking contact.
- Trimmed B-rep topology then established the real condition. The accepted
  reference had a broad planar face at `Z = -91.5 mm`, `145.0 mm` wide and
  approximately `400.673 mm²`, but two transition nubs reached
  `0.350323 mm` below it. It was almost flat rather than genuinely bed-flat.
- Direct lower-material reassignment in
  `20260723T145324-validate-print-transfer-41e63a4016` left the bucket as two
  solids. The first two root formulations in
  `20260723T145446-validate-print-transfer-9f54cc9e89` and
  `20260723T145555-validate-print-transfer-5410ec3d11` failed to form one
  valid receiving bucket.
- Jobs `20260723T145709-validate-print-transfer-0cf663c4f9` and
  `20260723T145857-validate-print-transfer-ebec32f0b8` reached a valid helper
  result, but the diagnostic treated a `None` zero-overlap result as a shape
  and failed. The diagnostic was corrected without changing the geometry.
- Jobs `20260723T150106-validate-print-transfer-420d6e026d` and
  `20260723T150334-validate-print-transfer-3791f8a2a9` then reached the
  intended transfer, but still selected the loose surface-box minimum rather
  than the trimmed topology. Follow-up audits
  `20260723T150730-validate-print-contact-223ae10295` and
  `20260723T150811-validate-print-contact-17ed80f8b6` narrowed the remaining
  issue to that measurement policy.
- All failed jobs cleaned their own workspaces and left no owned orphan
  process. They are diagnostic history, not acceptance evidence.

## 2026-07-23 — final print-plane transfer

- The final source trims the baffle at the nominal `Z = -91.5 mm` print
  plane, transfers the removed lower material to the bucket, and roots it
  across the `1.0 mm` gasket gap with `0.20 mm` intentional overlap.
- Focused job
  `20260723T150947-validate-print-transfer-17f22c836f` completed in
  `103.528 s` at `943,128,576` bytes peak RSS with clean teardown and no
  owned orphan process.
- It produced one valid bucket and one valid baffle with zero overlap. The
  baffle lost `3622.016297 mm³`, the bucket gained `3827.154114 mm³`, and
  the deliberate lower root added `205.137817 mm³`.
- Its baffle contact is one planar face at `Z = -91.5 mm`, spanning
  `187.020979 × 17.552651 mm` and `2277.950023 mm²`.
- Focused candidate hashes are:
  bucket
  `ae845758e23878b781b8c71037dec802f5be3761e33829b8c6430bfd776845f2`,
  baffle
  `217fe8df7717c8e8f6576b20dbcecf9f8ca14b6058bd5b865d6c07771664be3c`,
  and diagnostics
  `31da9344a96967a87165a4938e32682dab07228c39144c13fce89e2148a3d65d`.

## 2026-07-23 — final coordinated validation

- Final full-fit job
  `20260723T151259-validate-simple-tongue-groove-baffle-74db9f9037`
  completed in `1543.325 s` at `1,380,220,928` bytes peak RSS. It exited
  successfully, removed its workspace, and left no owned orphan process.
- Final output hashes:
  - bucket STEP:
    `836c2132b09eb950d46f52c26396bc499c71109dcc25a46b4ade77cc7522cd6b`;
  - baffle STEP:
    `4036538dfccd55541ada5b92be1cee68498127093f55aa6d0f03af263dda6006`;
  - diagnostics:
    `c827b673c83dc925e1a24fe72ad71205e49f7608acb56873de59814273030196`.
- Bucket and baffle are each one valid solid before export and after STEP
  round-trip, with `0.0 mm³` overlap. All protected left/right/top material
  mismatch counts are zero, including the previously known top cube.
- Gasket support ratios are `1.0` on both parts. Each lower land supports all
  `5772` samples, the lower seal is one connected component, fill blockage is
  `0.0 mm³`, unclosed non-fill sand cap is `0.0 mm³`, and the corner closure
  audits pass.
- The print-contact check measures one `2277.950023 mm²` planar face at
  `Z = -91.5 mm`, `187.020979 mm` wide and `17.552651 mm` deep. A brim is
  assumed; physical first-layer adhesion is not validated.
- `BUILD_TOP_HINGE=False` and `BUILD_BOTTOM_SCREWS=False`. The final Stage 1
  pair intentionally contains no retention hardware.

## 2026-07-23 — exported-artifact audit and visual evidence

- Independent exported-STEP audit
  `20260723T153848-validate-print-contact-e0d9ded786` completed in
  `17.144 s` at `545,046,528` bytes peak RSS. Its diagnostics SHA-256 is
  `831a8d59c1224810539bdd4017c862c68a89c93e0a72cf3c963831f36f2830ea`.
  It measured the reference's `0.350323 mm` below-plane transition and the
  final candidate's `0.0 mm`.
- Final review package job
  `20260723T153916-package-review-8a719db8af` completed in `76.822 s` at
  `1,067,237,376` bytes peak RSS. The two-solid, zero-overlap assembly STEP
  SHA-256 is
  `ffcd16f32f113f992666eadadb3c29a82fc4b0b339e38affc2fc49495aaa31c8`;
  its diagnostics SHA-256 is
  `caeca3626142101a0946e1f307b3ecbb034832fbb642e7d5e6981addfef755f8`.
- Assembly sidecar job
  `20260723T154042-text-to-cad-artifacts-72d19abd68` completed in `6.057 s`
  at `484,720,640` bytes peak RSS. The current sidecar SHA-256 is
  `316766b458c6ccfe46db22ad69b1382ab08f053ddac328b1667dc3ed3dfe7b66`.
- Baffle sidecar job
  `20260723T154208-text-to-cad-artifacts-2baa807349` completed in `4.552 s`
  at `425,508,864` bytes peak RSS. Its SHA-256 is
  `ce23059d97ac3d5a9fc56bfbffa6a7c03d3bd22ab5a843d7ccf2f431d016c0d4`.
- Snapshot job
  `20260723T154224-text-to-cad-artifacts-bcee70e3a7` completed in `4.648 s`
  at `1,524,334,592` bytes peak RSS. The inspected isometric overview SHA is
  `9150298aca8a3ed8752708f338d65d2e4271ef67ddde1e2a26177ea3ef33620d`;
  the inspected isolated baffle-front SHA is
  `23f0d231d12607f0f189a3e0fd78479f0d1f8c6eaab6261c697dadb7cd7d8944`.
- The overview shows a continuous sculpted left/right/top seat, no unwanted
  corner hunks, and no new exterior discontinuity. The isolated baffle view
  shows a straight lower boundary with no transition nubs.
- The read-only Viewer loaded the exact final review assembly and current
  sidecar as two named components: `Variant R bucket` and
  `Variant R removable baffle`. The hash-bound URL and session record are in
  `viewer-record.json`.
- All final native jobs cleaned their workspaces and left no owned orphan
  process.

## 2026-07-23 — release verification packet

- The standard contract validated for the composed `fast`, `fit`, and
  `release` profiles.
- The release review packet validated with status `pass` and no issues. Its
  contract fingerprint is
  `11b0b386b1ed207b18ebb501ec293106923a3ab83f8a14f39844ff06b1af33cb`;
  source fingerprint is
  `cbb0a31f2da36fd65c557a6d6256a71f90f04680c019293cc55eb07d5c005c5c`;
  and final input fingerprint is
  `ec3048be60f487964be7d559304652d547bc68d43dd073cab28682e3a2194d38`.
- The final generated contract JSON SHA-256 is
  `6c4a7c59823edca82a454e07ffe481de88fe17b35feeb95c09b39fd6465d624e`;
  the release packet SHA-256 is
  `73876c49d0055d204c6d841061e348282a4d10c67678c9431031f2978592d7a2`.
- `evidence_manifest.json` records the exact authoritative source, jobs,
  measurements, artifact hashes, Viewer record, inspected Snapshots, release
  verification, and deferred uncertainties for the accepted Stage 1 result.

## 2026-07-23 — final repository checks

- All 30 entries in the canonical working-set checksum map passed after
  deliberately refreshing only the active generator, validator, and
  superseded handoff hashes. The three immutable removable-front reference
  artifacts retained their original hashes.
- `cad_review.py doctor` passed the pinned build123d `0.11.1`,
  cadquery-ocp-novtk `7.9.3.1`, Build123d-MCP `0.3.79`, read-only Viewer
  overlay, and model-catalog checks.
- `cad_review.py check-catalog` passed with 10 primary models and 38
  experiment families.
- The complete native-free suite passed 86 tests and 19 subtests, all 82 CAD
  entrypoint-safety checks, catalog consistency, and its maintained lint
  baseline.
- The changed Python files compiled successfully; the iteration scripts had
  no Ruff findings outside the repository's intentional coordinated-entrypoint
  import pattern and legacy unused imports; JSON records parsed; and
  `git diff --check` passed.

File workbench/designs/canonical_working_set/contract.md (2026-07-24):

# Canonical working-set organization contract

The original map-creation contract below is historical. Its prohibition on
artifact promotion applied to the initial navigation-only change. The
2026-07-22 input landing later promoted the exact selected evidence bytes into
immutable `reference_evidence/` owners without changing geometry.

## Requested result

Provide one trustworthy, easy-to-navigate directory for the fundamental
enclosure, acoustic, and horn lineages. Preserve current work and make older
variants easy to ignore without destroying their provenance.

## In scope

- A parent overview for the complete working set.
- Separate component folders with local READMEs and exact source manifests.
- Stable, human-readable links to authoritative source directories and
  hash-bound reference artifacts.
- A clear archive/status index for older experiments and rejected candidates.
- Explicit blockers and next steps for a future refactoring agent.

## Out of scope

- Geometry edits, CAD rebuilds, STEP normalization, or artifact promotion.
- Moving, copying, flattening, or renaming existing source dependency chains.
- Declaring any unpromoted STEP-derived candidate to be production source.
- Tube/resonator packaging, monolithic-front construction, hatch cutting, or
  horn resizing.

## Invariants

- Every source link resolves to the existing owner in the current working
  tree.
- Every artifact link resolves to the exact file named in its manifest.
- Recorded SHA-256 values match current contents at this checkpoint.
- Active, supporting, study, historical, released, and archived states remain
  distinguishable.
- Existing uncommitted changes remain untouched.
- `.cad-project/models.toml` remains the lifecycle catalog; this directory is
  a curated working view, not a competing geometry registry.

## Acceptance check

A new agent can enter this directory, identify the correct variant, locate its
owner and evidence, understand what each reference contributes, see what is
blocked, and avoid the known cross-variant substitutions without searching the
entire repository first.
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

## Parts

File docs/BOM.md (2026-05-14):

# Bill of Materials Draft

Date: 2026-05-14

Prices move, so treat this as a working BOM, not a purchase order.

| Item | Qty | Source / SKU | Current Note |
| --- | ---: | --- | --- |
| Dayton Audio Epique E150HE-44 driver | 1 | Parts Express 295-102 | Parts Express page shows $119.98 and in stock. |
| Dayton Audio Epique E180HE-PR passive radiator | 1 | Parts Express 295-114 | Parts Express page shows $49.95 and in stock. |
| PETG filament | 2-3 kg | Polymaker PETG or Bambu PETG-HF | Re-check product line before ordering; legacy PolyLite PETG appears to be changing. |
| M4 heat-set inserts | 1 pack | Ruthex/CNC Kitchen/McMaster | Use only after boss coupon test. |
| M4 socket-cap screws | 1 pack | McMaster or equivalent | Length depends on flange thickness and insert depth. |
| GX16-4 panel connector | 1+ | Amazon/Olimex/equivalent | Validate real panel cutout from purchased part. |
| Heyco SR-6P-4 strain relief | 1+ | Heyco 1210 | Validate cable OD before committing top-face cutout. |
| Fill port O-rings | 5 | 22 mm x 2 mm Viton/EPDM | Only after M20x2 coupon succeeds. |
| Body filler and primer | 1 set | Bondo/Evercoat + filler primer | Adhesion coupon on PETG is recommended. |
| Play sand | ~5 kg | Hardware store | Dry thoroughly before fill. |

## CAD-Critical Purchased Parts

Buy or at least download official drawings for these before cutting geometry:

- E150HE-44 driver.
- E180HE-PR passive radiator.
- GX16-4 connector.
- Heyco SR-6P-4 strain relief.
- Heat-set inserts.

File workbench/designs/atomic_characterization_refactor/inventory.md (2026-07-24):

<!-- Generated by render_phase_a_reports.py from atomic_manifest.json. Do not edit by hand. -->

# Authoritative input inventory

Authority: `atomic_manifest.json`. Paths are repository-relative.

Historical selected-input rows are preserved in the manifest. Current combined-base source/validator identities below apply the explicit `current_refactor_execution.inventory_overrides` overlay.

## Selected inputs

| ID | Catalog/lifecycle | Role | Exact path | SHA-256 | Freshness | Demonstrated contribution | Unresolved |
|---|---|---|---|---|---|---|---|
| R.clean_bucket | none; derived evidence | STEP-derived candidate contribution | workbench/designs/canonical_working_set/enclosures/removable_front_baffle/links/near_perfect_bucket.step | eaeed68103e3110ca3e888ece90002a7f2f98a8b174fab5906e7fb0bd9350b97 | hash-bound, accepted only as recovery evidence | wanted sculpted left/right/top seating seam; four unwanted corner/fill-port hunks removed | wrong bottom material ownership; no authoritative parameterized source |
| R.bottom_ownership_assembly | none; derived evidence from active closure lineage | archived hybrid assembly contribution | workbench/designs/canonical_working_set/enclosures/removable_front_baffle/links/bottom_ownership_assembly.step | 90558975e0e8fb735534b53a73eb7970d3bdddd6aeda34fb821380915877bab0 | hash-bound historic artifact | intended complementary bottom material ownership; larger first rigid solid is the relevant bucket | predates clean-corner result; not an accepted whole design |
| R.flat_bottom_baffle | none; derived evidence from active closure lineage | approved flat-print-edge contribution only | workbench/designs/canonical_working_set/enclosures/removable_front_baffle/links/flat_bottom_baffle.step | 23c4d67927bbec6702c300c9912a7542383de093940378184b3d932fee3971c2 | hash-bound historic artifact | documented flat full-width lower edge for vertical baffle printing | does not approve its complete tongue/groove, gasket, hinge, fastener or seam geometry; exact bed-contact area is not programmatically established |
| R.active_source | development-190x210-tongue-groove: development; exp-190x210-simple-tongue-groove: active | current leaf source owner | experiments/sand_cube_190x210_internal_squat_absorber_rear_corners_parabolic_side_g1_simple_tongue_groove_baffle/generate_sand_cube_190x210_internal_squat_absorber_rear_corners_parabolic_side_g1_simple_tongue_groove_baffle.py | d67d011f3a1be1bf563786befb1af09fe74e4438e061abf670f0f3aef7cc0e62 | current geometry leaf on the combined refactor base | delegates explicit Variant R seam/bottom composition with serialized legacy containment; retention alternatives are absent | historical deep ancestry remains only behind the immutable foundation producer; the accepted flat-bottom missing-material relationship is intentionally unchanged |
| R.validator | validator of development-190x210-tongue-groove | programmatic fit/section validator | experiments/sand_cube_190x210_internal_squat_absorber_rear_corners_parabolic_side_g1_simple_tongue_groove_baffle/validate_simple_tongue_groove_baffle.py | 947c02b451f1a36ed05622c7b79a8751ea48311887bf6f555420b3363e1ceb74 | current and runnable after the cataloged authoritative base producer | checks complete part retention, protected seam occupancy, flat-bottom behavior, print contract, input attestation, validity, mating contact and STEP round trips | physical print behavior remains unverified; geometry correction is deferred |
| R.handoff | none | chronological source-boundary record | workbench/designs/canonical_working_set/enclosures/removable_front_baffle/links/active_source/HANDOFF.md | 6732d270cda9ed509808fffad13e1038b509fe64b3182ed599995f1fd5f4184c | supersedes stale green claims in leaf README | states the current physical mismatch and protected seam requirements | describes later bottom transfer and fastener work, not an accepted source baseline |
| I.full_perimeter_bucket | none; derived evidence | historic full-perimeter removable bucket reference | workbench/designs/canonical_working_set/enclosures/integral_front_bottom_hatch/links/full_perimeter_bucket.step | 39e6b2d95317d2348afd992ceda2e98d16a383820a3846737e21228ef1c41486 | hash-bound; source/artifact identity not current | documents the full-perimeter centered-captive-nut enclosure state | is still a removable-front bucket, not an integral-front/open-bottom enclosure |
| I.full_perimeter_baffle | none; derived evidence | historic removable baffle reference | workbench/designs/canonical_working_set/enclosures/integral_front_bottom_hatch/links/full_perimeter_baffle.step | 1dd518458c8fed6792c4acd91f0717b353288c18e49c5b1c6ba31f2c9cc6af03 | hash-bound; source/artifact identity not current | preserves a full-perimeter front composition reference | must not be mistaken for a permanent integral front |
| I.full_perimeter_assembly | none; derived evidence | historic assembly reference | workbench/designs/canonical_working_set/enclosures/integral_front_bottom_hatch/links/full_perimeter_assembled.step | 4595684887c4fb239dd8fefaeb7307a797c3673281df19f3d709b659b3440bf2 | hash-bound; source/artifact identity not current | records full-perimeter external composition and hardware/gasket placement | contains removable-joint semantics and multiple solids; no bottom hatch |
| I.full_perimeter_diagnostics | none; derived diagnostics | historic semantic measurements | workbench/designs/canonical_working_set/enclosures/integral_front_bottom_hatch/links/full_perimeter_diagnostics.json | 7194ac15b3c78e272ae60d9b1115be6129f0fdfbfd7cbfdcef32593cddbff04d | internally stale identity | records 190x210x190, 2/3/2 walls, 40 mm bore, 4.406 L net volume and 39.174 Hz historic estimates | file name/status/path identities span lightweight and front-fill monkeypatch stages; not proof of current source reproduction |
| I.pre_split_source | exp-190x210-lightweight-coherent-closure: supporting | semantic pre-split branch location and current closure source | workbench/designs/canonical_working_set/enclosures/integral_front_bottom_hatch/links/pre_split_source/generate_sand_cube_190x210_internal_squat_absorber_rear_corners_parabolic_side_g1_lightweight_coherent_closure.py | 0f318a52cf4148d2f2367a18176867acfad76e5a6827d77ca42e5395ce43ba2a | historical source at immutable commit 789cf7f; reproducible only as the accepted Variant R foundation through the capture recipe | identifies the accepted pre-split foundation boundary used by the current portable Variant R producer | not an independent Variant I owner; no integral-front/open-bottom/hatch geometry exists |
| I.nested_source | exp-190x210-nested-seam-concepts: historical | historical split-envelope ancestor | workbench/designs/canonical_working_set/enclosures/integral_front_bottom_hatch/links/nested_seam_ancestor/generate_sand_cube_190x210_internal_squat_absorber_rear_corners_parabolic_side_g1_nested_seam_closure_concepts.py | 02e415cd5a83d61fe9c01d54153c21d8e41a293eb17e45aa6a4bc53986d97f42 | current historical source | makes the nominal/clearance split concept identifiable | not an integral-front owner and remains embedded in a mutation chain |
| tube.reference | none; derived evidence | historic rear-corner tube reference | workbench/designs/canonical_working_set/acoustics/bass_reflex_tube/links/tube_reference.step | 5667fa455b81f8fc0f9a4645677a359f7b9072f0750eaff4f39a2099255fa19c | hash-bound historic artifact | continuous nominal 40 mm bore routing and six-solid serviceable assembly reference | not integrated; historic route/tuning/package only |
| tube.diagnostics | none; derived diagnostics | historic route measurements | workbench/designs/canonical_working_set/acoustics/bass_reflex_tube/links/route_diagnostics.json | dce0dcd3452ee8a98cea69073a52b3c3a299e42ec1a0e5bd716197cbf27af913 | older than current base-source parameter state | records historic route, bore, length, volume and packaging semantics | current single-oval source computes about 39.24 mm equivalent bore, so artifact/source freshness is not established |
| tube.route_source | exp-190x210-rear-corners: supporting | route source owner | workbench/designs/canonical_working_set/acoustics/bass_reflex_tube/links/route_source/generate_sand_cube_190x210_internal_squat_absorber_rear_corners.py | 1b2fcd344726f192b37e9081b6e41588b797a1a35e3301600ba2dbe77455307d | current source; selected artifact not reproduced in Phase A | owns rear-corner routing composition | depends on mutable earlier tube stages and future enclosure keepouts/access |
| resonator.rev_c_placement | none; derived evidence | Rev C mechanical-placement reference | workbench/designs/canonical_working_set/acoustics/d_squat_resonator/links/integrated_rev_c_placement.step | a16aeb1b440ef94a3cb208e4388eeac9c2acec238791fde4c33ebf0a3a4788ce | hash-bound historic artifact | mechanical placement and four-solid interface reference | not acoustic proof and not automatically superseded by Rev D |
| resonator.rev_d_assembly | none; derived evidence | Rev D acoustic/calibration assembly | workbench/designs/canonical_working_set/acoustics/d_squat_resonator/links/rev_d_assembly.step | 3ed5020cf53511f676ec3ed9a709d44a81e112f5b91fb1757dfbf09f4fcb33da | hash-bound study artifact | latest two-solid Rev D geometry and wider nominal slot study | not production validated; not an accepted mechanical replacement |
| resonator.rev_d_print_layout | none; derived evidence | Rev D print-layout study | workbench/designs/canonical_working_set/acoustics/d_squat_resonator/links/rev_d_print_layout.step | 5936001348ce7d146519a8836507d6800b703cce71f0a3d808f2df20f818d76e | hash-bound study artifact | five-solid print layout reference | does not validate enclosure access or physical acoustics |
| resonator.rev_d_diagnostics | none; derived diagnostics | Rev D acoustic/calibration record | workbench/designs/canonical_working_set/acoustics/d_squat_resonator/links/rev_d_diagnostics.json | b2486dd92bda832be28b2d1e0b54666c06e0641924a2231283b8c37717a28c01 | hash-bound study diagnostics | records 338.25 Hz target, 337.18 Hz prediction, wider 0.4 mm nominal slot, 40 mm continuous bore and zero modeled intrusion | physical bare-port measurements are still required |
| resonator.rev_c_generator | exp-190x210-port-absorber-d-squat: study | Rev C generator | workbench/designs/canonical_working_set/acoustics/d_squat_resonator/links/rev_c_source/generate_port_absorber_slotted_d_squat.py | 9bcb1a728add4fa1b306158da1e782cf9c8441275fcf7ccc90c092a6259fbf97 | current selected source; not executed in Phase A | owns the Rev C study entrypoint | deferred component |
| resonator.rev_c_model | supporting source of exp-190x210-port-absorber-d-squat | Rev C geometry model | workbench/designs/canonical_working_set/acoustics/d_squat_resonator/links/rev_c_source/model.py | 38204b0194edb46bb650cfe5c6f32450e55646c941bd397493e73a68f75f049b | current selected source | separates Rev C model construction | deferred component |
| resonator.rev_c_duct | supporting source of exp-190x210-port-absorber-d-squat | Rev C duct policy | workbench/designs/canonical_working_set/acoustics/d_squat_resonator/links/rev_c_source/duct.py | bf78e1a790b236646c4c96af1c6e63d2d8a8ec271316a8368c8271bec0723f03 | current selected source | owns duct calculations | deferred component |
| resonator.rev_c_robust | supporting source of exp-190x210-port-absorber-d-squat | Rev C robustness calculations | workbench/designs/canonical_working_set/acoustics/d_squat_resonator/links/rev_c_source/robust.py | 9bda9c976dac9a7030ad29c9cec2b4399c99aee74a782f11caa44229318ed9b7 | current selected source | owns uncertainty/robustness helpers | deferred component |
| resonator.rev_c_verify | supporting source of exp-190x210-port-absorber-d-squat | Rev C validator | workbench/designs/canonical_working_set/acoustics/d_squat_resonator/links/rev_c_source/verify.py | 028a728c113d1315a517510adc0e911c8c86ca118b2d989d12d6c4faaa949092 | current selected source | owns study verification | not physical validation |
| resonator.rev_d_generator | exp-190x210-port-absorber-d-squat-rev-d: study | Rev D study generator layered on Rev C modules | workbench/designs/canonical_working_set/acoustics/d_squat_resonator/links/rev_d_source/generate_port_absorber_slotted_d_squat_rev_d.py | e7c320c4e1514f9459e82b94e6bba4a58877ff2591b3ed7d1e4c6fc5f18ba9f1 | current selected source; not executed in Phase A | owns Rev D parameter/calibration differences | deferred and not production validated |
| horn.current_api | final-jmlc-horn: stable | stable horn API | workbench/designs/canonical_working_set/horn/links/current_api.py | 215f549cdaeed933abb0ac1b1f86def0839952b3b5dcb552ded620064c69f99a | current source | provides the current B&C DE250 JMLC horn construction entrypoint | default uses legacy recurrence and current horn may exceed future enclosure package |
| horn.profile_geometry | supporting source of final-jmlc-horn | formula and exact revolved/thickened/NURBS geometry | workbench/designs/canonical_working_set/horn/links/profile_geometry.py | 0078a6c58f4cce4310b7d7f4e1c46043b67fb837ee0ef57874513af6789c94d8 | current source | contains Le Cleac'h/JMLC profile and the Onshape-safe wall construction | no smaller horn parameter owner exists |
| horn.shared_parameters | shared parameters | legacy global parameter owner | workbench/designs/canonical_working_set/horn/links/shared_parameters.py | 47bfaa90eaa62652c944e2d910e3b93dd3d3a1b6b2ec8590668a8c5274c1715c | current source | owns throat 25.4 mm, wall 3.2 mm and current horn calculation inputs | also owns unrelated 203 mm enclosure values and must not silently own a future smaller horn |
| horn.work_summary | none | construction/provenance record | workbench/designs/canonical_working_set/horn/links/horn_work_summary.md | bb8c9ad982ce7fd70fb6b1d9cf9fbace82539edb24ee012cb4c4dcccbf4edc46 | current selected documentation | documents the validated exact-surface, thickened, NURBS STEP path | not enclosure-integration evidence |
| horn.rolled_study | supporting JMLC study | historical rolled-cube study | workbench/designs/canonical_working_set/horn/links/jmlc_studies/generate_rolled_cube.py | 4ce10a2ae93041609353824ab8e173040055fcfd4a94264fca12e09a73b630be | current selected historical source | preserves a formula/construction study | not an accepted enclosure horn |

Every selected input has `sidecar_sha256: null` and `image_hashes: []` unless explicitly listed in the manifest. The input landing selected no sidecars or images.

## Group-resolved inventory fields

Each selected ID inherits the row matching its prefix. This is the manifest's machine-readable resolution rule, not a second authority.

| Prefix | Parameter ownership | Units/datums/transforms | Construction and hidden ancestry | Outputs and validators | Consumers | Confidence / uncertainty |
|---|---|---|---|---|---|---|
| R. | src/enclosure_family/variant_r/parameters.py owns current Variant R dimensions and tolerances; src/enclosure_family/datums.py owns the proven family coordinate frame | mm; design coordinates X left/right, Y front/rear with front=-Y, Z bottom/top; all accepted artifacts are in assembly coordinates with no additional transform | src/enclosure_family/variant_r/assembly.py owns Variant R seam/lower-material composition over an explicit VariantRFoundation; seam.py and bottom_ownership.py own the extracted geometry; the active leaf is a compatibility adapter for the serialized legacy foundation<br>the 33-stage historical ancestry is used only by the immutable accepted-base producer at commit 789cf7f; the active composer receives explicit foundation dependencies and legacy bindings are restored and serialized | cataloged producer scripts/generate_variant_r.py publishes the authoritative base plus complete attestation; the current validator publishes bucket, baffle, six protected sections and diagnostics; final immutable identities are committed in final-acceptance-evidence.json<br>the current validator and independent comparison adapter pass full-part validity/topology/bounds/mass, six protected sections, bidirectional material difference, interface/print diagnostics and STEP round trips | current Variant R only; driver/horn, fill, brace and later geometry correction remain separately scoped; Variant I imports no Variant R owner | high for exact current source/input/job/artifact identities and deterministic equivalence; physical print, gasket, leak and acoustic behavior remain unverified |
| I. | historic references inherit the same distributed removable-closure sources; future integral parameters have no owner | mm; historic artifacts use the same enclosure assembly coordinates; future open-bottom print transform is intent only | historic artifacts are bucket/baffle partition plus gasket/hardware; semantic future branch point is full_base before the nominal/clearance split; integral front/open bottom/hatch booleans do not exist<br>pre-split lightweight source still depends on the complete mutation chain; selected diagnostics mix lightweight/front-fill stage identity | only hash-bound historic full-perimeter bucket, baffle, assembly and diagnostics; no Variant I output root<br>historic diagnostics only; no independent Variant I validator | future Variant I independent owner<br>future open-bottom/hatch synthesis | high that selected artifacts are removable-front geometry; high that future I geometry is absent; low source/artifact freshness |
| tube. | single-oval-port owns current bore/base values; header/serviceable/absorber/rear-corner stages own route composition | mm; selected tube is positioned in enclosure design coordinates and contains six rigid solids | base bore/duct, header, serviceable tower, internal absorber and rear-corner routing through nested source mutation<br>route source delegates through single-oval/header/serviceable/absorber ancestry; current source values differ from historic diagnostics | hash-bound tube_reference.step and route_diagnostics.json; no Phase A regeneration<br>historic route diagnostics and geometric continuity assertions; no current enclosure-fit validation | future enclosure keepouts<br>net-volume accounting<br>service path<br>resonator interface | high artifact geometry metrics; medium historic 40 mm route semantics; low current source/artifact equivalence |
| resonator. | Rev C model/duct/robust modules own mechanical study; Rev D generator owns its wider-slot/calibration differences | mm; Rev C placement is in enclosure coordinates; Rev D assembly is in local coordinates; Rev D print layout includes explicit separated part transforms | D-squat body/duct/cavity/slot construction, assembly composition and separate print-layout placement<br>Rev D imports Rev C generator/model/duct rather than replacing them; the two revisions intentionally remain distinct | hash-bound Rev C placement STEP, Rev D assembly/layout STEP and Rev D diagnostics<br>Rev C verify.py and Rev D diagnostics; neither replaces physical acoustic measurement | future tube mechanical interface<br>future physical calibration task | high artifact metrics and revision distinction; medium CAD acoustic prediction; physical target validation explicitly unknown |
| horn. | params.py owns current legacy DE250/JMLC inputs; final_horn.py exposes API; features/horn.py owns recurrence/profile and exact revolved/thickened/NURBS construction | mm and degrees; local horn construction revolves an XZ profile about Axis.Z with nonnegative radius; no selected STEP or enclosure transform | JMLC meridian calculation, exact acoustic surface revolution, wall thickening and NURBS conversion; no enclosure integration<br>stable API calls feature builder; current default selects legacy recurrence while 2007 formula also exists | formula/source references only in selected input set; no selected current STEP, sidecar or image<br>Onshape-safe health signs documented: one solid, no boundary/non-manifold edges, no interference and no OFFSET_SURFACE entities | future horn parameter owner<br>driver mount<br>bracket clamp stack<br>enclosure package | high formula/source provenance; low fit to 190 mm enclosure because current mouth is 222.463 mm |

## Historical Phase A source ancestry snapshot

These 19 rows preserve the initial characterization snapshot. The current exact producer and release dependency sets, including every loaded path/revision/hash, are `variant-r-producer-source-closure.json` and `variant-r-release-source-closure.json`; compact final release identity is in `final-acceptance-evidence.json`.

| Order | Path | SHA-256 | Responsibility / mutation |
|---:|---|---|---|
| 1 | experiments/sand_cube_190x210_single_oval_port/generate_sand_cube_190x210_single_oval_port.py | 0ebe233087fb8724e89254385e5f00e8f3a197fbb3bb9e202e97874c73c3e3a8 | monolithic 190x210 base, outer/inner stack, port origin and base exports |
| 2 | experiments/sand_cube_190x210_header_port/generate_sand_cube_190x210_header_port.py | c20df6ac1eb83616babdb844eb8f1f336725eed714101bebe58d7f0d98d2b5ab | header-port mutation stage |
| 3 | experiments/sand_cube_190x210_serviceable_tower/generate_sand_cube_190x210_serviceable_tower.py | 3ef3e25ba9d1811ca32bcab4d9457beaff3a38052375619f88edb1d1e3d43a7b | serviceable tower and access mutation stage |
| 4 | experiments/sand_cube_190x210_internal_squat_absorber/generate_sand_cube_190x210_internal_squat_absorber.py | b3a8fdb7276c6dcca4a6c777083cdda1c27e4e673e540c884712ff5650d888c1 | internal absorber stage |
| 5 | experiments/sand_cube_190x210_internal_squat_absorber_rear_corners/generate_sand_cube_190x210_internal_squat_absorber_rear_corners.py | 1b2fcd344726f192b37e9081b6e41588b797a1a35e3301600ba2dbe77455307d | rear-corner tube routing and supporting enclosure base |
| 6 | experiments/sand_cube_190x210_internal_squat_absorber_rear_corners_parabolic_side_g1_conformal_inner_wall/generate_sand_cube_190x210_internal_squat_absorber_rear_corners_parabolic_side_g1_conformal_inner_wall.py | 6d8f7acf40493122541a89bf7e0e81cc4c094c0c3846d11c48cf8ff61ff9fbb7 | conformal inner-wall contribution |
| 7 | experiments/sand_cube_190x210_internal_squat_absorber_rear_corners_parabolic_side_g1_conformal_full_system/generate_sand_cube_190x210_internal_squat_absorber_rear_corners_parabolic_side_g1_conformal_full_system.py | a0e4547175f895c0b62add705139690cbd0bf613f330575945df20c783eea0e7 | _full_detail_base combines rear-corner base, conformal wall and braces |
| 8 | experiments/sand_cube_190x210_internal_squat_absorber_rear_corners_parabolic_side_g1_printable_bucket/generate_sand_cube_190x210_internal_squat_absorber_rear_corners_parabolic_side_g1_printable_bucket.py | 3af310dd86097db27b19a7ee621350ada1cc215fbfb97497dba8490a2007077f | printable bucket split/orientation helpers and rear-detail wrapper |
| 9 | experiments/sand_cube_190x210_internal_squat_absorber_rear_corners_parabolic_side_g1_hooked_gasketed_baffle/generate_sand_cube_190x210_internal_squat_absorber_rear_corners_parabolic_side_g1_hooked_gasketed_baffle.py | eee63214daa54477e616defcd9c818ad572816a7e98c6ce6a788539ede9a79e4 | baffle bed plane, gasket source, shoulder and rounded-rectangle helpers |
| 10 | experiments/sand_cube_190x210_internal_squat_absorber_rear_corners_parabolic_side_g1_nested_seam_closure_concepts/generate_sand_cube_190x210_internal_squat_absorber_rear_corners_parabolic_side_g1_nested_seam_closure_concepts.py | 02e415cd5a83d61fe9c01d54153c21d8e41a293eb17e45aa6a4bc53986d97f42 | nominal/clearance nested split envelope |
| 11 | experiments/sand_cube_190x210_internal_squat_absorber_rear_corners_parabolic_side_g1_centered_captive_nut/generate_sand_cube_190x210_internal_squat_absorber_rear_corners_parabolic_side_g1_centered_captive_nut.py | 24a0809b328be514a4f2cb5fafa3d893da1b0e39a3b7025498f5a556a5acda63 | full-perimeter centered-captive-nut closure stage |
| 12 | experiments/sand_cube_190x210_internal_squat_absorber_rear_corners_parabolic_side_g1_forward_captive_square_nut/generate_sand_cube_190x210_internal_squat_absorber_rear_corners_parabolic_side_g1_forward_captive_square_nut.py | faef5c95213dd331aaefd784ee6e19514ba2594ded216aa3ecd0b17e8a751388 | forward captive-square-nut mutation stage |
| 13 | experiments/sand_cube_190x210_internal_squat_absorber_rear_corners_parabolic_side_g1_dual_captive_square_nut_printable/generate_sand_cube_190x210_internal_squat_absorber_rear_corners_parabolic_side_g1_dual_captive_square_nut_printable.py | 65ade227ab410e60ed394006543ebbddbfc14f0b314eaa38431357e0269c3844 | dual-nut and printable closure mutation stage |
| 14 | experiments/sand_cube_190x210_internal_squat_absorber_rear_corners_parabolic_side_g1_front_fill_perimeter_seal/generate_sand_cube_190x210_internal_squat_absorber_rear_corners_parabolic_side_g1_front_fill_perimeter_seal.py | 8df747bdc01c16cd157cf28f03cdd549ab9ccfa99530b37ed6515e33098cd936 | front fill passages, sealing sectors and rear-without-fill wrapper |
| 15 | experiments/sand_cube_190x210_internal_squat_absorber_rear_corners_parabolic_side_g1_simplified_printable_closure/generate_sand_cube_190x210_internal_squat_absorber_rear_corners_parabolic_side_g1_simplified_printable_closure.py | 2ed7cddafdd4dd13817d124468a5dba5aede13a77553ed9ccc37b8a524928d84 | current sculpted path parameters, 184.3 mm/r7 broad reset, fill positions, support thresholds and printable longitudinal rails |
| 16 | experiments/sand_cube_190x210_internal_squat_absorber_rear_corners_parabolic_side_g1_single_land_corner_fasteners/generate_sand_cube_190x210_internal_squat_absorber_rear_corners_parabolic_side_g1_single_land_corner_fasteners.py | 029ff70e4f47ade1d10b7c3e50775a90a67ece0581c0dab9ef9610a84824c6bb | single-land corner-fastener closure stage |
| 17 | experiments/sand_cube_190x210_internal_squat_absorber_rear_corners_parabolic_side_g1_systemic_joint_recessed_fasteners/generate_sand_cube_190x210_internal_squat_absorber_rear_corners_parabolic_side_g1_systemic_joint_recessed_fasteners.py | efa5381674d56d2d4e727ffbfe3c63424c16d087661b2ad3f4d7dd297cc75c8a | systemic joint and recessed-fastener mutation stage |
| 18 | experiments/sand_cube_190x210_internal_squat_absorber_rear_corners_parabolic_side_g1_lightweight_coherent_closure/generate_sand_cube_190x210_internal_squat_absorber_rear_corners_parabolic_side_g1_lightweight_coherent_closure.py | 0f318a52cf4148d2f2367a18176867acfad76e5a6827d77ca42e5395ce43ba2a | current pre-split full_base, common joint, 3 mm bulkhead plate, support wedge, fill passages and coherent braces; temporarily patches many ancestors |
| 19 | experiments/sand_cube_190x210_internal_squat_absorber_rear_corners_parabolic_side_g1_simple_tongue_groove_baffle/generate_sand_cube_190x210_internal_squat_absorber_rear_corners_parabolic_side_g1_simple_tongue_groove_baffle.py | 496a9d9797e0b27d14b8762a2a7bc5efac8c7c747e13308265c5ca65fa3f6f7c | active leaf replaces perimeter wire and closure constants, then delegates the entire build |

## Coordinate and construction contract

- units: mm<br>design_axes: X: left/right; selected enclosure exterior spans approximately -95 to +95<br>Y: front/rear; front exterior is near -95 and rear exterior near +115<br>Z: bottom/top; selected enclosure exterior spans approximately -95 to +95<br>selected_family_envelope_mm: 190.0<br>210.0<br>190.0<br>selected_family_wall_stack_mm: outer_skin: 2.0<br>sand_void: 3.0<br>inner_skin: 2.0<br>conflict: Repository-level legacy contract and params.py describe a 203 mm, 3/12/3 enclosure. Those values are not silently shared with this 190x210 family.

- Construction stages: the immutable producer reconstructs the accepted base at exact geometry commit 789cf7f and attests every loaded dependency<br>the current active compatibility adapter imports that attested base and supplies the explicit VariantRFoundation boundary<br>src/enclosure_family/variant_r/assembly.py composes the extracted seam and lower-material owners without Variant I flags<br>measurement, equivalence, STEP publication, provenance and evidence adapters consume geometry without owning it<br>the current release publishes complete parts, six protected sections, diagnostics and exact source/job/artifact identity

- Output/validation boundary: catalog_model: development-190x210-tongue-groove<br>output_root: build/sand_cube_190x210_internal_squat_absorber_rear_corners_parabolic_side_g1_simple_tongue_groove_baffle<br>producer: scripts/generate_variant_r.py<br>validator: experiments/sand_cube_190x210_internal_squat_absorber_rear_corners_parabolic_side_g1_simple_tongue_groove_baffle/validate_simple_tongue_groove_baffle.py<br>authoritative_input_sha256: 441cc122c0383da257b16e80c4b424096f33b267cc95cab9d1278fb05a43a784<br>producer_job_id: 20260724T083757-atomic-refactor-final2-producer-5f287edf8b<br>release_job_id: 20260724T102722-atomic-refactor-landing-restored-release-52bd80460c<br>strict_job_id: 20260724T105504-atomic-refactor-landing-strict-a9945e2f37<br>current_state: pass; ignored build artifacts are derived and their immutable hashes, jobs, producer/source identities, measurements and attestations are committed in the source-closure and final-acceptance records

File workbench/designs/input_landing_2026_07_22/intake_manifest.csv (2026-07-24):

decision | source_checkout | source_path | file_type | sha256 | size_bytes | source_state | intended_owner | reason | catalog_identity | dependency_relationship | classification | canonical_checksum
reviewed-subset | primary-dirty@ea5539f3372e1bad5ad05eba85f4bd9a53e8c868 | .cad-project/models.toml | toml | 26d1ebd0e818829731dde58f6b7b536d90dbbb1c39b654576441ad417fb76ab7 | 21666 | modified | .cad-project/models.toml | dirty catalog investigated; only selected model/experiment records will be reconstructed | supporting active-enclosure lineage | catalog identity and lifecycle map | documentation | no
selected-promote | primary-dirty@ea5539f3372e1bad5ad05eba85f4bd9a53e8c868 | build/sand_cube_190x210_internal_squat_absorber_rear_corners/diagnostics.json | JSON | dce0dcd3452ee8a98cea69073a52b3c3a299e42ec1a0e5bd716197cbf27af913 | 51330 | ignored-derived | workbench/designs/canonical_working_set/acoustics/bass_reflex_tube/reference_evidence/diagnostics.json | portable immutable evidence selected by canonical working set | exp-190x210-rear-corners | hash-bound evidence for acoustics/bass_reflex_tube | derived evidence | yes:acoustics/bass_reflex_tube/links/route_diagnostics.json:dce0dcd3452ee8a98cea69073a52b3c3a299e42ec1a0e5bd716197cbf27af913
selected-promote | primary-dirty@ea5539f3372e1bad5ad05eba85f4bd9a53e8c868 | build/sand_cube_190x210_internal_squat_absorber_rear_corners_parabolic_side_g1_lightweight_coherent_closure/centered_captive_nut_assembled.step | STEP | 4595684887c4fb239dd8fefaeb7307a797c3673281df19f3d709b659b3440bf2 | 13810764 | ignored-derived | workbench/designs/canonical_working_set/enclosures/integral_front_bottom_hatch/reference_evidence/centered_captive_nut_assembled.step | portable immutable evidence selected by canonical working set | exp-190x210-lightweight-coherent-closure | hash-bound evidence for enclosures/integral_front_bottom_hatch | derived evidence | yes:enclosures/integral_front_bottom_hatch/links/full_perimeter_assembled.step:4595684887c4fb239dd8fefaeb7307a797c3673281df19f3d709b659b3440bf2
selected-promote | primary-dirty@ea5539f3372e1bad5ad05eba85f4bd9a53e8c868 | build/sand_cube_190x210_internal_squat_absorber_rear_corners_parabolic_side_g1_lightweight_coherent_closure/centered_captive_nut_baffle.step | STEP | 1dd518458c8fed6792c4acd91f0717b353288c18e49c5b1c6ba31f2c9cc6af03 | 8687475 | ignored-derived | workbench/designs/canonical_working_set/enclosures/integral_front_bottom_hatch/reference_evidence/centered_captive_nut_baffle.step | portable immutable evidence selected by canonical working set | exp-190x210-lightweight-coherent-closure | hash-bound evidence for enclosures/integral_front_bottom_hatch | derived evidence | yes:enclosures/integral_front_bottom_hatch/links/full_perimeter_baffle.step:1dd518458c8fed6792c4acd91f0717b353288c18e49c5b1c6ba31f2c9cc6af03
selected-promote | primary-dirty@ea5539f3372e1bad5ad05eba85f4bd9a53e8c868 | build/sand_cube_190x210_internal_squat_absorber_rear_corners_parabolic_side_g1_lightweight_coherent_closure/centered_captive_nut_bucket.step | STEP | 39e6b2d95317d2348afd992ceda2e98d16a383820a3846737e21228ef1c41486 | 4583193 | ignored-derived | workbench/designs/canonical_working_set/enclosures/integral_front_bottom_hatch/reference_evidence/centered_captive_nut_bucket.step | portable immutable evidence selected by canonical working set | exp-190x210-lightweight-coherent-closure | hash-bound evidence for enclosures/integral_front_bottom_hatch | derived evidence | yes:enclosures/integral_front_bottom_hatch/links/full_perimeter_bucket.step:39e6b2d95317d2348afd992ceda2e98d16a383820a3846737e21228ef1c41486
selected-promote | primary-dirty@ea5539f3372e1bad5ad05eba85f4bd9a53e8c868 | build/sand_cube_190x210_internal_squat_absorber_rear_corners_parabolic_side_g1_lightweight_coherent_closure/diagnostics.json | JSON | 7194ac15b3c78e272ae60d9b1115be6129f0fdfbfd7cbfdcef32593cddbff04d | 70504 | ignored-derived | workbench/designs/canonical_working_set/enclosures/integral_front_bottom_hatch/reference_evidence/diagnostics.json | portable immutable evidence selected by canonical working set | exp-190x210-lightweight-coherent-closure | hash-bound evidence for enclosures/integral_front_bottom_hatch | derived evidence | yes:enclosures/integral_front_bottom_hatch/links/full_perimeter_diagnostics.json:7194ac15b3c78e272ae60d9b1115be6129f0fdfbfd7cbfdcef32593cddbff04d
selected-promote | primary-dirty@ea5539f3372e1bad5ad05eba85f4bd9a53e8c868 | build/sand_cube_190x210_internal_squat_absorber_rear_corners_parabolic_side_g1_lightweight_coherent_closure/internal_d_squat_absorber_installed.step | STEP | a16aeb1b440ef94a3cb208e4388eeac9c2acec238791fde4c33ebf0a3a4788ce | 975988 | ignored-derived | workbench/designs/canonical_working_set/acoustics/d_squat_resonator/reference_evidence/internal_d_squat_absorber_installed.step | portable immutable evidence selected by canonical working set | exp-190x210-lightweight-coherent-closure | hash-bound evidence for acoustics/d_squat_resonator | derived evidence | yes:acoustics/d_squat_resonator/links/integrated_rev_c_placement.step:a16aeb1b440ef94a3cb208e4388eeac9c2acec238791fde4c33ebf0a3a4788ce
selected-promote | primary-dirty@ea5539f3372e1bad5ad05eba85f4bd9a53e8c868 | build/sand_cube_190x210_internal_squat_absorber_rear_corners_parabolic_side_g1_lightweight_coherent_closure/sand_cube_190x210_single_oval_port_internal_tube.step | STEP | 5667fa455b81f8fc0f9a4645677a359f7b9072f0750eaff4f39a2099255fa19c | 1094673 | ignored-derived | workbench/designs/canonical_working_set/acoustics/bass_reflex_tube/reference_evidence/sand_cube_190x210_single_oval_port_internal_tube.step | portable immutable evidence selected by canonical working set | exp-190x210-lightweight-coherent-closure | hash-bound evidence for acoustics/bass_reflex_tube | derived evidence | yes:acoustics/bass_reflex_tube/links/tube_reference.step:5667fa455b81f8fc0f9a4645677a359f7b9072f0750eaff4f39a2099255fa19c
selected-promote | primary-dirty@ea5539f3372e1bad5ad05eba85f4bd9a53e8c868 | build/sand_cube_190x210_internal_squat_absorber_rear_corners_parabolic_side_g1_simple_tongue_groove_baffle/hybrid_seam_assembled.step | STEP | 90558975e0e8fb735534b53a73eb7970d3bdddd6aeda34fb821380915877bab0 | 11094222 | ignored-derived | workbench/designs/canonical_working_set/enclosures/removable_front_baffle/reference_evidence/hybrid_seam_assembled.step | portable immutable evidence selected by canonical working set | development-190x210-tongue-groove; exp-190x210-simple-tongue-groove | hash-bound evidence for enclosures/removable_front_baffle | derived evidence | yes:enclosures/removable_front_baffle/links/bottom_ownership_assembly.step:90558975e0e8fb735534b53a73eb7970d3bdddd6aeda34fb821380915877bab0
selected-promote | primary-dirty@ea5539f3372e1bad5ad05eba85f4bd9a53e8c868 | build/sand_cube_190x210_internal_squat_absorber_rear_corners_parabolic_side_g1_simple_tongue_groove_baffle/simple_tongue_groove_baffle.step | STEP | 23c4d67927bbec6702c300c9912a7542383de093940378184b3d932fee3971c2 | 7245209 | ignored-derived | workbench/designs/canonical_working_set/enclosures/removable_front_baffle/reference_evidence/simple_tongue_groove_baffle.step | portable immutable evidence selected by canonical working set | development-190x210-tongue-groove; exp-190x210-simple-tongue-groove | hash-bound evidence for enclosures/removable_front_baffle | derived evidence | yes:enclosures/removable_front_baffle/links/flat_bottom_baffle.step:23c4d67927bbec6702c300c9912a7542383de093940378184b3d932fee3971c2
selected-promote | primary-dirty@ea5539f3372e1bad5ad05eba85f4bd9a53e8c868 | build/sand_cube_190x210_port_absorber_slotted_d_squat_rev_d/diagnostics.json | JSON | b2486dd92bda832be28b2d1e0b54666c06e0641924a2231283b8c37717a28c01 | 18725 | ignored-derived | workbench/designs/canonical_working_set/acoustics/d_squat_resonator/reference_evidence/diagnostics.json | portable immutable evidence selected by canonical working set | exp-190x210-port-absorber-d-squat-rev-d | hash-bound evidence for acoustics/d_squat_resonator | derived evidence | yes:acoustics/d_squat_resonator/links/rev_d_diagnostics.json:b2486dd92bda832be28b2d1e0b54666c06e0641924a2231283b8c37717a28c01
selected-promote | primary-dirty@ea5539f3372e1bad5ad05eba85f4bd9a53e8c868 | build/sand_cube_190x210_port_absorber_slotted_d_squat_rev_d/port_absorber_d_squat_rev_d_assembly_finished_reference.step | STEP | 3ed5020cf53511f676ec3ed9a709d44a81e112f5b91fb1757dfbf09f4fcb33da | 953398 | ignored-derived | workbench/designs/canonical_working_set/acoustics/d_squat_resonator/reference_evidence/port_absorber_d_squat_rev_d_assembly_finished_reference.step | portable immutable evidence selected by canonical working set | exp-190x210-port-absorber-d-squat-rev-d | hash-bound evidence for acoustics/d_squat_resonator | derived evidence | yes:acoustics/d_squat_resonator/links/rev_d_assembly.step:3ed5020cf53511f676ec3ed9a709d44a81e112f5b91fb1757dfbf09f4fcb33da
selected-promote | primary-dirty@ea5539f3372e1bad5ad05eba85f4bd9a53e8c868 | build/sand_cube_190x210_port_absorber_slotted_d_squat_rev_d/port_absorber_d_squat_rev_d_print_layout.step | STEP | 5936001348ce7d146519a8836507d6800b703cce71f0a3d808f2df20f818d76e | 811849 | ignored-derived | workbench/designs/canonical_working_set/acoustics/d_squat_resonator/reference_evidence/port_absorber_d_squat_rev_d_print_layout.step | portable immutable evidence selected by canonical working set | exp-190x210-port-absorber-d-squat-rev-d | hash-bound evidence for acoustics/d_squat_resonator | derived evidence | yes:acoustics/d_squat_resonator/links/rev_d_print_layout.step:5936001348ce7d146519a8836507d6800b703cce71f0a3d808f2df20f818d76e
selected-promote | primary-dirty@ea5539f3372e1bad5ad05eba85f4bd9a53e8c868 | build/workbench/enclosure_baffle_recovery/clean_corner_hunks_candidate_viewer/clean_corner_hunks_bucket.step | STEP | eaeed68103e3110ca3e888ece90002a7f2f98a8b174fab5906e7fb0bd9350b97 | 4310535 | ignored-derived | workbench/designs/canonical_working_set/enclosures/removable_front_baffle/reference_evidence/clean_corner_hunks_bucket.step | portable immutable evidence selected by canonical working set | supporting active-enclosure lineage | hash-bound evidence for enclosures/removable_front_baffle | derived evidence | yes:enclosures/removable_front_baffle/links/near_perfect_bucket.step:eaeed68103e3110ca3e888ece90002a7f2f98a8b174fab5906e7fb0bd9350b97
selected-base | origin/main@73b29e51434e4a139efcb09574f8dc1c94bd485f | cad_runner/entrypoint.py | Python | 3a711676bb3f52a051ee6eef4bd02535d7ac8c4444b6686ad3394e89516a36be | 2266 | tracked | cad_runner/entrypoint.py | pre-existing dependency required to import selected active lineage | supporting active-enclosure lineage | transitive active enclosure import closure | authoritative Python | no
selected-base | origin/main@73b29e51434e4a139efcb09574f8dc1c94bd485f | cad_runner/outputs.py | Python | 12ae84bc5fa82970db0209c22589009b1af4fd5bbf415e5387c0a00a2843095e | 1257 | tracked | cad_runner/outputs.py | pre-existing dependency required to import selected active lineage | supporting active-enclosure lineage | transitive active enclosure import closure | authoritative Python | no
selected-copy | primary-dirty@ea5539f3372e1bad5ad05eba85f4bd9a53e8c868 | docs/horn-print-and-viewer-work-summary.md | Markdown | bb8c9ad982ce7fd70fb6b1d9cf9fbace82539edb24ee012cb4c4dcccbf4edc46 | 3036 | modified | docs/horn-print-and-viewer-work-summary.md | source target named by canonical working set | supporting active-enclosure lineage | canonical navigation/source dependency | documentation | yes:horn/links/horn_work_summary.md:bb8c9ad982ce7fd70fb6b1d9cf9fbace82539edb24ee012cb4c4dcccbf4edc46
selected-base | origin/main@73b29e51434e4a139efcb09574f8dc1c94bd485f | experiments/jmlc_square_baffle/generate_rolled_cube.py | Python | 4ce10a2ae93041609353824ab8e173040055fcfd4a94264fca12e09a73b630be | 8433 | tracked | experiments/jmlc_square_baffle/generate_rolled_cube.py | source target named by canonical working set | exp-jmlc-square-baffle | canonical navigation/source dependency | authoritative Python | yes:horn/links/jmlc_studies/generate_rolled_cube.py:4ce10a2ae93041609353824ab8e173040055fcfd4a94264fca12e09a73b630be
selected-base | origin/main@73b29e51434e4a139efcb09574f8dc1c94bd485f | experiments/jmlc_square_baffle/explore_variants.py | Python | 63652bbb0a5d4ced123fff86746e97cb38f10c5303f06245ef1124372f6135a2 | 13907 | tracked | experiments/jmlc_square_baffle/explore_variants.py | pre-existing sibling dependency required to import the canonical JMLC study target | exp-jmlc-square-baffle | transitive import closure for canonical horn study | authoritative Python | no
selected-base | origin/main@73b29e51434e4a139efcb09574f8dc1c94bd485f | experiments/sand_cube_190x210_header_port/generate_sand_cube_190x210_header_port.py | Python | c20df6ac1eb83616babdb844eb8f1f336725eed714101bebe58d7f0d98d2b5ab | 21957 | tracked | experiments/sand_cube_190x210_header_port/generate_sand_cube_190x210_header_port.py | pre-existing dependency required to import selected active lineage | supporting active-enclosure lineage | transitive active enclosure import closure | authoritative Python | no
selected-base | origin/main@73b29e51434e4a139efcb09574f8dc1c94bd485f | experiments/sand_cube_190x210_internal_squat_absorber/generate_sand_cube_190x210_internal_squat_absorber.py | Python | b3a8fdb7276c6dcca4a6c777083cdda1c27e4e673e540c884712ff5650d888c1 | 20634 | tracked | experiments/sand_cube_190x210_internal_squat_absorber/generate_sand_cube_190x210_internal_squat_absorber.py | pre-existing dependency required to import selected active lineage | supporting active-enclosure lineage | transitive active enclosure import closure | authoritative Python | no
selected-base | origin/main@73b29e51434e4a139efcb09574f8dc1c94bd485f | experiments/sand_cube_190x210_internal_squat_absorber_flush/generate_sand_cube_190x210_internal_squat_absorber_flush.py | Python | 888fe48ad804c6ac49f5805d237dd7974b686cac1bc09eeec5e8ef6d049bb474 | 18468 | tracked | experiments/sand_cube_190x210_internal_squat_absorber_flush/generate_sand_cube_190x210_internal_squat_absorber_flush.py | pre-existing dependency required to import selected active lineage | supporting active-enclosure lineage | transitive active enclosure import closure | authoritative Python | no
selected-base | origin/main@73b29e51434e4a139efcb09574f8dc1c94bd485f | experiments/sand_cube_190x210_internal_squat_absorber_rear_corners/generate_sand_cube_190x210_internal_squat_absorber_rear_corners.py | Python | 1b2fcd344726f192b37e9081b6e41588b797a1a35e3301600ba2dbe77455307d | 18728 | tracked | experiments/sand_cube_190x210_internal_squat_absorber_rear_corners/generate_sand_cube_190x210_internal_squat_absorber_rear_corners.py | pre-existing dependency required to import selected active lineage | exp-190x210-rear-corners | transitive active enclosure import closure | authoritative Python | yes:acoustics/bass_reflex_tube/links/route_source/generate_sand_cube_190x210_internal_squat_absorber_rear_corners.py:1b2fcd344726f192b37e9081b6e41588b797a1a35e3301600ba2dbe77455307d
selected-base | origin/main@73b29e51434e4a139efcb09574f8dc1c94bd485f | experiments/sand_cube_190x210_internal_squat_absorber_rear_corners_inverse_le_cleach_front/solve_inverse_le_cleach_front.py | Python | cad887516e05aaeec02344ceb468f3613a3b55f9a3e5f14d86110418281f2ef0 | 20857 | tracked | experiments/sand_cube_190x210_internal_squat_absorber_rear_corners_inverse_le_cleach_front/solve_inverse_le_cleach_front.py | pre-existing dependency required to import selected active lineage | exp-190x210-rear-corners | transitive active enclosure import closure | authoritative Python | no
selected-base | origin/main@73b29e51434e4a139efcb09574f8dc1c94bd485f | experiments/sand_cube_190x210_internal_squat_absorber_rear_corners_le_cleach_front_15mm_g2_fairing/generate_sand_cube_190x210_internal_squat_absorber_rear_corners_le_cleach_front_15mm_g2_fairing.py | Python | 5d7f80726b325fdacfe455174d6d57ad4677d2ef6f848e37e1054ab46b3517a7 | 23432 | tracked | experiments/sand_cube_190x210_internal_squat_absorber_rear_corners_le_cleach_front_15mm_g2_fairing/generate_sand_cube_190x210_internal_squat_absorber_rear_corners_le_cleach_front_15mm_g2_fairing.py | pre-existing dependency required to import selected active lineage | exp-190x210-rear-corners | transitive active enclosure import closure | authoritative Python | no
selected-base | origin/main@73b29e51434e4a139efcb09574f8dc1c94bd485f | experiments/sand_cube_190x210_internal_squat_absorber_rear_corners_le_cleach_front_15mm_square_crop_r8/generate_sand_cube_190x210_internal_squat_absorber_rear_corners_le_cleach_front_15mm_square_crop_r8.py | Python | be7acc1b77bffee5b0b2ff92bcc283f70a670c1a488ff5dc706bbc0640b578ff | 23495 | tracked | experiments/sand_cube_190x210_internal_squat_absorber_rear_corners_le_cleach_front_15mm_square_crop_r8/generate_sand_cube_190x210_internal_squat_absorber_rear_corners_le_cleach_front_15mm_square_crop_r8.py | pre-existing dependency required to import selected active lineage | exp-190x210-rear-corners | transitive active enclosure import closure | authoritative Python | no
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

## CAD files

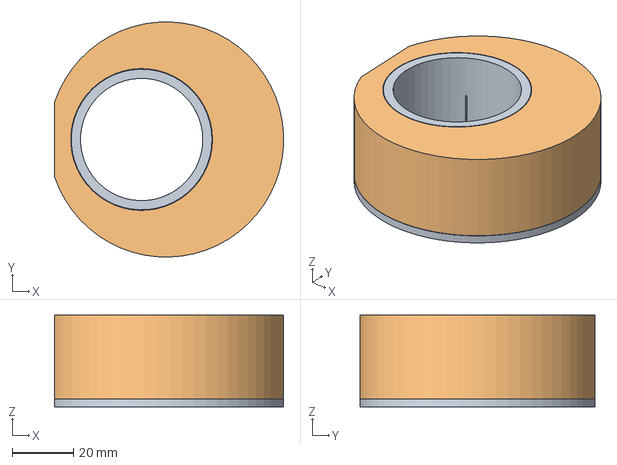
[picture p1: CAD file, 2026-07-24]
workbench/designs/canonical_working_set/acoustics/d_squat_resonator/reference_evidence/port_absorber_d_squat_rev_d_assembly_finished_reference.step
74.9 x 76.9 x 30.0 mm

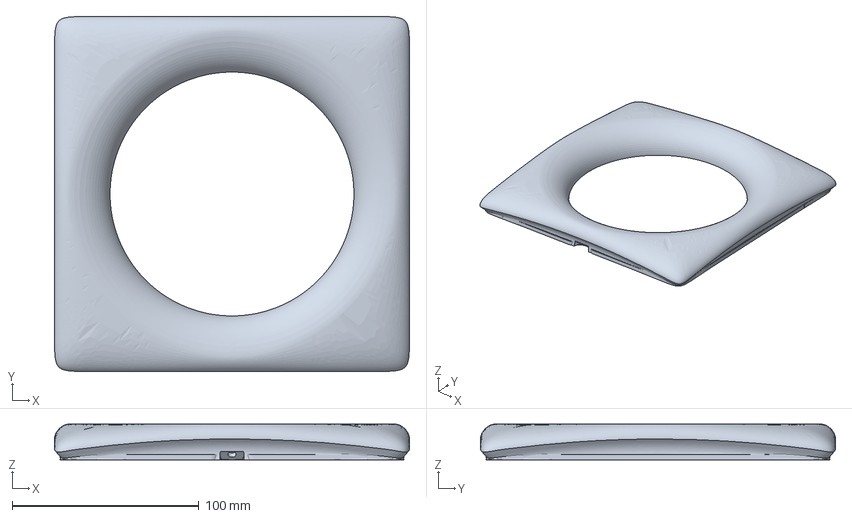
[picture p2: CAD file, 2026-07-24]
releases/enclosure_v1/front_baffle/artifacts/front_baffle_v1_x2d_pla_matte.3mf
190.0 x 190.0 x 19.2 mm

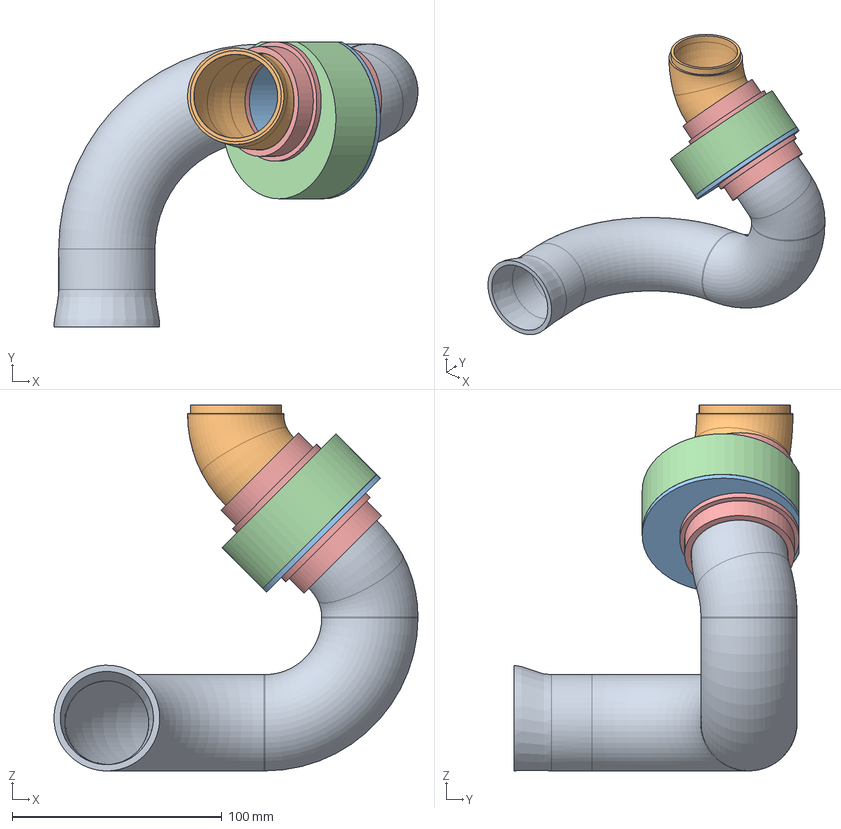
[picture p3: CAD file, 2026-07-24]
workbench/designs/canonical_working_set/acoustics/bass_reflex_tube/reference_evidence/sand_cube_190x210_single_oval_port_internal_tube.step
173.7 x 136.3 x 174.6 mm

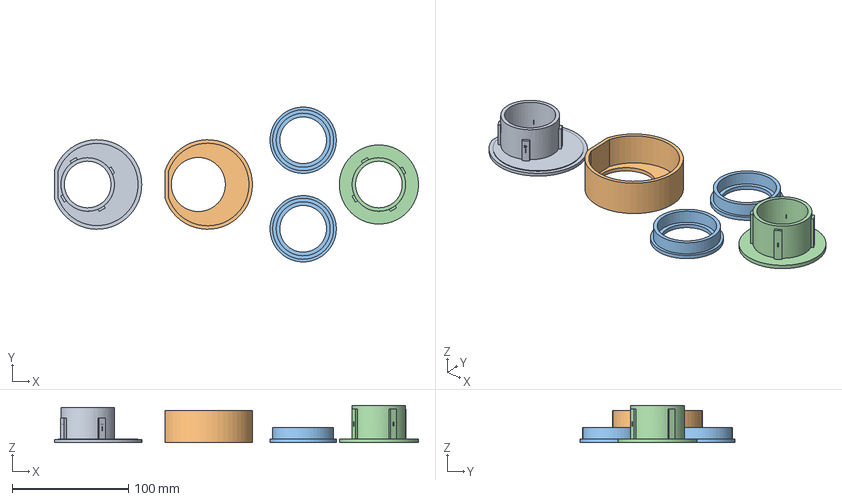
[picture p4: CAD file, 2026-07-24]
workbench/designs/canonical_working_set/acoustics/d_squat_resonator/reference_evidence/port_absorber_d_squat_rev_d_print_layout.step
312.5 x 133.0 x 32.0 mm

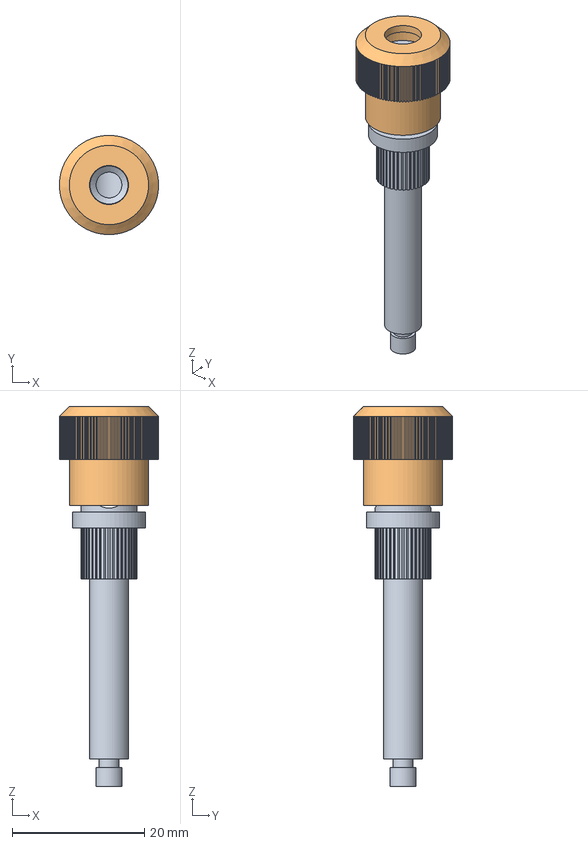
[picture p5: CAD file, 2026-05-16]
objects/Dayton Audio Binding Posts.stp
15.0 x 15.0 x 57.5 mm
Dayton Audio Binding Posts_1
Dayton Audio Binding Posts Cap

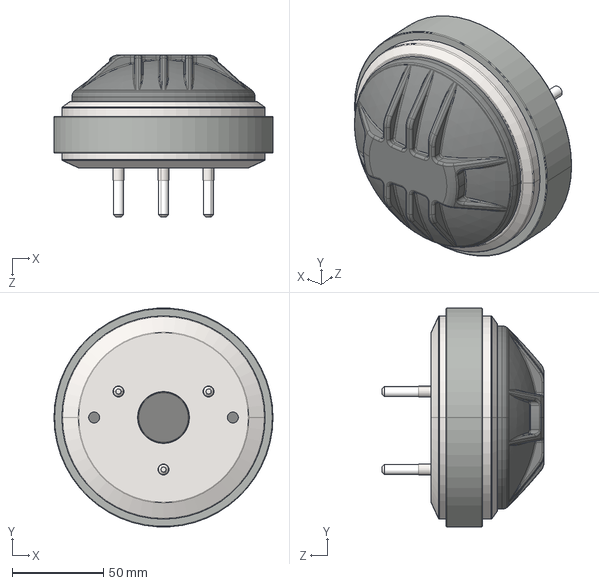
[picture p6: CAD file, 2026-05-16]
objects/Compression DriverDE250.step
120.0 x 119.8 x 89.0 mm

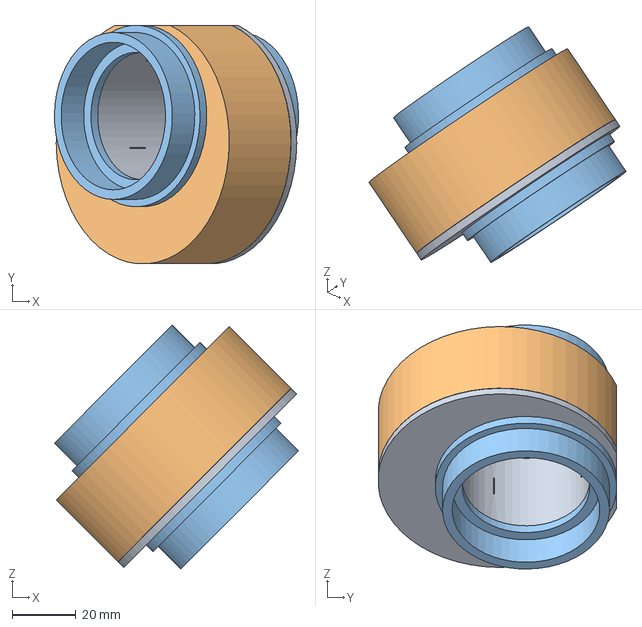
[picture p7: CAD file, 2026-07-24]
workbench/designs/canonical_working_set/acoustics/d_squat_resonator/reference_evidence/internal_d_squat_absorber_installed.step
76.6 x 74.9 x 76.6 mm

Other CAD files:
workbench/designs/canonical_working_set/enclosures/integral_front_bottom_hatch/links/full_perimeter_bucket.step
workbench/designs/canonical_working_set/enclosures/integral_front_bottom_hatch/links/full_perimeter_baffle.step
workbench/designs/canonical_working_set/enclosures/removable_front_baffle/links/bottom_ownership_assembly.step
workbench/designs/canonical_working_set/acoustics/d_squat_resonator/links/rev_d_assembly.step
workbench/designs/canonical_working_set/enclosures/integral_front_bottom_hatch/links/full_perimeter_assembled.step
releases/enclosure_v1/front_baffle/source/inputs/front_baffle_v1_bed_oriented_mesh.3mf
workbench/designs/canonical_working_set/acoustics/bass_reflex_tube/links/tube_reference.step
workbench/designs/canonical_working_set/acoustics/d_squat_resonator/links/rev_d_print_layout.step
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

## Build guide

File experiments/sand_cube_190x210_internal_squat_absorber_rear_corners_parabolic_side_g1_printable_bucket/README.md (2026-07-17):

# Parabolic G1 printable bucket and separate baffle

This isolated experimental sibling keeps the complete committed parabolic G1
conformal full system, but changes the enclosure manufacturing split:

- the rear 2-3-2 sand gap is filled to make a solid 7 mm rear wall;
- the side and roof sand cavities remain 2-3-2;
- the main enclosure becomes a rear-bed printable bucket;
- the exact parabolic fairing, black-hole recess, driver collar, and front
  brace roots become a separate front baffle;
- the visible seam follows the exact G1 fairing-to-flat-wall tangent boundary;
- a hidden tapered interface runs from that boundary to a 3.5 mm inset
  perimeter on the driver-collar rear plane;
- 0.30 mm hidden fit clearance fades to zero at the visible seam.

The baffle's driver collar and inset perimeter are coplanar for printing.  The
worst corner of the tapered interface is 40 degrees from the print axis, so it
does not require a horizontal support ceiling.

Generated CAD is isolated under:

`build/sand_cube_190x210_internal_squat_absorber_rear_corners_parabolic_side_g1_printable_bucket/`

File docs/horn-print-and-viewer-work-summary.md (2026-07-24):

# Horn Print and Viewer Work Summary

This documents the CAD and print-prep work captured in the current Codex
worktree before merging it back to `main`.

## Scope

The work focused on making the JMLC horn, its support strategy, and the horn
mount easier to print and inspect locally.

Major additions:

- Custom FDM support learnings in `docs/custom-fdm-support-learnings.md`.
- Horn support experiment geometry in `src/features/horn_support_experiment.py`.
- Mouth-down horn and cradle generation in
  `scripts/generate_horn_mouth_down_experiment.py`.
- Upright horn support and accordion/corrugated support generation in
  `scripts/generate_horn_support_experiment.py`.
- Bambu project generators for horn support, mouth-down horn, and OSS horn
  mount workflows.
- OSS horn mount thinning utility in `scripts/thin_oss_horn_mount.py`.
- Additional OCP viewer targets in `src/show_model.py` for horn support and
  mouth-down experiments.
- Static OCP viewer generator in `scripts/generate_static_ocp_viewer.py`.

## Static OCP Viewer

The live OCP viewer sometimes loaded the bundled blue `OCP` logo and missed the
model payload because the browser websocket registration completed after the
Python sender had already pushed the CAD data.

To avoid that timing issue, `scripts/generate_static_ocp_viewer.py` imports a
STEP file, tessellates it with the same OCP/three-cad-viewer stack, and writes a
static viewer page with the model payload baked in.

Default command:

```bash
MPLCONFIGDIR=.cache/matplotlib \
.venv/bin/python scripts/generate_static_ocp_viewer.py
```

Default input:

```text
build/final_system/final_sand_cube_horn_system.step
```

Default output:

```text
build/static_ocp_viewer/viewer/index.html
build/static_ocp_viewer/model-data.js
```

Serve the generated viewer locally:

```bash
cd build/static_ocp_viewer
python3 -m http.server 3939 --bind 127.0.0.1
```

Then open:

```text
http://127.0.0.1:3939/viewer/
```

## Print Strategy Notes

The print work moved through several support strategies:

- PETG and later Bambu Support for PLA as release-interface material.
- A custom corrugated/accordion support ring for the upright horn.
- Wider support contact under the horn underside where the outer horn portion
  grows before meeting the throat-side horn geometry.
- Mouth-down horn printing with a sacrificial cradle and support interface to
  reduce visible top-surface stepping on the horn mouth.
- Rear mount geometry changes toward a smoother hourglass profile and
  serviceable nut access.

The practical lesson was that support geometry must be printable first, not just
mechanically plausible. Thin isolated support paths and wet support filament can
fail before the horn even starts. Larger continuous contact patches, simpler
paths, and controlled support-interface material are more important than
minimizing every gram.

## Merge Notes

The work was developed in a detached Codex worktree on top of:

```text
8fa04b5 Add local CAD viewing workflow
```

The intended merge target is local `main`.

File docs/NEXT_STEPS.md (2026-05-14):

# Next Steps

## Phase 0: Repo and Tooling

1. Create the GitHub repository and push `main`.
2. Install `uv`. Done locally via Homebrew.
3. Sync Python dependencies. Done locally with Python 3.12.
4. Verify local imports for `build123d`, `bd_warehouse`, and `ocp_vscode`. Done
   through the first enclosure build.
5. Decide whether build123d-mcp is part of the first working loop or a later
   enhancement.

## Phase 1: Dimension Lock

1. Download and archive the E150HE-44 and E180HE-PR datasheets.
2. Update `params.py` with verified driver and passive radiator dimensions.
3. Add a short BOM document with current live prices and links.

## Phase 2: CAD Skeleton

1. Implement a buildable dual-skin cube. Done.
2. Add diagnostics for bounding box, volume, mass estimate, validity, and solid
   count. Done.
3. Export STEP first, then verify 3MF export in the local build123d version.
   Done with build123d `Mesher`.

## Phase 3: Risky Features First

1. Recessed baffle revolve.
2. Driver and PR cutouts.
3. Reinforcement rings and bonded insert collars.
4. Bracing posts and corner gussets.
5. Connector, strain relief, and fill port.

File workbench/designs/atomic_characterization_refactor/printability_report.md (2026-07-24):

<!-- Generated by render_phase_a_reports.py from atomic_manifest.json. Do not edit by hand. -->

# Printability characterization

Authority: `print_contracts` in `atomic_manifest.json`. These are characterization records, not geometry changes.

| Part/variant | Intended bed contact | Build direction in design coordinates | Seating/adhesion evidence | Current risks | Later work |
|---|---|---|---|---|---|
| Variant R bucket | rear exterior face near Y=+115 after reorientation | -Y | reference contains a broad rear face; exact flatness, footprint and brim clearance are not frozen | front collar and seam are late-build geometry<br>bulkhead wedges and longitudinal rails may create unsupported ledges<br>support removal through front must remain possible<br>sand/fill passages must not trap material | measure bed face and flatness<br>quantify overhangs/bridges<br>slicer trial<br>protect rear datum |
| Variant R baffle | narrow full-width lower edge near Z minimum | +Z | brim assumed; selected STEP documents a flat full-width contribution but a stable continuous bed-contact face/area was not independently proven | tall slender part<br>driver/fairing overhangs<br>small seating footprint<br>visible-layer and strength direction sensitivity | define minimum seating width<br>measure face/edge flatness<br>brim keepout<br>slicer and physical adhesion test |
| Variant I enclosure | future perimeter around open bottom near Z=-95 | +Z | no current geometry; historic integral references are closed-bottom removable assemblies | front fairing and braces may become unsupported<br>support removal must remain accessible through bottom<br>hatch boundary could weaken bed footprint<br>sand/air traps | design and measure open-bottom perimeter<br>reserve hatch datum<br>grow braces gradually<br>prove support-removal path |
| Variant I hatch | not designed | not assigned | none | seal and flatness<br>separate-part warping<br>service access | future product-design task only |

Physical-print behavior remains uncertain until slicer and printed-part evidence exist. No support, brace, seam, or hatch geometry was corrected.

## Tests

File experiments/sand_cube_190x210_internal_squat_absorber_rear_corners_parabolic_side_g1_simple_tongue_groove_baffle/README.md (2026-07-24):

# Variant R — sculpted removable front with flat-bottom baffle

This leaf experiment is the accepted parameterized Variant R compatibility
adapter for the bucket and removable front baffle. The production owner under
`src/enclosure_family/variant_r/` uses the continuous exact-edge donor directly
and changes only the baffle sub-sole needed for a planar printing base.

The owning generator monkeypatches inherited joint hooks only while building
and restores every changed hook and parameter in `finally` blocks. Generated
CAD remains under
`build/sand_cube_190x210_internal_squat_absorber_rear_corners_parabolic_side_g1_simple_tongue_groove_baffle/`.

## Stage 1 geometry

- The exact authoritative left, right, top, and corner perimeter B-rep edges
  are reused. Ten protected edges are retained, the four lower-center detour
  edges are removed, and one straight lower edge joins the unchanged bottom
  corner tangencies.
- The continuous flat-bottom donor owns the complete bucket, gasket and visible
  baffle apron. There is no active whole-part horizontal splice and no lower
  baffle-to-bucket material transfer.
- Only baffle material below the single parameter-owned sole at
  `Z = -91.495 mm` is discarded. The exact donor topology has a maximum
  sub-sole band thickness of `0.35532330335 mm`.
- The donor has exactly twelve mirrored, reference-only internal bucket sample
  omissions totaling `0.3032817572227236 mm³` over their 1 mm audit cubes.
  This is the sole authorized material-preservation delta; candidate-added
  material and every baffle/centre-section mismatch remain forbidden.
- The 5 mm × 2 mm weatherstrip contract remains driven by
  `GASKET_CLOSED_GAP_MM = 1.0`.
- Fill passages and their hollow blister supports, sand containment, the
  driver interface, sculpted corner closure, and protected exterior geometry
  remain present.

## Deferred retention

`BUILD_TOP_HINGE = False` and `BUILD_BOTTOM_SCREWS = False`.

The earlier tongue-and-groove hinge and lower-fastener geometry is not part of
the accepted Stage 1 result. Future stages must design and validate retention
against this accepted seam and print-edge baseline, including insertion,
gasket clearance, exterior breakthrough, and assembly-path checks.

## Final validation

Coordinated job
`20260724T174726-variant-r-no-splice-authorized-production-releas-9f64591b8e`
completed successfully in `1594.716 s` at `1,202,077,696` bytes peak RSS,
with clean teardown and twelve atomic outputs.

- bucket STEP SHA-256:
  `7ac00586df7d67a19c5ebaf82c2bccf4069141ea024a7fedc2e85bf6350db5ee`;
- baffle STEP SHA-256:
  `d8da00edcb94654d33b81076d27759bd2fa1049b75493154e26411d5fba30535`;
- review assembly STEP SHA-256:
  `0f04b4abf96d67ecd66a196f325c1cd1c6a1e5d2a9114adc73812961ec347185`;
- validation diagnostics SHA-256:
  `35d2e65b48caa5b5afa71d790011e0eee8ec637d554c901191ac55289c0d099f`.

Every part is one valid solid before and after STEP round-trip; the assembly is
three valid solids and pairwise overlap is zero. Bucket and baffle have zero
old-splice and unrelated full-width lower-apron edges. The exact twelve-point
bucket-only signature passes with no candidate-added material, while all thirty
retained L/R/T edge comparisons remain within `1.4254156828833717e-14 mm`.
Bucket and baffle gasket and lower-land support ratios are `1.0`; the lower
seal is one connected component; fill blockage and unclosed non-fill sand-cap
volume are zero.

The baffle terminates at `Z = -91.495 mm` on one planar
`187.026480 × 17.556411 mm` face of `2280.006033 mm²`, with no trimmed
topology below it. A brim is assumed. CAD does not validate first-layer
adhesion, print stability, material behavior, or the final physical assembly.

The complete evidence record is in
`workbench/designs/variant_r_no_splice_production/`.

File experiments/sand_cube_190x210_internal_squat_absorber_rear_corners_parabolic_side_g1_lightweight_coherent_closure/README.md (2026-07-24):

# Lightweight coherent closure

This isolated sibling preserves the complete exterior, nested seam, driver
collar, recessed top/bottom screws, port, absorber, tower, horn, GX16, and
mounting system from the systemic-joint baseline.

It replaces the internal closure and brace implementation with four coherent
systems:

- a continuous 6.75 mm baffle gasket ring, the preserved driver collar, and
  four broad tapered bed-contact bridges instead of a full 3 mm diaphragm;
- one bucket wall-stack cap, gasket land, and rear-grown ramp sharing the same
  exact perimeter, with only the two intentional sand-fill passages;
- two simple bed-grown M4 nut blocks, each with the shortest straight loading
  slot from the printer-bed gasket/collar face in the screw bore's center plane
  and a coaxial terminal GB6170 hex seat; and
- directly constructed transverse, longitudinal, front-root, rear-cradle, and
  tower-cradle braces cut only by named hardware and airway envelopes.

The installed bucket and baffle are included in the authoritative cabinet
volume. Generated files are written only to the matching directory under
`build/`.

Primary printable STEP files:

- `centered_captive_nut_bucket.step` — bucket, printed rear face down;
- `centered_captive_nut_baffle.step` — removable front baffle; and
- `centered_captive_nut_baffle_finned_variant.step` — optional four-diagonal-
  fin printability variant of the unchanged approved baffle; and
- `centered_captive_nut_baffle_finned_variant_bambu_pla.3mf` — high-resolution,
  gasket-face-down printable mesh with generic 0.4 mm-nozzle PLA guidance; and
- `centered_captive_nut_baffle_finned_variant_x2d_pla_matte_project.3mf` —
  native Bambu Studio X2D 0.4 mm / PLA Matte project with the high-quality
  zero-infill process embedded; and
- `centered_captive_nut_assembled.step` — installed-fit reference.

Use `diagnostics.json` for the authoritative installed volume and tuning. The
standard viewers plus the fill, gasket, screw-tunnel, and nut-slot close-section
viewers are generated beside those STEP files.

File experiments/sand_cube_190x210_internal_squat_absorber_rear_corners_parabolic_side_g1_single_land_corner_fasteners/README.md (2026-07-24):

# Single-land corner-fastener closure

This isolated experiment inherits the complete simplified printable closure and
changes only the removable-front joint:

- one gasket land and one matching bed-grown bucket ramp generated from the
  same perimeter;
- exact circular upper-corner arcs around the hidden sand-fill mouths;
- top and bottom M4 axes moved to the outer land/socket corner;
- compact bucket supports rooted into both the land underside and vertical
  socket wall;
- open baffle reliefs for straight drop-on assembly; and
- deeper, side-loaded square-nut cassettes with a five-millimetre nominal
  load-bearing shoulder.

Generated STEP files, diagnostics, and static viewers are written to the
matching directory under `build/`.

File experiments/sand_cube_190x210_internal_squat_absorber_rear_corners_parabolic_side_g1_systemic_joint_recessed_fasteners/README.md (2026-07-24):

# Systemic joint with recessed fasteners

This isolated sibling keeps the complete parabolic-side G1 enclosure and
replaces the experimental front closure with one coordinated joint on each
printed half:

- one bucket-side system derived from the live 2-3-2 wall stack, with one
  curved gasket land and one continuous printable ramp; and
- one baffle diaphragm from the nested perimeter to the preserved driver
  collar.

There are no independent corner caps, secondary gasket rings, or isolated
baffle webs.

The two M4 fasteners cross the dry outer corner of the joint at 48 degrees
from the top/bottom face normal. Their
head pockets are recessed inside the unchanged top and bottom exterior, and
their compact sleeves are clipped to the authoritative enclosure envelope.
The 9.8 mm pockets allow up to a 9 mm conventional M4 head with assembly
clearance. Each side-loaded square nut sits 6.59 mm behind the baffle bed and
loads against a separate 5 mm structural backstop.

Generated files are written only to the matching directory under `build/`.

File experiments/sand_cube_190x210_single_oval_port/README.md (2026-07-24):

# 190 x 190 x 210 mm all-circular 39 Hz port study

This is an isolated fourth Sand Cube bass-alignment experiment. It leaves the
straight, single-U, and twin-inlet variants unchanged.

The enclosure is 190 mm wide, 210 mm deep, and 190 mm high. The side, roof,
and rear panels use a concentric rounded 2-3-2 mm skin / sand / skin stack.
The bottom is an untouched solid 7 mm plate and the contoured front keeps the
solid construction needed by the black-hole recess. The rounded wall layers
follow R8 / R6 / R3 / R1 surfaces from the exterior through to the acoustic
face, so the sand gap does not break through the exterior edge radii.

The acoustic airway is circular everywhere. Its constant-area bore is
39.243 mm in diameter (1,209.5 mm2), preserving the area of the earlier
44 x 35 mm oval while reducing wetted perimeter and eliminating section roll.
The low circular inlet is centered at (-61, -27, -62.763) mm and faces the
front of the acoustic cavity. It has 48.817 mm of axial breathing room to the
driver-seat plane, or 1.244 equivalent diameters, plus 1.463 mm lateral print
clearance to the left acoustic wall. A 15 mm circular flare feeds the constant
bore.

The route uses three controlled pieces: a 100.826 mm circular-plan sweep with
a 77.871 mm centerline radius and 74.186-degree turn, one rotated 70 mm-radius
quarter bend, and a 106.474 mm degree-eight upper drift. The first two curves
meet at an exact common tangent; the drift stays in one vertical plane, rises
monotonically, and never crosses or reverses relative to the centerline. The
round lower tube has a 3 mm wall and sits tangent on top of the inner floor at
z=-88 mm. No port-shaped channel or relief is cut into the floor.

The visible riser is the same circular acoustic profile from the roof to the
outlet. Only the printed wall changes: it thickens from 3 to 5 mm between
z=84 and 87.5 mm, entirely below the inner roof, then remains a constant
49.243 mm outer diameter above the enclosure. The riser centerline is at
y=82.5 mm. Its structural wall stays 0.879 mm ahead of the rear acoustic face
(0.579 mm including installation clearance), so it does not enter the rear
2-3-2 wall. The 58.583 mm circular outlet flare is also concentric with this
straight column.

The lower duct is a separate printable part with four integral mounting ears.
Two fasten downward into 4.8 x 5.0 mm blind insert pockets in the solid floor,
leaving a full 2 mm exterior layer. The rear-right return occupies the material
where a nominal right-side fastener would land, so the other two ears form one
broad left-side wing and fasten rearward into two separated pockets in the
cross-brace. All holes and tabs are relieved by the actual airway solid before
fusion, so no fastener intrudes into the acoustic passage. The nominal 0.30 mm
assembly clearance is clipped above the floor tangent; it never becomes a
floor channel.

The rising tower is installed from inside and is the sole visible
cabinet-to-horn support. There is no exterior mounting flange or secondary
horn stay. A 4 mm plate molded into the tower bears against the underside of
the roof, and a second 4 mm plate bears against the inner rear wall. The plates
form one rigid hidden L saddle. Two upward and two rearward screws pass through
the saddle into four 14 mm solid platforms bridging the 2-3-2 wall stack. The
platforms contain 4.8 x 6.5 mm blind pockets for heat-set inserts or
thread-forming plastic screws.

The rear retains the GX16 connector island, captive-nut pocket, and the pair of
sand-fill entries with their supported curved internal blisters. The redundant
floor bracing is removed: there is no bottom longitudinal rail, and the former
transverse window frame is now a top-and-side U frame. The top and both side
longitudinal rails still project exactly 10 mm into the cavity and meet the U
frame flush. Four identical constant-height front buttresses follow the exact
black-hole surface and fuse directly into its collar. The recess is completed
before those roots are added, so no later subtraction reopens a gap at any of
the four structural joints. A rear horizontal cross-brace remains as the
second cradle for the long internal duct.

The front restores the larger 200 mm design's black-hole driver recess. Its
16.93 mm visible depth is unchanged, while its outer diameter is reduced from
183 to 174 mm around the centered woofer. The contour reaches the tangent line
where the 8 mm cabinet edge radius begins.

The horn is regenerated from Jean-Michel Le Cleac'h's exact 2007 spreadsheet
recurrence rather than uniformly scaled. Holding the 25.4 mm throat,
8-degree throat half-angle, 140-degree terminal rollback, and mouth fixed while
solving for a 10.000 mm shorter acoustic axis gives T=0.49437398987356584,
a 1002.006 Hz profile cutoff, and an 82.382 mm acoustic axial length. The
finished rolled envelope is 190.000 mm and the acoustic mouth is 186.130 mm.
B&C specifies the DE250-8 exit as 25.0 mm, so the horn's 25.4 mm throat is not
an acoustic constriction.

The prior front-flush horn constraint is intentionally released for this
structural pass. The provisional horn envelope projects 4.0 mm ahead of the
cabinet front, its lowest edge remains 5.0 mm above the roof, and the measured
DE250-to-riser clearance is 1.357 mm. Final horn placement can be adjusted in a
later pass without changing the circular port architecture. The mount retains
only the horizontal 2 x M6 on 76 mm BCD pattern and uses three 10 mm round
spokes that wrap around the DE250 with the specified 2 mm nominal envelope gap.

The exact modeled net air volume is 4.570 L after the supplied woofer,
bracing, blisters, GX16 allowance, and complete 0.561 L in-box port envelope
are included. The final centerline is about 491.37 mm and its effective
acoustic length is about 518.54 mm. The outlet height is set for a 39.00 Hz
natural alignment. The modeled response still needs about 5.75 dB of DSP at
39 Hz for the flat moderate-volume goal, so a dynamic limiter and 28-30 Hz
fourth-order high-pass remain part of the design. Final EQ and any small port
trim must come from impedance and near-field measurements of a printed unit.

Run:

```sh
.venv/bin/python experiments/sand_cube_190x210_single_oval_port/generate_sand_cube_190x210_single_oval_port.py
```

Generated STEP files and round-trip diagnostics are written under
`build/sand_cube_190x210_single_oval_port/`. Production does not generate
Viewer or preview artifacts. The cutaway export is retained as downstream
lineage input and includes the enclosure, both tube pieces, woofer, GX16
connector, horn, and DE250. A standalone exact horn STEP is exported as
`sand_cube_190x210_single_oval_port_horn.step`.

After production succeeds, generate the verified sidecar and static review as
separate coordinated jobs:

```sh
.venv/bin/python scripts/cad_review.py sidecar \
  build/sand_cube_190x210_single_oval_port/sand_cube_190x210_single_oval_port_hardware_check.step \
  --kind assembly
.venv/bin/python \
  experiments/sand_cube_190x210_single_oval_port/review_sand_cube_190x210_single_oval_port.py \
  --step build/sand_cube_190x210_single_oval_port/sand_cube_190x210_single_oval_port_hardware_check.step \
  --kind assembly
```

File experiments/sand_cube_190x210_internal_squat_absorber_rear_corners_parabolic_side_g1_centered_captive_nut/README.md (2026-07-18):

# Centered captive-nut closure experiment

This isolated child of the committed nested-seam closure concepts keeps the
authoritative unsplit parabolic exterior, continuous 5 x 2 mm gasket, hidden
upper hooks, full internal assembly, and validated port system.

The lower closure is one centered M4 screw rising rearward at 10 degrees from
the bottom normal.  Its 8.5 mm head is fully recessed by 0.25 mm in a true
9.2 mm angled flat-bottom counterbore, rather than a vertical pocket with an
incorrect bearing surface.

A hidden 13.0 mm bucket tongue locally doglegs the split so the screw head
bears entirely on the bucket.  A standard M4 hex nut drops edge-on through a
hidden top slot, rotates into its anti-rotation baffle seat, and bears entirely
on a 12.0 mm baffle-owned load pad.  Tightening therefore draws two different
printed parts together.  Both audited bearing ratios are 100 percent; the
minimum bucket head wall is 1.747 mm and the baffle pad is 1.5 mm thick.

The screw passage and nut trap remain outside the gasket loop with 2.25 mm
minimum dry-side clearance, so the underside opening is not an acoustic leak
path.  The bucket tongue reassigns existing shell material and adds no
exterior blister.  The baffle load pad adds only 14.882 mm3, is hidden on the
dry side, and is rooted into 130.908 mm3 of existing baffle material.

The generated output includes assembled, exploded, true cutaway, local joint
section, bucket-only, and baffle-only viewers plus STEP round-trip diagnostics.

Run with:

```sh
UV_CACHE_DIR=/private/tmp/cad-uv-cache uv run python \
  experiments/sand_cube_190x210_internal_squat_absorber_rear_corners_parabolic_side_g1_centered_captive_nut/generate_sand_cube_190x210_internal_squat_absorber_rear_corners_parabolic_side_g1_centered_captive_nut.py
```

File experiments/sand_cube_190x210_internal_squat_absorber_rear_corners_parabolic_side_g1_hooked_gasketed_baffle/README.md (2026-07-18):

# Hooked, gasketed parabolic G1 front baffle

This isolated experiment inherits the complete solid-rear printable-bucket
system and replaces only its experimental bucket/baffle joint.  The committed
printable-bucket parent and every earlier enclosure remain unchanged.

The closure uses:

- the exact existing parabolic G1 exterior and black-hole/driver collar;
- the printable-bucket parent's exact tangent seam, with fit clearance hidden
  behind the exterior edge;
- a 0.8 mm rounded bucket opening backed by a broad internal shoulder;
- a continuous rounded-square land for 5 mm wide, 2 mm thick foam tape;
- a 1.15 mm modeled closed gasket gap (42.5% nominal compression);
- two discrete, support-free upper hooks recessed below the closed exterior;
- swept receiver pockets in the baffle for a 15 degree closing motion, with
  the complete swept volume kept below a protected top-skin band;
- two angled M4 screws entering from the underside;
- full flush-clipped baffle insert bosses located inside the gasket loop,
  giving each angled insert pocket a continuous reinforced entry wall while
  retaining the same underside access and flat print plane;
- short M5-class heat-set sleeve pockets in the bucket as hollow screw guides;
- M4 heat-set insert pockets in the baffle;
- a locally tapered transverse U-frame that grows from the rear-bed print
  direction at support-free angles, while the already-supported longitudinal
  rails retain their full rectangular section.

The insert pocket dimensions are a prototype contract, not a claim that every
commercial heat-set insert shares the same outside diameter.  Print a fit
coupon and update the explicit constants in the generator for the purchased
hardware before printing the enclosure.

The compressed gasket is fully behind the exact exterior seam.  It does not
create an exposed axial band between the baffle and enclosure.

The bucket still prints with its solid rear face on the bed.  The baffle still
prints with the driver collar and gasket land on the bed.  The gasket shoulder
and hook toe are both below 45 degrees from their print axes, and the two small
angled fastener bores should be fit-coupon tested and may be finish-drilled.

Generated CAD is isolated under:

`build/sand_cube_190x210_internal_squat_absorber_rear_corners_parabolic_side_g1_hooked_gasketed_baffle/`

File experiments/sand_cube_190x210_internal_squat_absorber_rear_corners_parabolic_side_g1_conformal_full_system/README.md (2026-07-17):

# Parabolic G1 conformal full system

This isolated sibling combines the committed parabolic/conformal bare shell
with the complete validated rear-corner enclosure assembly.

The front exterior, black-hole recess, driver collar, and conformal inner wall
come from:

`sand_cube_190x210_internal_squat_absorber_rear_corners_parabolic_side_g1_conformal_inner_wall`

All other enclosure and system features continue to come from the authoritative
rear-corner baseline, including the internal brace network, GX16 interface,
sand-fill blisters and bores, roof/tower interface, removable port, rear-flush
squat absorber, serviceable exterior tower and flare, horn, DE250 envelope, and
their existing clearance checks.

The four front brace roots are adapted only at the new conformal interface:
each retains the original 10 mm rail section and 1 mm R79 collar-land embed,
but begins at the conformal wall's rear transition plane so no brace material
splits or prints through the exterior fairing.

The cutaway is a true X <= 0 geometric half-shell combined with the complete
internal tube, absorber, tower, driver, GX16, horn, and DE250 reference set.

Generated files are isolated under:

`build/sand_cube_190x210_internal_squat_absorber_rear_corners_parabolic_side_g1_conformal_full_system/`

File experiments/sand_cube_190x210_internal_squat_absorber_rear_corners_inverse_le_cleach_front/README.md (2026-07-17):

# Inverse Le Cléac'h front-profile solver

This isolated study solves a virtual parent horn for the authoritative
rear-corner enclosure without generating CAD geometry.

The calculation calls the repository's direct transcription of Jean-Michel
Le Cléac'h's 2007 `pavillon_JMLC.xls` recurrence (workbook cells B24:H4028).
It does not use the faster exploratory JMLC approximation.

The default solve fixes the virtual parent throat to the authoritative
variant's existing 130.5 mm woofer opening and a 60 degree throat half-angle.
For each requested corner
pullback it solves cutoff frequency and the spreadsheet `T` parameter so that:

- the unique 90 degree/frontmost crest is at the existing 87 mm black-hole
  radius; and
- the actual R8 cabinet diagonal corner is pulled back by the requested amount.

Run from the repository root:

```bash
.venv/bin/python experiments/sand_cube_190x210_internal_squat_absorber_rear_corners_inverse_le_cleach_front/solve_inverse_le_cleach_front.py
```

Use `--corner-pullbacks` to explore other values. Results and profile plots are
written to the matching isolated directory under `build/`.

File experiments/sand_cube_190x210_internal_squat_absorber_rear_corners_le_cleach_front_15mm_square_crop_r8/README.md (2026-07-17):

# Square-Cropped Le Cleac'h Front with Post-Trim R8 Blend

This isolated enclosure-only study fixes the exposed legacy-fillet crescent in
the first 15 mm Le Cleac'h preview by reversing the construction order:

1. Generate the exact Le Cleac'h 2007 surface beyond the raw 190 x 190 mm
   square.
2. Cut that surface into a sharp square cabinet.
3. Apply the cabinet edge blend to the new three-dimensional perimeter.

The nominal R8 blend is evaluated at 7.999 mm because an exact 8.000 mm
rolling-ball fillet is mathematically tangent to the unchanged 87 mm
black-hole crest and degenerates in OpenCascade. The 0.001 mm relief is below
manufacturing resolution while keeping the operation robust.

The virtual horn is inverse-compensated so the *finished*, post-fillet physical
corner is 15 mm behind the black-hole crest. Functional assemblies are omitted
for this aesthetic preview, and the authoritative rear-corner experiment is
unchanged.

Run:

```sh
../../.venv/bin/python generate_sand_cube_190x210_internal_squat_absorber_rear_corners_le_cleach_front_15mm_square_crop_r8.py
```

Outputs are written to the matching directory under `build/`.

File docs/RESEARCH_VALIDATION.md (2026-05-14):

# Research Validation

Date: 2026-05-14

This file validates the supplied playbook before the CAD work starts. The
short version: the overall design direction is strong, but several dimensions,
tool assumptions, and BOM costs need correction before committing geometry.

## High-Confidence Keepers

- Use code-CAD with build123d and keep parameters in source control.
- Build the baffle recess as a revolved profile rather than chasing fragile
  post-boolean edge fillets.
- Use a point-like bracing strategy in the sand void: posts, collars, corner
  gussets, and local reinforcement rings.
- Prefer a permissive MIT license for a forkable maker repo.
- Validate passive radiator dimensions before CAD. This is not optional.

## Corrections Before CAD

- The Dayton Epique E180HE-PR is the right family match, but the official
  mechanical drawing is more useful than the abbreviated spec sheet for CAD.
  Use `pr_cutout_dia = 151.5`, `pr_overall_dia = 181.5`,
  `pr_recess_depth = 6.0`, `pr_bolt_circle_r = 84.75`, `pr_screw_count = 6`,
  and `pr_depth = 54.0` unless a newer official drawing says otherwise.
- Current Parts Express public pricing for the E180HE-PR appears much lower
  than the report's roughly $100 estimate, so the BOM should be recalculated.
- The E180HE-PR's published Vd is 258.59 cm3. Dayton's own product page says
  passive radiator displacement should generally be at least 2x the active
  driver Vd. The E150HE-44 spec sheet lists Vd as 139.7 cm3, so one E180HE-PR
  is close but slightly under that 2x rule. This is acceptable for a prototype
  with DSP limits, but it is a real output-risk note.
- The build123d 3MF export API needs a hands-on check. Current documentation
  says 3MF and STL mesh export are handled by `Mesher().write(...)`, while the
  report uses `export_3mf(...)`. Do not bake `export_3mf` into scripts until it
  imports in the local environment.
- `uv` is not installed on this Mac yet. The repo can still be scaffolded, but
  setup should include installing `uv` before dependency sync.
- The Claude-specific files in the report should be translated to Codex-era
  project guidance. This repo uses `AGENTS.md` as the starting point.
- The Polymaker material recommendation needs a current purchase check.
  Polymaker's current public pages show PETG product-line changes, so the
  practical recommendation may become Polymaker PETG or Bambu PETG-HF rather
  than legacy PolyLite PETG.

## Open Questions

- Confirm Dayton E150HE-44 physical depth against the mechanical drawing and
  actual mounting direction before implementing the front/rear internal
  clearance. The sourced product page and spec sheet agree on 122 mm cutout,
  152 mm OD, and 140 mm bolt circle; depth still deserves a physical sanity
  check because the driver and PR nearly consume the 167 mm internal span.
- Check acoustic volume before freezing the 203 mm cube. The nominal inner
  cavity is roughly 4.66 L before driver, PR, bracing, and rings. Dayton's
  product page lists a 0.15 ft3 sealed recommendation for the E150HE-44, about
  4.25 L, so the design is in the neighborhood but not spacious.
- Verify rear assembly clearance with physical parts. The E150HE-44 is
  rear-mounted and must pass through the rear PR opening before the PR is
  installed. The current CAD uses a 156 mm rear service aperture under the
  externally mounted PR flange because the sourced 151.5 mm PR cutout is too
  tight for a 152 mm driver OD once tolerances are included.
- Confirm whether build123d-mcp is installable and currently maintained enough
  to trust for this project. It should be treated as optional until installed.
- Decide whether the first CAD milestone exports STEP only, or also attempts
  3MF immediately after local API verification.
- Test one printed M14 x 2.0 thread coupon before committing to a printed fill
  plug for the full enclosure.
- GX16-4 panel connectors use a nominal 16 mm mounting hole. The current CAD
  uses a shallow outside flange recess, leaves a 3 mm rear panel land, then
  opens a short captive hex pocket inside the rear cap so the nut can be held
  from the PR/service opening without cutting the hex through the exterior.
- Use coarse printed fill-port threads. The current CAD uses M14 x 2.0 because
  it is large enough for PETG/FDM printed threads while staying proportionate
  to the 12 mm sand void.

## Source Links

- Dayton Audio Epique E180HE-PR product page:
  https://www.parts-express.com/Epique-E180HE-PR-7-carbon-fiber-Cone-Passive-Radiator-295-114
- Dayton Audio Epique E180HE-PR spec sheet:
  https://www.daytonaudio.com/images/resources/295-114--epique-e180he-pr-spec-sheet.pdf
- Dayton Audio Epique E150HE-44 product/spec source:
  https://www.parts-express.com/Dayton-Audio-Epique-E150HE-44-5-1-2-DVC-MMAG-Subwoofer-295-102
- build123d import/export documentation:
  https://build123d.readthedocs.io/en/stable/import_export.html
- build123d operations documentation:
  https://build123d.readthedocs.io/en/stable/operations.html
- Bambu Lab PETG HF filament guide:
  https://us.store.bambulab.com/products/petg-hf
- Polymaker PolyLite PETG product page:
  https://polymaker.com/product/polylite-petg/

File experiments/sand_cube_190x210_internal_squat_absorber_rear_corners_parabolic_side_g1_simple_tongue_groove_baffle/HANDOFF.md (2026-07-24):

# Two-Variant Enclosure Closure — Handoff & Course Correction

> **2026-07-24 supersession note:** The Variant R seam and print-edge course
> correction described below is now resolved in production source. The exact
> sculpted left/right/top edge geometry is retained, the continuous flat-bottom
> donor is used without a whole-part splice or lower material transfer, and
> only the baffle sub-sole is discarded at `Z=-91.495 mm`. The exact twelve
> internal bucket-only micro-omissions are the authorized no-splice delta.
> Top-hinge and lower-fastener work remains deferred, so the retention sections
> below are historical context and future-design input rather than claims about
> the current accepted geometry. See
> `workbench/designs/variant_r_no_splice_production/` and this experiment's
> `README.md` for the current measured status.

Status: **Variant A geometry builds green but is physically wrong and must be re-done with the corrected architecture below.** Read this whole file before touching code. A ready-to-paste brief for a fresh agent is in `NEXT_AGENT_PROMPT.md` (same dir).

---

## 1. The vision — two variants, identical visible exterior, different serviceable face

Both variants keep the **same sweeping exterior**: parabolic-side G1 front fairing (edge-midpoint pullback 8.0 mm / corner pullback 15.0 mm), superellipse sides, 4 mm rear roll, `edge_fillet_r = 8.0`; body ~190(w) × 210(d) × 190(h) mm.

- **Variant A — "front baffle hatch":** the front baffle is a **removable** part; you service the driver/interior by taking the baffle off. Baffle prints **vertically** (flat bottom base + brim). Retention = a continuous **top tongue-and-groove hinge** (pivot the baffle in) + **2 bottom captive-nut screws**. *(This is what was attempted — see §3-4.)*
- **Variant B — "bottom hatch / port":** the front baffle is **integral** with the enclosure (monolithic front); you service via a removable **bottom hatch** (radiused sheet + inner lip + ~8 screws into captive nuts). Prints **bottom-down**. **NOT started.** It has two hard gating problems flagged earlier: (a) the flat ~176 mm interior ceiling can't bridge bottom-down without heavy internal support; (b) the folded port/PR lower duct sits on and bolts to the solid −88 floor, so opening the bottom is a base-level re-anchoring job, not a leaf edit.

---

## 2. THE MISUNDERSTANDING THAT SANK VARIANT A (read first)

The user said **"keep the seam between the baffle and the enclosure the same."** That means the **sculpted nested seam geometry** — the elegant interface + corner sealing the user hand-designed — on **left / right / top**. It does **NOT** mean only the visible outer skin.

What went wrong: chasing "radical simplification," Variant A **deleted the nested seam + the corner-closure panels + the outside-gasket closure + the 45° transition** and replaced them with a plain lip. Enormous effort then went into *proving the outer skin was byte-identical* — i.e. **guarding the wrong invariant** while destroying the interface the user actually cared about. The corner sealing went with it.

### Corrected architecture — a HYBRID SEAM
- **Left / right / top:** restore the **original sculpted seam** exactly (this also restores corner sealing).
- **Bottom only:** the **new flat seam** (needed so the baffle prints upright). The bottom exterior may change **only below the bottom corner**, where it isn't really visible — the user has approved that.

### Corrected APPROACH
Flip from **"delete everything and rebuild minimal"** to **"inherit the original design and surgically change ONLY the bottom (+ the top hinge + the 2 bottom screws)."** Do not delete the seam. This structurally prevents the whole class of error that happened.

---

## 3. What is RIGHT and must be kept
- The **bottom flat faces** on **both** the baffle and the enclosure. The baffle now has a clean face to print vertically from, and the enclosure matches. Keep these.
- The **gasket spec**: purchased weatherstrip 5 mm wide × 2 mm tall, compressed to a **1.0 mm gap**, driven by ONE tunable constant (`GASKET_CLOSED_GAP_MM` at generator line ~122; also patch `source.SHOULDER_Y` — computed at module import).
- The **top tongue-and-groove hinge concept** (continuous bead-in-groove, pivot-in) — the hinge itself validated: −6° pivot, seal-preserving relief (0.0 swept interference at every angle), gasket support stays 1.0. Keep the concept; re-integrate it on top of the restored sculpted seam.

## 4. The issues the user found (annotated viewer screenshots)
1. **Sculpted seam destroyed on L/R/T** — replaced with a plain lip. RESTORE it.
2. **"Not sealed – big gap behind gasket face"** at the corners — the deleted corner closures were *sealing* the corners. Restoring the sculpted seam on L/R/T re-seals them; the **bottom** corners (flat seam) need their own small closure.
3. **"open hole!" — bottom screw bores break THROUGH the enclosure edge.** Unacceptable.
4. **"screw hole hitting gasket face"** — the bores clip the gasket sealing land.
5. **No clear insertion shot** — the pocket doesn't extend to give a straight-down path to actually get a reasonable-length screw in.
6. **"connect the plastic"** — the flat bottom seal is discontinuous (islands between the fastener pockets); must be one connected run.
7. **"weird extra material blocking fill hole"** — clear the obstruction *without* removing the fill blister (the blister is wanted).
8. The bottom now has **less material** (the baffle took some for its flat print face), so the bottom fastener is a tight squeeze.

## 5. The bottom-fastener plan (the user's stated order)
1. **Place the 2 bottom holes so they WORK first:** a clear straight-down insertion shot, clear of the gasket face, not breaking through the edge. The screws are ~45–48° from vertical into **baffle-face-loaded captive M4 hex nuts** (NOT heat-set — pull-out risk). Bucket blister ~12.5 mm, nut pocket 7.4 × 3.6, head recess 9.8 × 3.6, clearance bore 4.5.
2. To lift the entry off the edge, **tilt the screws a bit more perpendicular** to the bottom face — but **bounded** so the bore doesn't climb into the **nut slot**. This "raise the hole vs. miss the nut slot" squeeze is the crux; solve it empirically.
3. **Show the user the placement**, then design the **gasket-face reroute** around the holes: **arc-up → flat → arc-down**, adding matching faces on both the enclosure and the baffle.
4. **Hardest region:** the two **bottom corners**, where the sculpted seam meets the flat bottom, the screw holes, the gasket reroute, and the corner sealing all collide.

## 6. Validation invariants — existing + the ones that were MISSING
Existing (kept green but insufficient): single valid solid; STEP round-trip 1↔1 valid; gasket support ratio ≥ 0.985; exterior identity (fairing area + bbox + skin fingerprint); fill-passage clearance.

**NEW invariants that must be added — their absence let the physical failures pass as "green":**
- **Screw insertion clearance:** a straight cylinder swept along the screw axis from outside must be unobstructed (you can actually insert the screw).
- **No exterior edge breakthrough:** the bore must not open through the outer edge, except within the permitted bottom band (below the bottom corner).
- **Gasket-face clearance:** the bore must not clip the gasket sealing face.
- **Seam identity (L/R/T):** the sculpted seam must match the original — a check on the *seam*, not just the outer skin. (Clip/compare the seam region, or compare seam cross-sections, against the original.)
- **Corner seal:** no gap behind the gasket at the corners (re-instate the `_audit_bucket_front_closure` outside-gasket check that was dropped — it is what would have caught the open corners).
- **Bottom seal continuity:** the bottom seal must be one connected solid.

## 7. Build / environment notes
- All CAD through the coordinator, from the **main repo** (`/Users/jaspercurry/Code/CAD - Enclosure`): `.venv/bin/python -m cad_runner run --repo . -- /abs/script.py`. Concurrency is now allowed within RAM headroom.
- The **full cascade fails at an upstream viewer step** (`simplified._build_robust_viewer_cutaway` → "cutaway did not produce valid solids" on the *inherited* assembly) — pre-existing environment/geometry drift, NOT this work. **Validate via the standalone harness** (pattern: `generate_bucket_front_transition_candidate.py`; here: `validate_simple_tongue_groove_baffle.py`).
- `releases/enclosure_v1/*` is **frozen/read-only**. The V1 baffle is **superseded** (throwaway prototype) — drop the frozen-V1 interference check for new work.
- The Variant A generator inherits a deep chain of **untracked** ancestor generators that live only in the main-repo working tree (the closure generator, the nested-seam / corner-closure / outside-gasket sources, etc.). Work in that tree.

## 8. Key files
- Variant A generator: `experiments/…_simple_tongue_groove_baffle/generate_…_simple_tongue_groove_baffle.py`
- Validator (standalone harness): `…/validate_simple_tongue_groove_baffle.py`
- Build outputs: `build/…_simple_tongue_groove_baffle/{simple_tongue_groove_bucket.step, simple_tongue_groove_baffle.step, validation_diagnostics.json}`
- **Restore the sculpted seam from:** the authoritative closure generator + its `nested_seam_closure_concepts` ancestor, and the `_baffle_corner_closure_panels` / `_outside_gasket_face_closure` / nested-split functions the Variant A generator deleted.

## 9. Process lessons (so the next attempt doesn't repeat them)
1. **Guarded the wrong invariant.** When the user says "keep X the same," pin down *exactly what X is* (here: the seam geometry, not the outer skin) and validate against *that*. Show the specific feature (a **section through the seam**) early — don't infer preservation from a proxy metric.
2. **Over-deleted "cruft."** The sculpted seam + corner closures were **functional**, not cruft. Default to **surgical** change: inherit what works, change only what the goal requires (here, only the bottom, for printing).
3. **Green numbers ≠ good design.** Every invariant was green while the part was physically broken (open corners, screw holes through the edge/gasket, no insertion shot). Invariants must encode **physical assemblability**, not just internal booleans.
4. **Show the user the thing they care about, early and cheaply.** A single seam section shown early would have caught the whole miss on day one instead of after the full build.

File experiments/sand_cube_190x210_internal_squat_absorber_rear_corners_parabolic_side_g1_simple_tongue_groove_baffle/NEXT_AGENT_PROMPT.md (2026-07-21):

# Fresh-context prompt — Variant A rework

Paste the block below into a new session. It is self-contained but points to the full record in `HANDOFF.md` (same directory).

---

We are working in `/Users/jaspercurry/Code/CAD - Enclosure` — a build123d parametric speaker enclosure. First read `AGENTS.md`, then read `experiments/sand_cube_190x210_internal_squat_absorber_rear_corners_parabolic_side_g1_simple_tongue_groove_baffle/HANDOFF.md` in full — it is the authoritative record of a previous attempt that built green but was physically wrong, and it lists the exact issues, the corrected plan, and the mistakes to avoid. Do not skip it.

**The vision — two variants, identical visible exterior, different serviceable face:**
- **Variant A (this task): "front baffle hatch"** — a removable front baffle that prints vertically (flat bottom base + brim); retained by a continuous top tongue-and-groove hinge (pivot in) + 2 bottom captive-nut screws.
- **Variant B (later): "bottom hatch/port"** — integral front, removable bottom hatch, prints bottom-down. Not started; has two gating problems (roof bridging; port/floor re-anchoring) documented in HANDOFF.md.

**The single most important thing to get right:** "keep the seam between baffle and enclosure the same" means the **sculpted nested seam geometry** (the elegant interface + corner sealing the user designed) on the **left, right, and top** — NOT just the visible outer skin. The previous attempt deleted that seam in the name of "simplification" and guarded only the outer skin. Do not repeat this.
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

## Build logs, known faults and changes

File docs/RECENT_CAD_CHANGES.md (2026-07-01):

# Recent CAD Changes

This note summarizes the CAD work brought onto `main` after the 8.5 in Sand Cube enclosure and horn assembly cleanup.

## 220 mm Horn Mouth

- Updated the B&C DE250 JMLC horn target in `params.py`.
- Changed `horn_mouth_outer_d` from `218.37` to `222.463`.
- The calibrated exported horn mouth bounding box is now approximately `220.0 mm x 220.0 mm`.
- The DE250 adapter, flange, bolt pattern, throat, rear spigot, and bracket interface dimensions were left unchanged.
- This change was made to match the newer third-party `220 mm` enclosure envelope.

## STL Connector Recess Experiments

The following derived STL files were created in the Downloads folder for physical fit testing of the GX16/GTX-style rear connector on the third-party unibody enclosure STL:

- `OSS V1.0 - Unibody Main Enclosure - GX16 rear recess 24x5.stl`
- `OSS V1.0 - Unibody Main Enclosure - GX16 inside recess 24x7.stl`
- `OSS V1.0 - Unibody Main Enclosure - GX16 inside recess 24x3p5.stl`
- `OSS V1.0 - Unibody Main Enclosure - GX16 inside recess 24mm 4mm web.stl`
- `OSS V1.0 - Unibody Main Enclosure - GX16 15p8 hole 24mm recess 4mm web.stl`

The latest fit-test version uses:

- Existing outer/front connector recess: `20.0 mm` diameter.
- New inner/back connector recess: `24.0 mm` diameter.
- Remaining material thickness between recess floors: `4.0 mm`.
- Through-hole diameter: `15.8 mm`.

Those STL files are not stored in git because they were generated under `~/Downloads` from an external STL source.

## Third-Party Enclosure Measurements

The inspected third-party unibody enclosure STL measured:

- Overall enclosure envelope: `220 mm x 220 mm x 220 mm`.
- Passive radiator through opening: `156.0 mm`.
- Passive radiator flange recess: `183.0 mm`.
- Front driver/black-hole opening: approximately `130.2 mm`.
- Dual-wall stack: `3 mm` outer skin, `12 mm` void, `3 mm` inner skin.

This is similar to the Sand Cube design intent but not identical to the repo-generated `215.9 mm` enclosure.

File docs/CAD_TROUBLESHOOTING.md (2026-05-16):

# CAD Troubleshooting Notes

This project uses Build123d/OpenCascade to generate exact CAD, then imports the
STEP files into Onshape for review. A model can be a valid OpenCascade solid and
still import oddly in Onshape, especially around thickened, revolved spline
surfaces. This file captures the practical checks that have already saved time.

## Current Build Outputs

Run the main generator:

```bash
UV_CACHE_DIR=.uv-cache UV_PYTHON_INSTALL_DIR=.uv-python XDG_CACHE_HOME=.cache \
  uv run python src/enclosure.py
```

The important outputs are:

- `build/sand_cube.step`: enclosure, woofer rear mount, passive radiator mount,
  connector features, fill port, and top reinforcement features.
- `build/jmlc_horn.step`: standalone JMLC/Le Cleac'h horn for the B&C DE250.
- `build/sand_fill_plug.step`: standalone threaded sand plug.
- `build/diagnostics.json` and `build/horn_diagnostics.json`: basic build
  metrics and validity checks.

If Onshape only shows the horn, make sure you imported `sand_cube.step` as well.
The combined horn/cabinet/bracket assembly is not yet a single export.

## Onshape Symptom: Transparent Or One-Sided Horn Surface

Symptoms we saw:

- The horn looked correct from one side but transparent or invisible from the
  other.
- Selecting the inner acoustic face highlighted a face that appeared to belong
  to the outer wall.
- Onshape reported imported-part faults even though local OpenCascade said the
  body was valid.
- A ring or flat shelf appeared visible through the horn wall near the rolled
  mouth.

Most likely causes:

- Flipped or ambiguous face normals in the imported STEP.
- An open surface imported instead of a closed solid.
- STEP entities that Onshape handles poorly for display/import, especially
  `OFFSET_SURFACE` generated by thickening a curved surface.

The known-good horn export that worked in Onshape uses this pattern:

1. Build the horn acoustic surface from the exact JMLC profile.
2. Revolve that acoustic curve into a face.
3. Thicken the revolved face into a printable wall.
4. Convert the resulting horn wall to NURBS/B-spline geometry before STEP
   export.

The later explicit inner/outer meridian-wall version looked mathematically
cleaner, but it reopened the transparent wall issue in Onshape even when the
local OpenCascade checks were clean. The final working hybrid therefore returns
to the thickened-surface wall topology that Onshape liked, then cuts the
adapter/flange with the same JMLC acoustic void instead of a straight cylinder,
so the compression-driver transition stays continuous.

The adapter must meet the horn wall exactly. A small positive radial clearance
in the adapter's JMLC void produced two separate solids: the horn wall and a
valid but disconnected adapter. The downstream `_primary_shape(...)` helper then
kept the larger horn wall and silently discarded the adapter from the export.
Setting that radial clearance to `0.0` produced one valid solid and restored the
adapter in Onshape.

Disabling p-curves reduces duplicate parametric edge data in the STEP file while
preserving the same 3D edge geometry.

## Quick STEP Checks

Check whether the STEP still contains offset-surface entities:

```bash
rg -n "OFFSET_SURFACE|MANIFOLD_SOLID_BREP|ADVANCED_FACE" build/jmlc_horn.step
```

For the current horn, `OFFSET_SURFACE` should not appear after NURBS conversion.

Run the local STEP audit used during debugging:

```bash
uv run python - <<'PY'
from pathlib import Path
from scripts.generate_horn_test_variants import _audit_step
import json

print(json.dumps(_audit_step(Path("build/jmlc_horn.step")), indent=2))
PY
```

Healthy signs:

- `valid: true`
- `self_interference_errors: false`
- `boundary_edge_count: 0`
- `non_manifold_edge_count: 0`
- `counts.solids: 1`
- Horn `face_type_histogram` has no `OffsetSurface`; a mix of `Cylinder`,
  `Plane`, and `BSplineSurface` is expected for the hybrid export.

Warnings:

- `OFFSET_SURFACE` in the STEP: likely Onshape display/import risk.
- Boundary edges above zero: probably an open shell, not a solid.
- Non-manifold edges above zero: likely bad face joining or overlapping faces.
- Negative volume: face orientation or solid orientation is suspect.

## Visual Render Checks

Render local previews with `f3d` before importing into Onshape:

```bash
f3d build/jmlc_horn.step \
  --resolution 1400,1000 \
  --camera-orthographic \
  --camera-view-up=0,0,1 \
  --camera-direction=0,-1,0.25 \
  --camera-zoom-factor=0.8 \
  --background-color=#f4f1ea \
  --color=#777777 \
  --ambient-occlusion \
  --anti-aliasing=ssaa \
  --tone-mapping \
  --grid=0 \
  --axis=0 \
  --filename=0 \
  --notifications=0 \
  --output build/jmlc_horn_side_check.png
```

`f3d` is not a substitute for Onshape import, but it is a fast way to catch
obvious broken geometry before uploading.

## Horn Modeling Rules Learned

- Keep the inner horn acoustic profile exact. It is the thing the sound touches.
- `Solid.thicken(...)` is acceptable for the horn wall only when the result is
  immediately converted to NURBS before STEP export and then verified in
  Onshape.
- The explicit inner/outer meridian-face approach can pass local validity
  checks yet still render as a transparent or one-sided skin in Onshape.
- Keep the adapter acoustic void continuous with the JMLC profile, but do not
  let the adapter correction force a more fragile horn-wall topology.
- Do not add a positive radial clearance between the adapter acoustic void and
  the horn wall. It can prevent the boolean fuse from making one solid.
- Do not blanket-convert the complete horn to NURBS unless a downstream
  importer specifically needs it. Onshape rejected the all-NURBS explicit-wall
  version.
- Use conservative mouth fillets after the main wall is built. Large fillets on
  rolled-back lips are easy to overconstrain.

## Horn Bracket Rules Learned

The horn bracket is a bent sheet-metal part, not a machined plastic-looking
solid. Treat it as one constant-thickness strip:

- Keep the whole bracket at the same material thickness. The current prototype
  assumption is 4 mm aluminum.
- Model the 90-degree bend as a finite-radius bend with a short straight
  continuation into the upright. If the upright starts exactly at the bend
  tangent, STEP viewers can show a visible shelf or hard jump.
- Do not allow the upright to float forward of the clamp stack. In one failed
  revision, `BuildSketch(Plane.XZ)` + `extrude(amount=material_t)` placed the
  upright plate from `-3.552` to `0.448` mm in Y while the horn spigot and
  compression-driver face were at `4.448` mm. That created a visible 4 mm gap
  between the bracket and compression driver.
- After bracket edits, check the actual face planes numerically. The healthy
  state for the current geometry is:
  - bracket front face: `0.448 mm`
  - bracket rear face: `4.448 mm`
  - horn printed spigot rear face / compression-driver mounting face:
    `4.448 mm`
- The bracket throat hole should be oversized. The metal bracket must not add a
  4 mm cylindrical section to the acoustic path. The printed horn spigot passes
  through the bracket and seats directly against the compression-driver face.
- The DE250 mounting holes must be real through-cuts through the vertical metal
  plate, not cosmetic circles. If circles appear but the holes do not pierce,
  first check the plate's Y placement against the cutout-cylinder centers.

Useful clamp-stack diagnostic:

```bash
UV_CACHE_DIR=.uv-cache uv run python - <<'PY'
from pathlib import Path
from build123d import Rot
from params import p
from src.enclosure import build, build_horn, place_horn_above_enclosure
from src.features.bracket import build_horn_bracket

enclosure = build()
horn = Rot(0, 0, -60) * build_horn()
placed_horn = place_horn_above_enclosure(enclosure, horn, clearance=10.0)
horn_bb = placed_horn.bounding_box()
enclosure_bb = enclosure.bounding_box()
target_y = horn_bb.max.Y
bracket_front_y = target_y - p.horn_bracket_t
bracket = build_horn_bracket(
    enclosure_top_z=enclosure_bb.max.Z,
    horn_rear_y=bracket_front_y,
    horn_center_z=(horn_bb.min.Z + horn_bb.max.Z) / 2,
    material_t=p.horn_bracket_t,
    top_bolt_spacing=p.bracket_hole_spacing,
    top_bolt_y=p.bracket_hole_y,
    binding_post_spacing=p.binding_post_spacing,
    binding_post_y=p.binding_post_y,
    acoustic_hole_d=p.horn_bracket_throat_clearance_d,
    horn_bolt_d=p.horn_bolt_clearance_d,
    horn_bolt_3_bcd=p.horn_bolt_3_bcd,
    horn_bolt_2_bcd=p.horn_bolt_2_bcd,
)

print("spigot/driver face Y:", round(target_y, 3))
print("expected bracket front/rear Y:",
      round(bracket_front_y, 3),
      round(bracket_front_y + p.horn_bracket_t, 3))

for face in bracket.faces():
    try:
        normal = face.normal_at()
        bb = face.bounding_box()
    except Exception:
        continue
    if abs(normal.Y) > 0.98 and bb.max.Z > enclosure_bb.max.Z + 30:
        print("upright face Y:", round(bb.min.Y, 3), round(bb.max.Y, 3))
PY
```

## Enclosure Modeling Rules Learned

- The woofer is rear-mounted from inside the cabinet through the passive
  radiator service opening.
- The passive radiator is externally mounted on the rear face and needs a flush
  recess plus heat-set insert holes.
- Sand fill ports must feed only the inter-skin void, never the acoustic cavity.
- Connector islands and fill-port tunnels should be solid plastic where they
  pierce the sand void, so sand cannot leak into the speaker volume.
- Keep generated CAD artifacts in `build/`; commit source and docs, not exports.

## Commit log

2026-05-14 Add initial build123d enclosure model
2026-05-14 Add OCP CAD Viewer integration
2026-05-14 Fix rear-mounted driver geometry
2026-05-14 Model rear-installed driver assembly
2026-05-14 Add recessed passive radiator mount
2026-05-14 Add rear connector and sand fill ports
2026-05-14 Correct rear connector and fill ports
2026-05-14 Move connector island and seal fill ports
2026-05-14 Fix connector pocket and fill port funnel
2026-05-14 Replace fill port post with sloped duct
2026-05-14 Rotate GX16 nut pocket away from PR recess
2026-05-14 Fix sand fill thread lead-in
2026-05-14 Thin rear cap and deepen fill threads
2026-05-14 Tighten GX16 pocket and lower fill ports
2026-05-14 Split driver and PR insert bore depths
2026-05-14 Add hidden top terminal and bracket island
2026-05-14 Increase front cap clearance for driver inserts
2026-05-15 Document CAD import troubleshooting and restore horn flange
2026-05-16 Add CAD baffle experiment generators
2026-05-16 Add black-hole enclosure experiment and bracket assembly
    [Compression DriverDE250.step, Dayton Audio Binding Posts.stp, E150HE-44.step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]
2026-05-16 Align black-hole baffle to E150 driver face
2026-05-16 Add micro-seat clearance for driver inserts
2026-05-16 Add driver insert hardware model
    [M4x6mm_threaded_brass_insert.step]
2026-05-16 Add passive radiator insert hardware
2026-05-16 Correct M4 insert pilot bore diameter
2026-05-17 Organize final enclosure and horn assembly exports
2026-06-02 Add local CAD viewing workflow
2026-07-01 Document recent CAD fit changes
2026-07-01 Document electronics enclosure layout
2026-07-01 Document horn print and viewer work
2026-07-17 Add enclosure port and absorber design variants
2026-07-17 Add parabolic conformal full enclosure system
2026-07-17 Add printable bucket and separate baffle variant
2026-07-18 Improve baffle fastener and brace printability
2026-07-18 Correct sealed baffle seam and insert bosses
2026-07-18 Add centered captive-nut baffle closure variant
2026-07-21 Add Variant A tongue-groove baffle (WIP) + handoff docs
    Variant A of the two-variant enclosure closure: a removable front baffle that
    prints vertically, retained by a top tongue-and-groove hinge + two bottom
    captive-nut screws. Geometry builds green (single solids, STEP round-trip,
    gasket support 1.0, seal-preserving pivot relief) BUT is physically wrong and
    must be re-done with a corrected architecture.
    Key miss (see HANDOFF.md): 'keep the seam the same' meant the sculpted nested
    seam on left/right/top, not just the outer skin -- the seam + corner sealing
    were deleted. Also: bottom screw bores break the enclosure edge + clip the
    gasket face + lack an insertion shot; unsealed corners; fill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
2026-07-22 Add reusable CAD verification core
2026-07-23 Integrate staged CAD verification workflow
2026-07-23 Harden CAD verification integration
2026-07-23 Add canonical CAD working-set map (#1)
    Create the curated enclosure, acoustics, horn, and archive navigation layer while preserving all existing source and generated artifact ownership.
    [bottom_ownership_assembly.step, flat_bottom_baffle.step, full_perimeter_assembled.step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]
2026-07-23 Land portable enclosure inputs and evidence
    [bottom_ownership_assembly.step, flat_bottom_baffle.step, front_baffle_v1_bed_oriented_mesh.3mf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]
2026-07-23 Complete intake dependency provenance
    [intake_manifest.csv]
2026-07-23 Clarify archival recovery dependency boundary
    [intake_manifest.csv]
2026-07-23 fix: preserve rear rail ramp coordinates
2026-07-23 Add organized 190 mm Le Cleac'h horn variants
2026-07-23 Add staged AI CAD workflow feedback gates
2026-07-23 Add verified CAD stage caching
2026-07-23 Integrate staged CAD feedback rollout
2026-07-23 Address CAD rollout review findings
2026-07-23 Record independent CAD rollout acceptance
2026-07-24 docs: bind current Variant R refactor baseline
2026-07-24 refactor: extract enclosure variant ownership contracts
2026-07-24 Archive rollout ledger for clean checkouts
2026-07-24 docs: reconcile current Variant R acceptance evidence
2026-07-24 docs: reconcile final Variant R landing evidence
2026-07-24 docs: record compatibility landing boundary
2026-07-24 Record Variant R bucket material restoration block
2026-07-24 Accept exact Variant R internal bucket delta
